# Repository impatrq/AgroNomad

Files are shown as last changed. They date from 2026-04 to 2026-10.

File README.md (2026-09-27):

<div align="center">
    
# [AgroNomad](https://linktr.ee/agronomad2026)

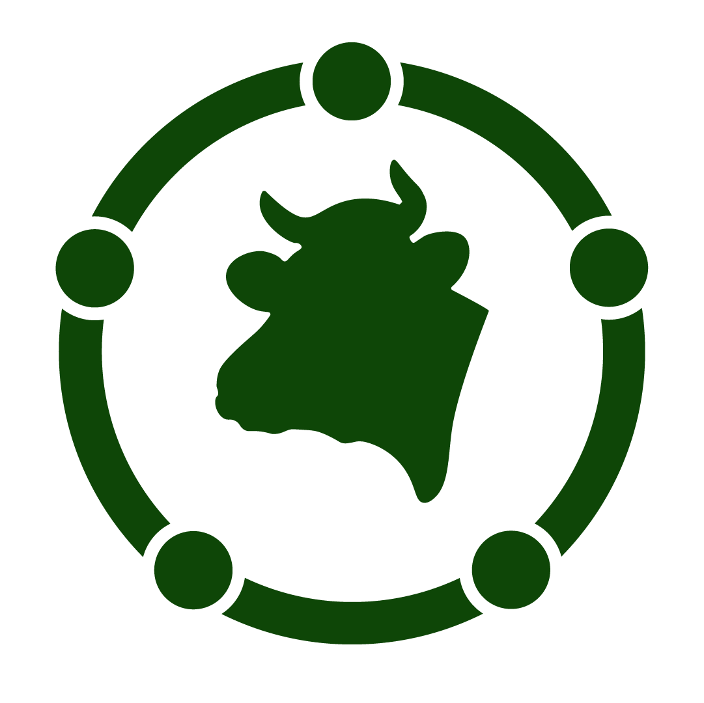
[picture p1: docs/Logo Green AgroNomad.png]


&nbsp;

| Página web | Email | Instagram | Tiktok |
|---|---|---|---|
|[AgroNomad Page](https://agro-nomad-page.vercel.app)|nomadbusiness2026@gmail.com|[@proyecto.agronomad](https://www.instagram.com/proyecto.agronomad/)|[@proyecto.agronomad](https://www.tiktok.com/@proyecto.agronomad)|

### MONITOREO INTELIGENTE DE GANADO 

AgroNomad es un sistema de monitoreo inteligente de ganado que combina collares smart, sensores, posicionamiento GPS y comunicación LoRa para obtener información de los animales directamente desde el campo.

El sistema está compuesto por collares inteligentes, una estación de recepción fija y una interfaz de usuario que permite visualizar y gestionar la información obtenida.

---

## Objetivo

Desarrollar un sistema IoT que permita realizar el seguimiento remoto del ganado, obteniendo información sobre su ubicación, movimiento y diferentes parámetros del animal, y centralizando estos datos en una estación de control.

---

## Componentes del Proyecto  

### AgroNeck

Collar inteligente colocado en el animal.

Se encarga de adquirir y procesar la información proveniente de los sensores y transmitirla mediante LoRa hacia el AgroBot.

### AgroBot

Estación de recepción fija del sistema.

Recibe la información enviada por los AgroNeck y funciona como centro de control para los animales monitoreados.

### AgroServer

Interfaz de usuario del sistema.

Permite visualizar y gestionar la información recibida desde los AgroNeck a través del AgroBot.

---

## Estructura del Proyecto  
**docs/** Documentación e Informes del Proyecto  
**firmware/** Código de los Microcontroladores  
**hardware/** Esquemáticos y PCB  
**mechanical/** Diseños 3D  
**web/** Landing Page del Proyecto  

---

### AgroNeck  
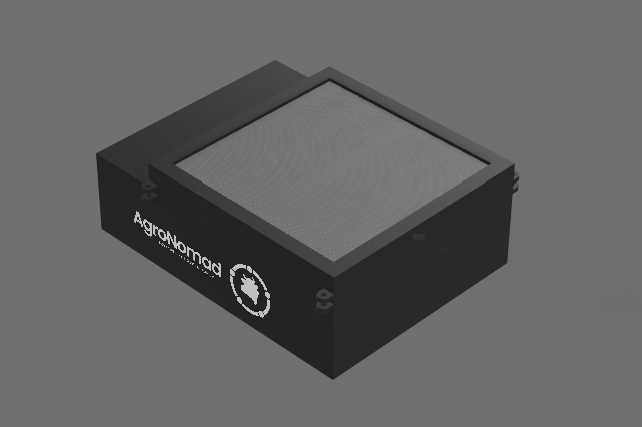
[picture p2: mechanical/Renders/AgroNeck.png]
AgroNeck


### AgroBot
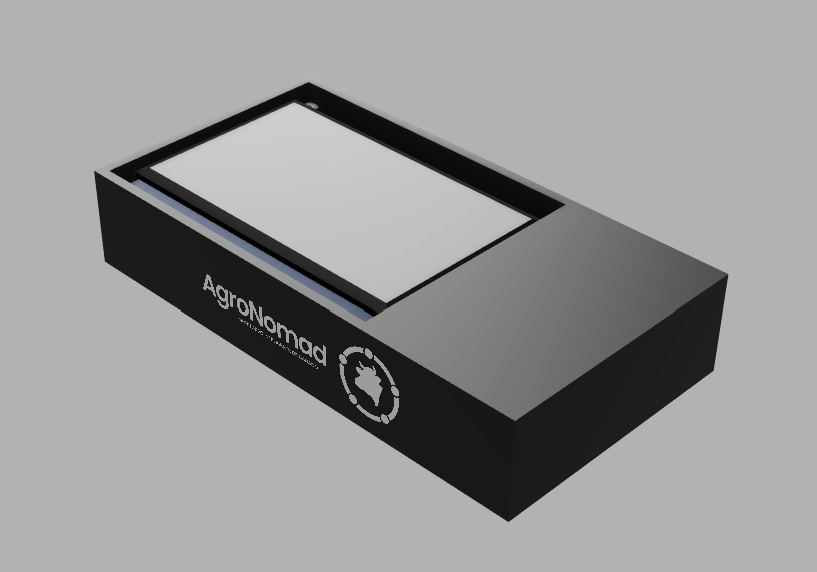
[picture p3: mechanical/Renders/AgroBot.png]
AgroBot


---

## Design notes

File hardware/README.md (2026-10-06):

# hardware
Diseños electrónicos del ecosistema AgroNomad desarrollados en KiCad.

---

### Estructura del Proyecto
**AgroBot/** Estación de recepción fija con Raspberry Pi Zero 2W  
**Cortex/** Placa principal del AgroNeck con ESP32  
**LoraShield/** Módulo adaptador de Lora SMD a THT  
**MLXModule/** Placa de soporte del Sensor de Temperatura MLX90614  
**MOSFETAdapter/** Mini adaptador diseñado para convertir MOSFETs SMD a THT
**Solaria/** Placa de Alimentación Solar y Gestión Energética  

---

## AgroBot

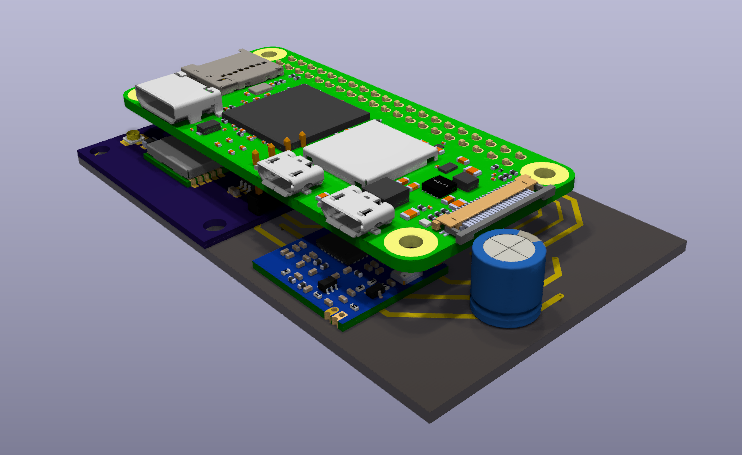
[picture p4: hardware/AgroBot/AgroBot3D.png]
Agrobot


## Cortex

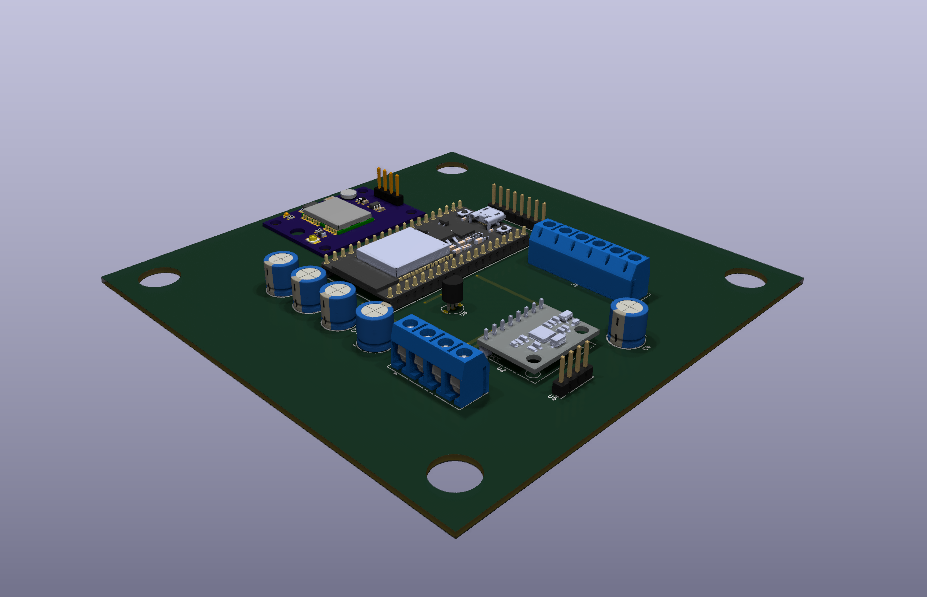
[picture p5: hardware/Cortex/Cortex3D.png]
Cortex


## LoraShield

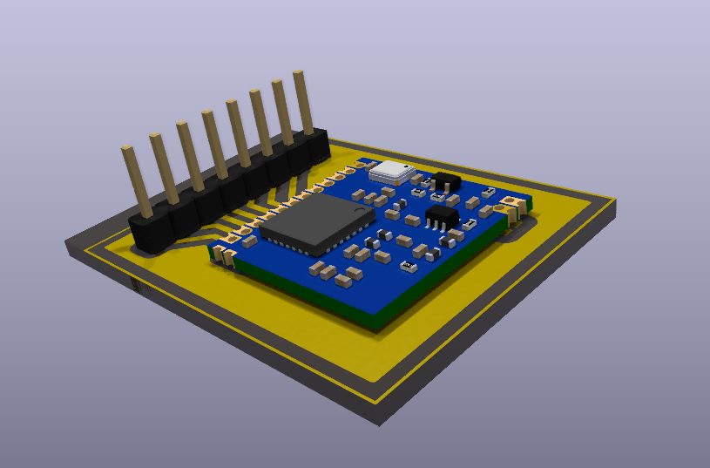
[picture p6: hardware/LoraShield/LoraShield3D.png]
LoraShield


## MLXModule

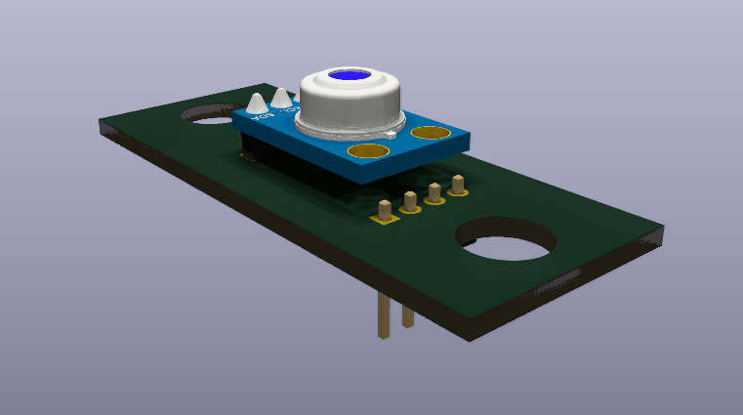
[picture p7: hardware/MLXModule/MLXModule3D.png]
MLXModule


## Solaria

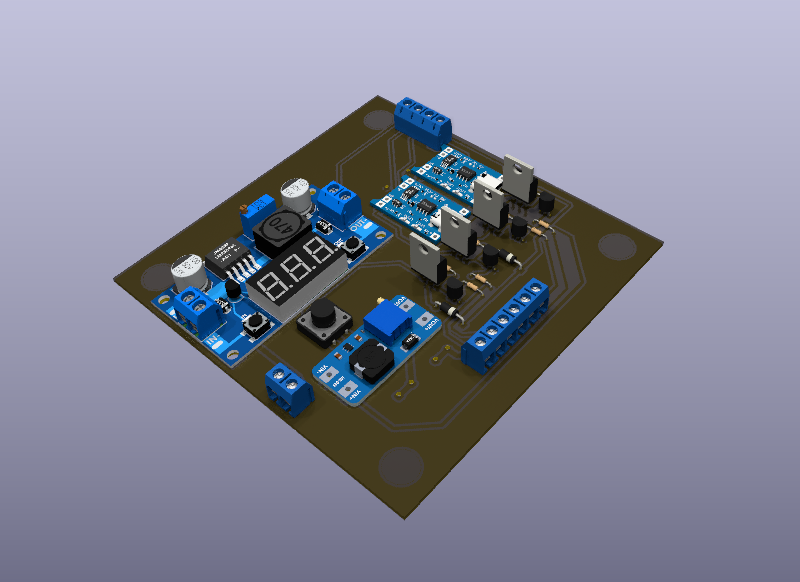
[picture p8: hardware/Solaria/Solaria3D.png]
Solaria


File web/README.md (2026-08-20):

# AgroNomad Web

Landing Page oficial del proyecto AgroNomad.  
Sitio web: https://agro-nomad-page.vercel.app/  

---

### Características

- Presentación del proyecto.
- Descripción del ecosistema AgroNomad.
- Información sobre AgroNeck, AgroBot y AgroServer.
- Integración de redes sociales.

---

## Preview de la Pagina

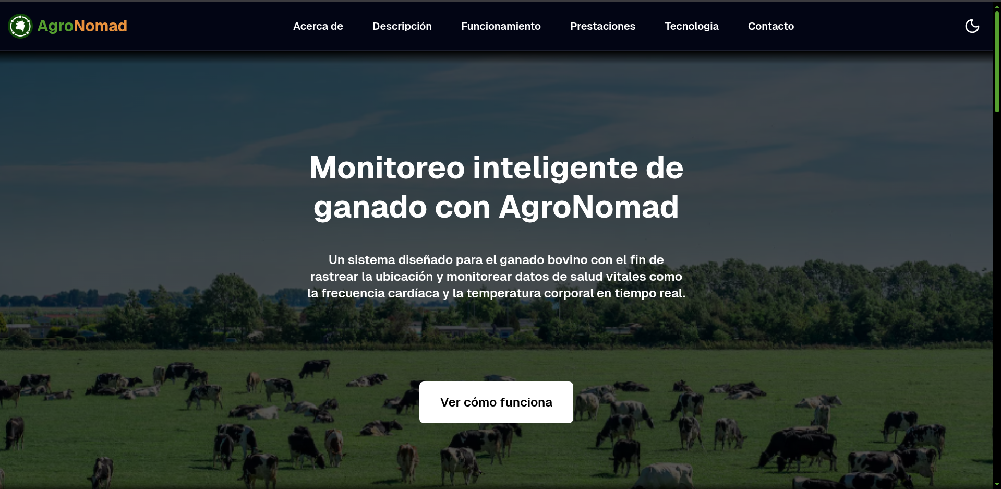
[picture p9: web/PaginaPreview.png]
PaginaWeb
    

---

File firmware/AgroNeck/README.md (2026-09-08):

> AgroNomad 2026

# AgroNeckCode

Código del AgroNeck para la ESP32. Incluye librerías para:

- LoRa
- GPS
- MPU6050
- MLX90614
- LM35

## Funcionando:

- Comunicacion con MPU6050(Aceletometro y giroscopo) y MLX90614(Sensor Temp. Interna). 

- Lectura Sensor LM35

- Comunicacion GPS. 

- Comunicacion LoRA. 

## Pendientes:

-Switcheo de Mosfets entre carga y alimentación

## Luego de realizar Pendientes:

- Buscar un metodo de encriptacion para enviar la informacion de forma segura.

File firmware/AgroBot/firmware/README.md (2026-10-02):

# AgroNomad - Ejemplo de Firmware

Esta carpeta contiene un simulador TCP para pruebas de escritorio y un receptor LoRa para la Raspberry Pi Zero 2 W del AgroBot. El receptor usa el SX1278 de la placa y reenvía la telemetría recibida al backend local.

Este código no es todavía el firmware final de los AgroNeck. Los valores utilizados son fijos y representan los datos que, en una implementación real, deberían obtenerse desde los sensores y el receptor de comunicación del dispositivo.

## Información enviada

Cada mensaje representa una lectura de un AgroNeck e incluye:

- `ID`: identificador único del dispositivo.
- `FIRMWARE_VERS`: versión del firmware.
- `HARDWARE_VERS`: versión del hardware.
- `LAT`: latitud GPS.
- `LONG`: longitud GPS.
- `TEMP`: temperatura registrada.

Ejemplo del formato esperado:

```json
{
  "ID": "COLLAR-01",
  "FIRMWARE_VERS": "1.0",
  "HARDWARE_VERS": "1.0",
  "LAT": -34.707652,
  "LONG": -58.242300,
  "TEMP": "38.4"
}
```

## Simulador TCP de escritorio

La compilación GCC habitual conserva el comportamiento de simulación: se conecta al backend por TCP, envía JSON de ejemplo cada cinco segundos e intenta reconectarse si falla.

## Funciones principales

| Función | Responsabilidad |
|---|---|
| `tcp_connect()` | Crea el socket y establece la conexión con el servidor TCP. |
| `tcp_send()` | Garantiza el envío de todos los bytes del mensaje. |
| `send_collar_data()` | Construye el mensaje JSON con los datos del AgroNeck y lo envía. |
| `main()` | Coordina la conexión, los envíos periódicos y la reconexión. |

## Configuración

En `main.c` se encuentran los valores de conexión:

```c
#define SERVER_IP   "127.0.0.1"
#define SERVER_PORT 4001
```

`SERVER_IP` debe apuntar al equipo donde se ejecuta el servidor y `SERVER_PORT` debe coincidir con el puerto TCP configurado en el backend. Para una prueba local, `127.0.0.1:4001` es la configuración predeterminada.

## Receptor LoRa en Raspberry Pi

El receptor inicializa el SX1278 en recepción continua a 915 MHz, detecta `DIO0`, decodifica la estructura binaria de 14 bytes del AgroNeck y envía el resultado como JSON al backend TCP en `127.0.0.1:4001`.

El mapeo del PCB al header de la Raspberry es:

| Señal SX1278 | GPIO BCM | Pin físico |
|---|---:|---:|
| `MOSI` | 10 | 19 |
| `MISO` | 9 | 21 |
| `SCLK` | 11 | 23 |
| `CS` | 8 | 24 |
| `RESET` | 25 | 22 |
| `DIO0` | 24 | 18 |

La imagen de montaje muestra la Raspberry invertida respecto a la orientación real; el mapeo anterior sigue las redes del PCB y no depende de cómo se vea la foto.

Habilitá SPI en Raspberry Pi OS y compilá ambos ejecutables con:

```bash
cd firmware/AgroBot/firmware
cmake -S . -B build
cmake --build build
sudo ./build/agrobot-lora-receiver
```

El backend debe estar levantado en la Raspberry antes del receptor. `sudo` permite acceder a `/dev/spidev0.0` y `/dev/gpiochip0`; también se pueden configurar los grupos/permisos del usuario para evitarlo. El AgroNeck y el AgroBot deben usar la misma frecuencia y configuración LoRa.

## Compilación y ejecución

Para compilar el simulador TCP:

```bash
gcc main.c -o agro-neck-example
./agro-neck-example
```

Antes de ejecutarlo, el servidor backend debe estar iniciado y escuchando en el puerto TCP configurado.

## Limitaciones actuales

- El simulador sigue usando datos GPS y temperatura de prueba.
- El receptor reenvía la telemetría al backend, pero la recepción de radio debe validarse en el hardware conectado.
- Consultá `../Setup.md` para los pasos de instalación y prueba de extremo a extremo.

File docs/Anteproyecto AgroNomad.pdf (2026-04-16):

Escuela de Educación Técnica Nº7
Taller Regional Quilmes
Prácticas Profesionalizantes: Especialidad Aviónica

# AgroNomad

## Servicio de red portátil para la administración del ganado

## Título del proyecto:

Hemos elegido el nombre AgroNomad porque fusiona nuestra área de enfoque, el área agropecuaria y el concepto de nuestro proyecto, una solución portátil y accesible que cumple su propósito aún en constante movimiento.

## Integrantes:

- DELLA TORRE, Joaquín
- GONZALEZ CAMISCIA, Santiago
- ROMERO DOMINGUEZ, Braulio
- VILLEGAS GONZALEZ, Alejandro

## Objetivo del proyecto:

AgroNomad es un servicio enfocado en brindar al sector agropecuario una herramienta que permita facilitar el monitoreo inteligente del ganado bovino. Nuestro proyecto desarrolla un sistema que permite determinar la ubicación en tiempo real del ganado que se encuentre en la estancia.

Por lo tanto, AgroNomad es una solución escalable, autónoma e integral para el monitoreo inteligente del ganado, combinando análisis de datos, tecnologías de bajo consumo y comunicación de largo alcance buscando mejorar la eficiencia productiva y la seguridad dentro del sector ganadero.

A través de una página web provista por la estación de recepción de datos, el usuario puede visualizar el estado actual de salud de cada uno de los animales —tanto temperatura como pulsaciones por minuto— y detectar y notificar anomalías en caso de notar que los datos vitales no estén dentro del rango normal. Además, registra el camino recorrido por los animales durante el día y monitorea que los animales estén dentro del área perteneciente al propietario.

## Utilidades del proyecto:

La ganadería en Argentina representa un 7,5% de las exportaciones y sigue siendo actualmente uno de los sectores productivos más amplios del país. Sin embargo, enfrenta problemáticas críticas como el abigeato —robo del ganado—, que tiene más de 1200 denuncias anuales únicamente en Santa Fe. A pesar de que existen métodos de detección de abigeato actualmente, son sistemas tardíos en donde el daño ya está hecho. Si bien es un delito penado por ley en Argentina y existe registro de muchos casos, no existe alerta temprana que alerte al dueño de los animales que los mismos han salido del territorio de su estancia.

AgroNomad busca brindar una solución preventiva que les otorgue mayor seguridad a los productores ganaderos, ya que pueden acceder a la ubicación de su ganado constantemente, más que nada a aquellos en los que la cantidad de animales que tienen dificulta la capacidad de monitorear a todos al mismo tiempo. No solo resuelve la problemática de ubicar al ganado sino también de poder tener un registro de cada uno, como su estado de salud y reduciendo la necesidad de supervisión física constante.

## Descripción del funcionamiento:

El ecosistema de AgroNomad se compone, principalmente, de collares inteligentes llamados AgroNeck que se les colocará a los animales que sean parte de la estancia. Estos dispositivos son diseñados para monitorear parámetros fundamentales como el comportamiento del ganado.

Cada collar se encarga de medir las pulsaciones del animal mediante un micrófono MEMS en contacto con el collar que, junto a la implementación de un acelerómetro de 3 ejes, permitirá detectar si el animal está sufriendo alguna anomalía en su comportamiento y determinando si está en estado de reposo o en movimiento. Para detectar si las pulsaciones detectadas por el sensor son los latidos del corazón y no son vibraciones generadas por otras situaciones como por ejemplo, masticar o caminar, los collares poseerán un algoritmo entrenado previamente para cumplir ese propósito.

A través de dos sensores térmicos integrados en el collar se medirá la temperatura del ambiente y la que posee la piel del animal. Un algoritmo definido por la fórmula de equilibrio térmico recibe estas mediciones y permite estimar la temperatura interna del animal.

Un módulo GPS NEO6MV2 será el encargado de recopilar la posición actual del animal y será de ayuda para determinar el recorrido del mismo durante un ciclo diario.

Los datos recopilados irán al microcontrolador ESP32, que será encargado de procesar la información de los sensores. Luego, los enviará mediante un módulo de telecomunicaciones LoRa al AgroBot —estación de recepción de datos— que será instalado donde el propietario esté interesado en conocer los datos del ganado. Además, los collares serán nodos dentro de una red. Se reenviarán información entre sí permitiendo, de esta manera, que si un collar no se encuentra dentro del alcance directo del AgroBot, otro collar cercano actúe como intermediario ampliando la cobertura total de la red.

Los collares contarán con un pequeño panel solar conectado en la parte superior del collar que permitirá disponer de autonomía energética junto a las cuatro baterías de litio.

El AgroBot será una estación fija de recepción que emplea un microcontrolador Raspberry Pi Zero 2W y un módulo LoRa para recibir la información. Además incluirá una pantalla LCD táctil que funcionará como dashboard.

La página web del AgroServer —que, en zonas sin cobertura, es una red wifi local autónoma generada por la Raspberry Pi Zero 2W— permite asignar a los collares un perfil del animal donde se puede cargar —en caso de ser necesario— el nombre, la edad, el tipo de ganado, el estado de sus vacunas y cualquier otro dato necesario. En la página web del AgroServer se podrá visualizar el mapeo del área donde puede permanecer el ganado. Se permitirá seleccionar a cualquier animal en específico y se cargará su perfil como también el estado actual de sus pulsaciones y temperatura. Contará con opciones para revisar las distancias recorridas por los animales y un sistema de alerta cuando no se detecta dentro del rango a uno de los collares.

## Análisis de factibilidad:

Electrónica y diseño de PCB: Se deben diseñar circuitos de tipo PCB para integrar todos los sistemas que van a incluir tanto los AgroNecks como los AgroBots. Los que realizarán los circuitos esquemáticos, los PCBs y la posterior impresión y agujerado serán Joaquín Della Torre y Braulio Romero Domínguez. Santiago

Gonzalez Camiscia estará a cargo del soldado y revisión de funcionamiento de los componentes.

Integración del Software: Para el desarrollo correcto de esta tarea, necesitaremos que todos los miembros del equipo trabajen comunicados entre sí. De esta manera, nos garantizamos que el software integre todos los sistemas y pueda funcionar correctamente en conjunto. Una de las principales tareas del software será establecer la comunicación entre los AgroNecks y el AgroBot y que los datos puedan ser correctamente explayados en el AgroServer.

Desarrollo de AgroServer: Se deberá diseñar la página web con la correcta visualización de los parámetros principales y la accesibilidad de la interfaz. También su integración a la pantalla táctil del AgroBot. Este será un trabajo de Joaquín Della Torre.

Sistema de alimentación solar: La problemática de la autonomía energética la solucionamos implementando un sistema de alimentación a través de baterías recargadas mediante energía solar. El desarrollo de este sistema lo harán Alejandro Villegas Gonzalez y Braulio Romero Dominguez.

Ubicación en tiempo real: Para poder guardar un registro del movimiento de los animales durante el día y determinar su posición como también verificar si está en el rango definido de la estancia, será necesario desarrollar un sistema de ubicación precisa en tiempo real. Esta tarea estará a cargo de Santiago Gonzalez Camiscia y Alejandro Villegas Gonzalez.

Diseño y armado físico de AgroNomad: El desarrollo de los AgroNecks presenta un desafío importante que es el de contar con todos los sistemas descritos anteriormente y a la vez ser cómodo para que los animales no sufran estrés. El diseño de los mismos debe permitir que sean funcionales, ergonómicos y fáciles de colocar. Por su parte el AgroBot debe desarrollarse teniendo en cuenta sus sistemas y que se puedan obtener correctamente los datos. Esta tarea de diseño estará a cargo de Braulio Romero Dominguez.

Sistema de medición de pulso: Será necesario desarrollar un sistema basado en un micrófono MEMS que permita sensar el pulso, como también el entrenamiento del algoritmo necesario para la filtración de otras vibraciones. Este sistema será desarrollado por Santiago Gonzalez Camiscia y Braulio Romero Dominguez

Algoritmo de temperatura: AgroNomad requiere también un sistema que sea capaz de medir la temperatura exterior y la de la superficie de los animales y utilizar estos datos para calcular la temperatura interna. El desarrollo del mismo está a cargo de Alejandro Villegas Gonzalez.

Marketing y Redes Sociales: Los encargados del branding de la marca y su representación en redes sociales serán Alejandro Villegas Gonzalez y Braulio

Romero Dominguez. Su tarea también será contactar con empresas, posibles patrocinadores y exteriorizar el proyecto.

También será responsabilidad de todo el equipo verificar que los módulos y/o componentes a utilizar funcionen de manera correcta, puedan ser integrados con el software y cumplan con las medidas de seguridad para que no sucedan incidentes.

El equipo en su conjunto deberá mantener una comunicación continua entre sí para mantener un desarrollo integral del proyecto y verificar que todos los sistemas puedan funcionar a la vez y en conjunto.

El proyecto es técnicamente viable, ya que los sistemas que se desarrollarán poseen tecnologías accesibles, pero tiene que ser realizado con extrema precisión, ya que su funcionamiento no debe poner en riesgo la integridad física y psicológica del animal.

## Costo del proyecto:

Componentes:

- Raspberry Pi Zero 2w (31,41$USD)

https://www.siranet.com.ar/productos/raspberry-pi-zero-2w/

- LCD Touch 5” HDMI Raspberry Pi (51,97$USD)

https://www.mercadolibre.com.ar/lcd-touch-5-hdmi-raspberry-pi-pantalla-tactil-beaglebone/p/MLA2045601485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 (https://www.mercadolibre.com.ar/lcd-touch-5-hdmi-raspberry-pi-pantalla-tactil-beaglebone/p/MLA2045601485)

- ESP32 DevKit V1 (12,85$USD)

https://tienda.starware.com.ar/producto/placa-wifi-iot-nodemcu-esp-wroom-32-devkit-v1/ (https://tienda.starware.com.ar/producto/placa-wifi-iot-nodemcu-esp-wroom-32-devkit-v1/)

- x2 Módulo Lora SX1278 (16,84$USD)

https://www.todomicro.com.ar/comunicacion/910-modulorf-lora-sx1278-chip-p m1280-con-antena.html (https://www.todomicro.com.ar/comunicacion/910-modulorf-lora-sx1278-chip-pm1280-con-antena.html)

- Módulo GPS NEO6MV2 (4,73$USD)

https://www.todomicro.com.ar/ARDUINO/339-modulo-gps-gy-neo6mv2-con-a ntena.html (https://www.todomicro.com.ar/ARDUINO/339-modulo-gps-gy-neo6mv2-con-antena.html)

- Acelerómetro MPU-6050 (2,65$USD)

https://www.todomicro.com.ar/sensores/176-acelerometro-y-giroscopio-mpu-6 050.html (https://www.todomicro.com.ar/sensores/176-acelerometro-y-giroscopio-mpu-6050.html)

- Sensor de Temperatura MLX90614 (13,73$USD)

https://tienda.starware.com.ar/producto/sensor-de-temperatura-arduino-compatible-gy-906-mlx90614-baa-termometro-infrarrojo/ (https://tienda.starware.com.ar/producto/sensor-de-temperatura-arduino-compatible-gy-906-mlx90614-baa-termometro-infrarrojo/)

- Sensor de Temperatura LM35 (1,99$USD)

https://www.nubbeo.com.ar/productos/sensor-analogico-temperatura-lm35-0c-a-100c-nubbeo/ (https://www.nubbeo.com.ar/productos/sensor-analogico-temperatura-lm35-0c-a-100c-nubbeo/)

- Micrófono MEMS (10,84$USD)

https://www.mercadolibre.com.ar/inmp441-microfono-omnidireccional-interfaz-i2s-inmp441-mems/p/MLA2058636482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 (https://www.mercadolibre.com.ar/inmp441-microfono-omnidireccional-interfaz-i2s-inmp441-mems/p/MLA2058636482)

- Panel Solar 5W (15,96$USD)

https://www.mercadolibre.com.ar/d-cargador-solar-para-camping-con-entrada-tipo-c-w/p/MLA2058280905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 (https://www.mercadolibre.com.ar/d-cargador-solar-para-camping-con-entrada-tipo-c-w/p/MLA2058280905)

- Regulador Step-Down TPS54260 (3,5$USD)

https://www.mercadolibre.com.ar/54260-tps54260-tps54260dgqr-ti-54260-s4260-original-texas/up/MLAU267269638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 (https://www.mercadolibre.com.ar/54260-tps54260-tps54260dgqr-ti-54260-s4260-original-texas/up/MLAU267269638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)

- 4x Bobinas SMD 220uH (10,84$USD)

https://www.mercadolibre.com.ar/inductor-bobina-220-micro-h-smd-potencia-221-12x12x7-mm-17a/up/MLAU312652544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 (https://www.mercadolibre.com.ar/inductor-bobina-220-micro-h-smd-potencia-221-12x12x7-mm-17a/up/MLAU312652544)

- 4x Mosfet IRFZ44N (4,24$USD)

https://www.mercadolibre.com.ar/10-unidades-irfz44n-transistor-mosfet-irfz-44-49a-55v-to220/up/MLAU135565280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 (https://www.mercadolibre.com.ar/10-unidades-irfz44n-transistor-mosfet-irfz-44-49a-55v-to220/up/MLAU135565280)

- 4x Transistores BJT 2N3904 (6,52$USD)

https://www.mercadolibre.com.ar/2n2219a-transistor--08a-75v-ft-300mhz-altern-2n2222a-2n2219/up/MLAU298312241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 (https://www.mercadolibre.com.ar/2n2219a-transistor--08a-75v-ft-300mhz-altern-2n2222a-2n2219/up/MLAU298312241)

arch_layout=grid&position=2&type=product&tracking_id=9ae7a458-33ac-45e 0-ad19-e7b79cd4106f&wid=MLA870238161&sid=search (https://www.mercadolibre.com.ar/2n2219a-transistor--08a-75v-ft-300mhz-altern-2n2222a-2n2219/up/MLAU298312241)

- Diodo Schottky 1N5819 (2,07$USD)

https://www.mercadolibre.com.ar/10-diodos-schottky-1n5819-vishay-40v-1a-do-204ah-alta-frecuencia/p/MLA48092585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 (https://www.mercadolibre.com.ar/10-diodos-schottky-1n5819-vishay-40v-1a-do-204ah-alta-frecuencia/p/MLA48092585)

- Collar de BioCuero (12,92$USD)

https://oymindumentaria.com/productos/cinturon-de-vestir-clasico-eco-cuero/

- x1kg Filamento PLA para Impresora 3D (16,26$USD)

https://printalot.com.ar/productos/filamentos/pla/pla-negro/

Costo por AgroNeck: 103,14$USD

Costo del AgroBot: 84,44$USD

Costo total del proyecto: 171,62$USD

Referencias de páginas de búsqueda:

https://www.todomicro.com.ar/

https://www.mercadolibre.com.ar/

https://tienda.starware.com.ar/

https://www.nubbeo.com.ar/

## Análisis de costo/beneficio:

AgroNomad es una herramienta que busca ofrecer un servicio económico para el sector agropecuario, de una inversión inicial única y sin costos de suscripción mensuales a diferencia de las alternativas disponibles del mercado.

La inversión de 103 USD por collar y de 84 USD para la estación de recepción de datos se justifica con el monitoreo constante que permite realizar. Ante la posibilidad de acceder en tiempo real a la ubicación y el estado de salud de cada animal, se puede optimizar significativamente el tiempo de trabajo reduciendo la necesidad de hacer recorridos físicos extensos dentro del campo. Esto también permite una mayor seguridad del ganado al detectar tempranamente situaciones de riesgo como abigeato o anomalías en los parámetros fisiológicos.

Si analizamos otras soluciones existentes, la mayoría suelen incluir el uso de drones o plataformas con suscripciones mensuales. AgroNomad ofrece una alternativa más económica y autónoma. Las demás opciones suelen requerir costos iniciales elevados o gastos periódicos que dificultan su adopción a largo plazo.

En un campo de 50 animales, si consideramos una vida útil estimada de 5 años, AgroNomad requiere una inversión única de 5234 USD, frente a sistemas basados en suscripciones que, si consideramos una suscripción mensual de 3 USD por animal, implicaría un gasto de 9000 USD en el mismo período. Esto representa una reducción de costos de más del 40%, y elimina la dependencia de otros dispositivos. Para productores que no generen producciones a gran escala, esto es un ahorro significativo.

AgroNomad, por su parte, elimina la dependencia de servicios externos ya que en caso de no poseer internet, genera una red local propia garantizando su funcionamiento aún en zonas sin cobertura. De esta manera, al realizar la inversión inicial, el sistema ya puede operar de manera continua sin generar costos adicionales significativos.

## Diagramas en bloques del prototipo:

## Diagrama electrónico Agro Neck:

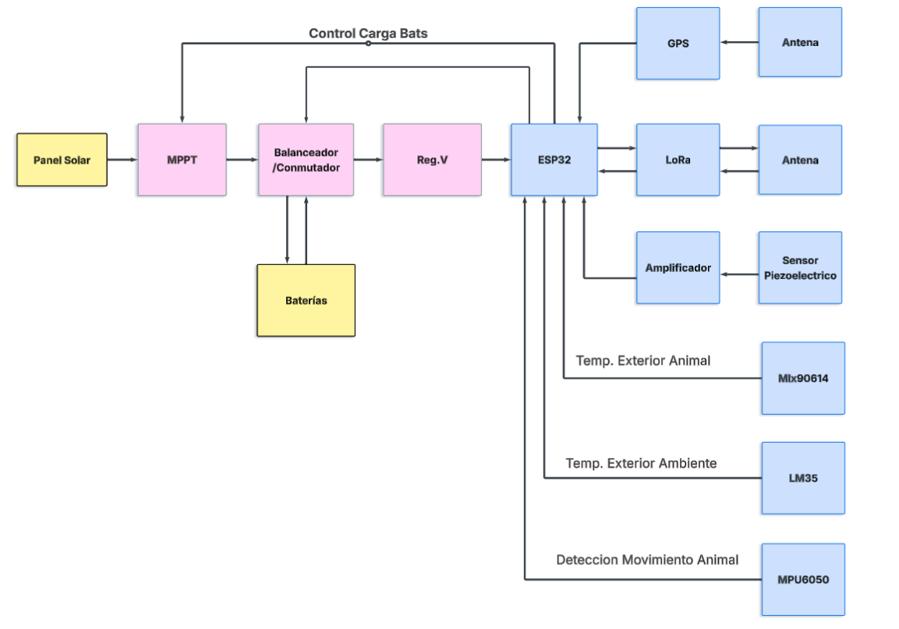
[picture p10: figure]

Panel Solar / MPPT: Se diseñará un circuito sencillo pero a la vez funcional, que permita obtener eficientemente la energía del panel solar instalado sobre el AgroNeck, y entregar todo el tiempo la tensión y corriente necesaria para realizar la carga de las baterías de litio, gracias a la red de retroalimentación que se instalará entre la ESP32 y el bloque conmutador y balanceador que gestiona la carga.

Baterías: Se hará uso de 4 baterías de litio tipo 18650 (3.7V, 2200mAh) para alimentar al AgroNeck, de forma que se encuentre conectadas las 4 independientemente conectadas al módulo Balanceador/Conmutador que junto al ESP32 cumplira funciones de gestión de carga similares a las de un BMS (Battery Management System).

Balanceador/Conmutador: Este módulo electrónico consistirá en un conjunto de transistores BJT que según el control comandado por la ESP32, permitirán realizar la carga y balanceo individual de las cuatro baterías. Este módulo a su vez permitirá elegir qué conjunto de dos baterías en serie alimentará a la ESP32 a través del regulador de tensión.

Regulador de tensión (Reg.V): Se empleará un convertidor Step-Down con el TPS54260 para transformar la tensión proveniente de las baterías a una aceptable para el funcionamiento de la ESP32 y el módulo LoRa(3.3V), para maximizar la eficiencia del consumo energético del dispositivo. Como también se instalará una red de filtro LC y planos de tierra (Ground Planes) para evitar cualquier interferencia que pueda emitir el módulo de fuente Step-Down hacia el módulo LoRa y GPS.

ESP32: Este Microcontrolador se encargará de emplear toda la lógica tanto de la carga de baterías por medio del sistema MPPT (Maximum Power Point Tracking) y el módulo Balanceador/Conmutador, como también la lógica de comunicación y recolección de datos de los sensores de temperatura y de medición de pulsos integrados dentro del collar.

GPS: Se hará uso del módulo NEO6MV2, para la geolocalización de cada NomadNeck —o sea, del animal— físicamente dentro de la red y así poder armar un mapa con la posición de cada uno en la aplicación web.

LoRa/Antena: Este apartado será el encargado de realizar la recepción y transferencia de información de cada NomadNeck, por cada NomadNeck se enviaran datos de pulsaciones cardiacas del animal, su temperatura corporal actual y posición geológica.

MLX90614: Es el sensor de temperatura infrarrojo que se encarga de sensar la temperatura que irradia la piel del animal.

LM35: Este segundo sensor de temperatura se encarga de sensar la temperatura ambiente del exterior, y así junto al dato previo del sensor infrarrojo es posible calcular la temperatura interna del animal.

MPU6050: Se encargará de detectar cuando el animal se encuentra en movimiento, o en qué posición se encuentra, lo que permitirá saber si su estado vital es el normal para la actividad que el animal realiza o si presenta alteraciones en su comportamiento.

## Diagrama Electronico AgroServer:

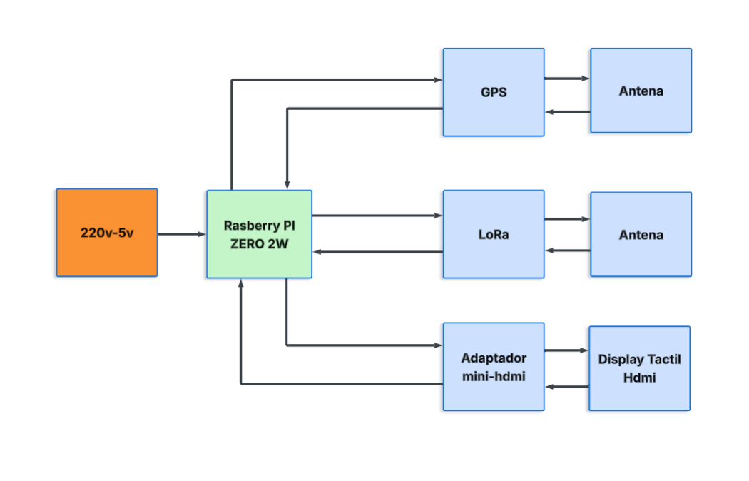
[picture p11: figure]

GPS: Es necesario implementar a su vez un módulo GPS NEO6MV2 mismo al del Agro Neck dentro del Agro Server, ya que esto nos permite la localización del mismo dentro de la red y así poder definir adecuadamente cual es el área física a respetar para una circulación normal de los animales. Significando que fuera de esta área, el animal estaría “escapando” y se alertará inmediatamente.

LoRa: Se utilizará para poder recibir toda la información de cada AgroNeck y si a su vez es necesario enviar información a estos.

Display Tactil Hdmi: Esta pantalla permite al empleador del campo, tener una conexión directa con el servidor web y página web en caso de no disponer de cualquier otro dispositivo como un celular o computadora para hacerlo.

Raspberry Pi Zero 2w: Se hará uso de este microcontrolador ya que dispone de un salida mini hdmi que nos permite conectar una display táctil de buenas prestaciones, como también la capacidad albergar un servidor web en el cual funcionará nuestra aplicación web de monitoreo. El mismo será desplegado en la red wifi local de la cual el empleador disponga, aunque en caso de no disponer de una red que proporcione internet al AgroBot, se creará una red wifi local por medio del microcontrolador para poder hospedar este servidor.

A su vez este microcontrolador se encargará de mantener en funcionamiento un modelo de análisis de datos, encargado de analizar el comportamiento de los animales —temperatura, pulsaciones y camino recorrido— para poder deducir si estos animales poseen alteraciones en su salud.

## Diagrama de tiempo de desarrollo:

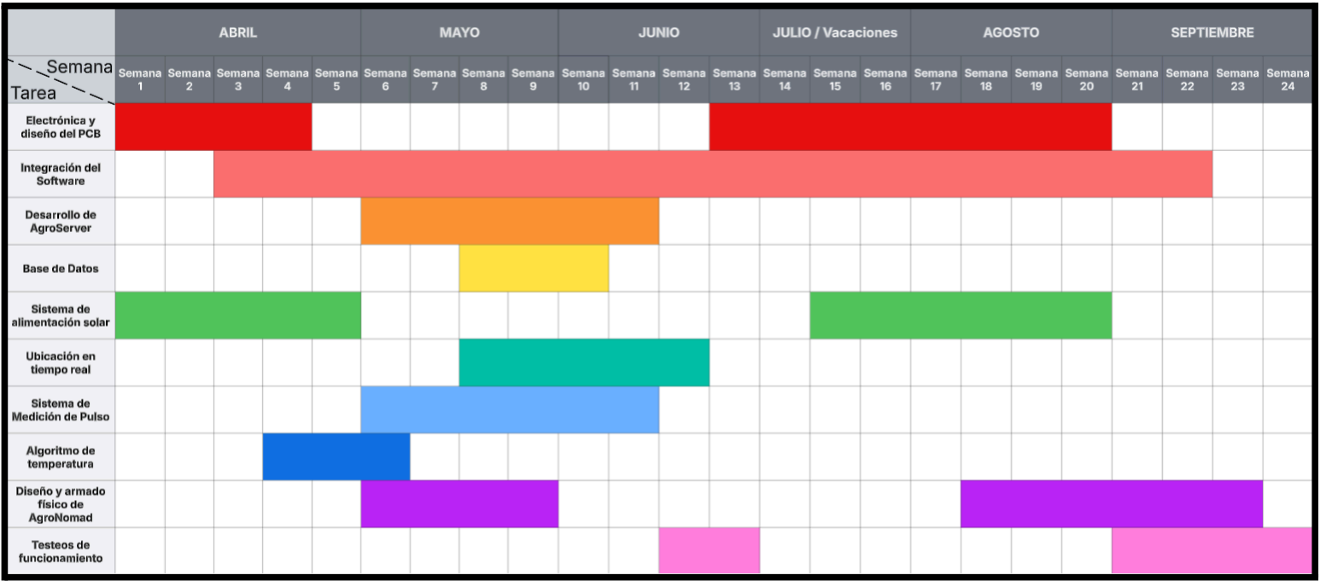
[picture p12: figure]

## Referencias conceptuales:

- ¿Qué es el gps para ganado y sus principales beneficios? -https://zeekgps.com/que-es-el-gps-para-ganado-y-sus-principales-beneficios/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,del%20animal%20en%20tie mpo%20real (https://zeekgps.com/que-es-el-gps-para-ganado-y-sus-principales-beneficios/)
- Collar inteligente para vacas de ganadería extensiva -https://innogando.com/rumi-carne/
- ¿Se le pierden sus vacas en la finca? Estas tecnologías podrían ayudarle a localizarlas -
https://www.contextoganadero.com/tendencias/se-le-pierden-sus-vacas-en-la-finca-estas-tecnologias-podrian-ayudarle-a-localizarlas (https://www.contextoganadero.com/tendencias/se-le-pierden-sus-vacas-en-la-finca-estas-tecnologias-podrian-ayudarle-a-localizarlas)
- Desarrollan un GPS para ubicar las vacas perdidas -https://www.revistachacra.com.ar/informacion-tecnica/18864/
- Sistema circulatorio de cabeza -https://www.anato.cl/00012%20comunidadanato/DraCBorroni/UDM/Morfologia/Clase_10_circulacion_cabeza.pdf (https://www.anato.cl/00012%20comunidadanato/DraCBorroni/UDM/Morfologia/Clase_10_circulacion_cabeza.pdf)
- Equilibrio térmico - https://www.significados.com/que-es-equilibrio-termico/
- El aporte de la ganadería a la economía argentina -https://www.bcr.com.ar/es/mercados/investigacion-y-desarrollo/informativo-semanal/noticias-informativo-semanal/el-aporte-de-4 (https://www.bcr.com.ar/es/mercados/investigacion-y-desarrollo/informativo-semanal/noticias-informativo-semanal/el-aporte-de-4)
- El abigeato sigue siendo un flagelo -https://www.lavozdesanjusto.com.ar/el-abigeato-sigue-siendo-un-flagelo
- “Con los análisis genéticos el robo de ganado ha disminuido drásticamente” -https://www.argenbio.org/novedades/71-mas-novedades/mas-novedades-argentina/9361-%E2%80%9CCon-los-an%C3%A1lisis-gen%C3%A9ticos-el-robo -de-ganado-ha-disminuido-dr%C3%A1sticamente%E2%80%9D (https://www.argenbio.org/novedades/71-mas-novedades/mas-novedades-argentina/9361-%E2%80%9CCon-los-an%C3%A1lisis-gen%C3%A9ticos-el-robo-de-ganado-ha-disminuido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)
- Condena por abigeato -
https://www.juscorrientes.gov.ar/sin-categoria/condenan-a-dos-hombres-a-4-anos-y-6-meses-de-prision-por-abigeato-agravado/ (https://www.juscorrientes.gov.ar/sin-categoria/condenan-a-dos-hombres-a-4-anos-y-6-meses-de-prision-por-abigeato-agravado/)

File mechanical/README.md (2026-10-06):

# mechanical
Modelos 3D de las carcasas desarrolladas para el AgroNeck y el AgroBot.

---

### Estructura del Proyecto
**renders/** Imágenes de renderizados de las carcasas y ensamblajes  
**step/** Archivos CAD del tipo STEP de las carcasas del AgroNeck y AgroBot

---

### AgroNeck  
AgroNeck

### AgroBot
AgroBot

---

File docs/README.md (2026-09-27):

# Documentación — AgroNomad

Documentación oficial del proyecto AgroNomad con informes, carpetas y presentaciones que respaldan al mismo.

---

## Estructura del Directorio

El contenido de esta carpeta está organizado de la siguiente manera:

```text
docs/
├── ONIET/
│   ├── Informe_de_Presentación_AgroNomad.pdf   # Informe descriptivo para la categoría Prototipos - Eje Libre
│   ├── Presentación_ONIET_AgroNomad.pdf        # Presentación para la categoría Prototipos - Eje Libre
│   └── Informe_First_Plan_AgroNomad.pdf        # Informe descriptivo para la categoría First Plan
├── Presentaciones/                             # Presentaciones de exposiciones realizadas
├── Anteproyecto_AgroNomad.pdf                  # Documento del anteproyecto
├── Carpeta_de_Campo_AgroNomad.pdf              # Bitácora de campo
└── README.md

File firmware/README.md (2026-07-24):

# firmware
Este incluye el código que compone a los microcontroladores del AgroNeck y del AgroBot.

---

### Estructura del Proyecto
**AgroNeck/** Código del collar smart en campo que incluye alimentación solar, ubicación, pulso y transmisión de datos.  
**AgroBot/** Código de la estación fija de recepción de datos que incluye la presentación de los mismos en una interfaz en un Display LCD Touch.  

---

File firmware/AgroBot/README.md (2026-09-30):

# AgroBotApp

## 1. Objetivo

El código del AgroBot recibe datos desde los AgroNeck, los guarda en PostgreSQL con PostGIS y los muestra en un dashboard web. Este código tiene implementado la recepción de posiciones, el almacenamiento de animales y campos, la visualización en un mapa y el cambio de nombre de los animales. Algunas funciones descriptas en el todavía están planificadas, pero no implementadas.

## 2. Arquitectura general

```text
Collar / main.c
    |
    | JSON por TCP, puerto 4001
    v
server/server.js
    |
    | upsertAnimalSnapshot()
    v
PostgreSQL + PostGIS
    |
    | API HTTP, puerto 4000
    v
Frontend React + Leaflet
```

### Componentes principales

|Componente|Responsabilidad|
|---|---|
| `firmware_example/main.c`| Simula un collar que envia datos por TCP.|
|-----|-----|
| `server/server.js`| Recibe TCP, procesa mensajes y expone la API HTTP.|
| `server/db/index.js`| Conecta con PostgreSQL y ejecuta las operaciones de base de datos.|
| `server/utils/utils.js`| Normaliza payloads y extrae objetos JSON recibidos por TCP.| 
| `server/db/schema.sql`| Define tablas, relaciones e indices de PostgreSQL/PostGIS.|
|-----|-----|
| `client/src/App.jsx`| Controla la navegacion basica del frontend.|
| `client/src/pages/Home.jsx`| Muestra el mapa, los animales y los limites de los campos.|
| `client/src/pages/Login.jsx`| Muestra un formulario de login, actualmente incompleto.|
| `client/src/pages/userConfig.jsx`| Pantalla de configuracion de usuario.|

## 3. Flujo completo de datos

1. `main.c` se conecta a `127.0.0.1:4001`.
2. El collar envia un JSON con ID, posicion y temperatura.
3. `createTcpServer()` en `server.js` recibe los bytes.
4. `handleIncomingData()` extrae y parsea los objetos JSON.
5. `normalizeAnimalPayload()` valida y normaliza los nombres de los campos.
6. `upsertAnimalSnapshot()` busca o crea el animal y su dispositivo.
7. La posicion se guarda en `gps_positions` como un punto PostGIS.
8. El frontend consulta `/api/animals` y `/api/yards` por HTTP.
9. `Home.jsx` convierte los datos a marcadores y polilineas de Leaflet.

## 4. Firmware: `firmware_example/main.c`

Este archivo no es todavia el firmware real del collar: es un cliente de prueba que simula el envio de datos.

### Constantes

- `SERVER_IP`: IP del backend TCP, actualmente `127.0.0.1`.
- `SERVER_PORT`: puerto TCP, actualmente `4001`.
- `BUFFER_SIZE`: capacidad del buffer usado para construir el JSON.

### Funciones

#### `tcp_connect()`

Crea un socket IPv4, configura la IP y el puerto del servidor y ejecuta `connect()`. Devuelve el descriptor del socket si tiene exito o `-1` si falla.

#### `tcp_send(sock, data)`

Envia todos los bytes de una cadena. Repite `send()` hasta transmitir el mensaje completo, porque una llamada individual puede enviar solo una parte.

#### `send_collar_data(...)`

Construye un JSON con los datos del collar y lo envia usando `tcp_send()`.

Payload que genera:

```json
{
  "ID": "COLLAR-01",
  "FIRMWARE_VERS": "1.0",
  "HARDWARE_VERS": "1.0",
  "LAT": -34.707652,
  "LONG": -58.242300,
  "TEMP": "38.4",
}
```

El salto de linea al final permite separar mensajes consecutivos.

#### `main()`

1. Abre la conexion TCP.
2. Envia datos iniciales de `COLLAR-01` y `COLLAR-02`.
3. Cada cinco segundos vuelve a enviar datos de `COLLAR-01`.
4. Si el envio falla, cierra el socket e intenta reconectarse.

### Limitacion actual

El programa usa datos fijos. No recibe aun datos reales de LoRa. Ademas, el backend actualmente guarda temperatura y ubicacion, pero no usa correctamente `FIRMWARE_VERS` ni `HARDWARE_VERS` del payload.

## 5. Backend: `server/server.js`

El backend contiene dos servidores independientes:

- TCP para los collares: puerto `4001`.
- HTTP para el frontend: puerto `4000` por defecto.

### Estado en memoria

- `animals`: copia temporal de los animales obtenidos de la base.
- `limitsField`: copia temporal de los limites de los campos.

La base de datos es la fuente persistente. La memoria se refresca desde PostgreSQL.

### Funciones internas

#### `refreshYardState()`

Llama a `listYards()` y actualiza `limitsField`.

#### `refreshAnimalState()`

Llama a `listAnimals()` y actualiza `animals`.

#### `mergeAnimalData(newAnimal)`

Actualiza el animal existente que tenga el mismo ID o agrega uno nuevo a la lista en memoria.

#### `handleIncomingData(rawData)`

Procesa datos recibidos por TCP:

1. Convierte el buffer a texto.
2. Ignora mensajes vacios o que parecen solicitudes HTTP.
3. Extrae objetos JSON mediante `extractJsonObjects()`.
4. Convierte cada objeto con `JSON.parse()`.
5. Normaliza animales.
6. Guarda snapshots en PostgreSQL.
7. Refresca el estado de animales desde la base.

Tambien acepta un array de animales y payloads que contengan limites de campos.

#### `createTcpServer()`

Crea el servidor TCP. Registra conexiones, recibe datos, llama a `handleIncomingData()` y maneja eventos de desconexion y error.

#### `createHttpServer()`

Crea el servidor HTTP y atiende las rutas de la API.

#### `startServer()`

Inicializa todo en este orden:

1. `initializeDatabase()` crea las tablas.
2. `seedSampleData()` crea datos demo si faltan.
3. `refreshAnimalState()` carga animales.
4. `refreshYardState()` carga campos.
5. Inicia los servidores HTTP y TCP.

### API HTTP actual

| Metodo y ruta | Funcion |
|---|---|
| `GET /api/animals` | Refresca y devuelve los animales desde PostgreSQL. |
| `GET /api/yards` | Refresca y devuelve los limites de los campos. |
| `GET /api/status` | Devuelve `status: ok` y la cantidad de animales. |
| `POST /api/animals/rename` | Cambia el nombre de un animal. |

Todas las respuestas principales permiten CORS mediante `Access-Control-Allow-Origin: *`.

## 6. Utilidades: `server/utils/utils.js`

#### `normalizeAnimalPayload(raw)`

Acepta distintas variantes de nombres (`ID`, `id`, `LAT`, `lat`, etc.), valida ID y coordenadas y devuelve un formato comun:

```js
{
  id,
  name,
  lat,
  lng,
  temp
}
```

Devuelve `null` si faltan ID, latitud o longitud validas.

#### `normalizeLimitsField(raw)`

Valida y normaliza grupos de limites. Convierte variantes de latitud y longitud a:

```js
{
  nombreDelCampo: {
    limit1: { lat, lng }
  }
}
```

#### `mergeLimitsField(newLimits)`

Combina nuevos limites con el objeto global de limites en memoria. Es una utilidad para datos recibidos, aunque los limites principales actualmente se cargan desde la base.

#### `extractJsonObjects(value)`

Recorre el texto recibido y separa objetos JSON completos usando el nivel de llaves y el estado de las cadenas de texto. Esto permite procesar varios JSON enviados juntos por TCP.

## 7. Base de datos: `server/db/index.js`

Este modulo es la capa de acceso a PostgreSQL.

### Configuracion y conexion

#### `escapeSqlLiteral(value)`

Convierte un valor a literal SQL escapado. Actualmente no participa en el flujo principal, porque las consultas usan parametros `$1`, `$2`, etc. Es candidata a eliminarse si no se reutiliza.

#### `splitSqlStatements(sql)`

Separa el contenido de `schema.sql` en sentencias para ejecutarlas durante la inicializacion.

#### `getSslConfig()`

Lee `PGSSLMODE` o `PGSSL` y decide si la conexion usa SSL.

#### `getPoolConfig()`

Construye la configuracion del pool de PostgreSQL usando `DATABASE_URL` o variables separadas como `PGHOST`, `PGPORT`, `PGDATABASE`, `PGUSER` y `PGPASSWORD`.

#### `getDb()`

Crea el pool una sola vez y devuelve siempre la misma instancia.

#### `testConnection()`

Ejecuta `SELECT NOW()` para comprobar la conexion y libera el cliente al terminar.

#### `initializeDatabase()`

Lee `schema.sql`, abre una transaccion, ejecuta cada sentencia y confirma con `COMMIT`. Si una sentencia falla, ejecuta `ROLLBACK`. La variable `initialized` evita repetir la inicializacion en el mismo proceso.

### Campos y geometria

#### `polygonToLimitMap(name, polygonGeoJson)`

Convierte un poligono GeoJSON de PostGIS al formato de limites esperado por el frontend. Elimina el ultimo punto si repite el primero y transforma cada par `[longitud, latitud]` en `{ lat, lng }`.

#### `ensureDefaultYards(client, userId)`

Comprueba si existen los campos demo y crea `limitsField1` y `LimitsField2` si faltan. Es idempotente: no los duplica en reinicios posteriores.

#### `listYards()`

1. Inicializa la base.
2. Obtiene el usuario demo.
3. Asegura los campos por defecto.
4. Consulta sus poligonos.
5. Convierte cada poligono con `polygonToLimitMap()`.
6. Devuelve el objeto `limitsField`.

### Animales y dispositivos

#### `listAnimals()`

Obtiene los animales del usuario demo, el dispositivo asociado y la ultima posicion GPS. Devuelve para el frontend:

```js
{
  id,
  name,
  lat,
  lng,
  temp
}
```

#### `upsertAnimalSnapshot(payload)`

Guarda una lectura del collar:

1. Normaliza ID, nombre, coordenadas y temperatura.
2. Busca el dispositivo por `device_uid`.
3. Si no existe, crea animal, dispositivo y relacion entre ambos.
4. Actualiza el nombre del animal.
5. Inserta una posicion en `gps_positions`.
6. Devuelve el snapshot procesado.

Las coordenadas se insertan como `ST_MakePoint(longitud, latitud)` con SRID `4326`.

#### `renameAnimal(id, newName)`

Busca un animal por ID interno o por `device_uid`, actualiza su nombre y devuelve el resultado. Devuelve `null` si no lo encuentra.

#### `getDemoUserId(client)`

Busca el usuario `demo@agronomad.app` y lo crea si no existe.

#### `seedSampleData()`

Carga datos de demostracion:

- usuario demo;
- campos por defecto;
- `COLLAR-01`, `COLLAR-02` y `COLLAR-03`;
- posiciones GPS iniciales;
- estadisticas diarias aleatorias.

Si los animales ya existen, no los duplica.

## 8. Base de datos: `server/db/schema.sql`

Activa PostGIS y define estas tablas:

| Tabla | Contenido |
|---|---|
| `users` | Usuarios de la aplicacion. |
| `yards` | Campos y poligonos de sus limites. |
| `animals` | Animales, tipo, nombre y campo asignado. |
| `devices` | Collares, version y ultima conexion. |
| `animal_devices` | Relacion historica entre animales y dispositivos. |
| `gps_positions` | Historial de ubicaciones y sensores. |
| `animal_daily_statistics` | Distancia, movimiento y sueño por dia. |

### Relaciones importantes

- Un usuario puede tener varios campos y animales.
- Un animal puede estar asociado a un dispositivo mediante `animal_devices`.
- Un dispositivo puede cambiar de animal sin perder su historial.
- Una posicion GPS pertenece a un animal y puede referenciar su dispositivo.
- `ON DELETE CASCADE` elimina datos dependientes cuando corresponde.

### Coordenadas

- `yards.boundary` guarda un poligono.
- `gps_positions.location` guarda un punto geografico.
- El SRID usado es `4326`.
- PostGIS espera los puntos como `(longitud, latitud)`.

### Indices

Los indices aceleran:

- busqueda de posiciones por animal;
- ordenamiento por fecha;
- consultas espaciales con GIST;
- busqueda de campos por usuario;
- busqueda de animales por campo o usuario;
- estadisticas por animal y fecha;
- asignaciones por dispositivo.

## 9. Frontend

### `client/src/App.jsx`

Implementa una navegacion simple basada en `window.location.pathname`:

- `/login` muestra `Login`.
- `/userconf` muestra `UserConfig`.
- cualquier otra ruta muestra `Home`.

El callback de login todavia es `null`, por lo que la autenticacion no esta conectada a una sesion real.

### `client/src/pages/Home.jsx`

Es el dashboard principal.

Funciones y responsabilidades:

- Consulta `/api/animals` al cargar y cada 15 segundos.
- Consulta datos de limites dentro del mismo flujo esperado por la vista.
- Conserva el animal seleccionado cuando se actualizan los datos.
- Calcula el centro del mapa.
- Muestra animales como `CircleMarker` de Leaflet.
- Muestra campos como `Polyline`.
- Permite seleccionar un animal y hacer zoom con `FlyToSelected`.
- Permite copiar coordenadas.
- Permite cambiar el nombre mediante `/api/animals/rename`.
- Incluye un enlace preparado para un futuro historial en `/history/:id`.

### `normalizeBoundaryGroups(payload)`

Convierte los limites recibidos a posiciones `[lat, lng]`, cierra el poligono y los prepara para `Polyline`.

### `FlyToSelected({ position })`

Usa la instancia del mapa para centrarlo suavemente en la posicion seleccionada.

### `client/src/pages/Login.jsx`

Muestra formulario de email y contraseña y envia `POST /api/login`. Sin embargo, el backend actual no implementa esa ruta ni una autenticacion real.

## 10. Resumen de lo implementado actualmente

- Recepcion TCP de payloads JSON.
- Persistencia de animales, dispositivos y posiciones GPS.
- Persistencia de limites de campos en PostgreSQL/PostGIS.
- Carga de datos demo idempotente.
- API para animales, campos, estado y renombrado.
- Dashboard con mapa, marcadores y limites.
- Actualizacion periodica de animales cada 15 segundos.
- Reconexion basica del cliente C cuando se pierde el socket.

## 11. Lista de pendientes

Estas funciones aparecen en los documentos de planificacion, pero no estan terminadas en el codigo actual:

1. Actualizar `devices.last_seen` en cada paquete recibido.
2. Guardar `FIRMWARE_VERS` y `HARDWARE_VERS` enviados por el collar.
3. Implementar consultas y endpoints para el historial de posiciones.
4. Dibujar trayectos historicos con colores segun movimiento.
5. Detectar y marcar animales fuera de los limites del campo.
6. Implementar login, cookies/sesiones y proteccion de rutas.
7. Agregar la ruta frontend `/history/:id`.
8. Separar mejor datos demo de datos reales.
9. Reemplazar polling por WebSocket si se necesita tiempo real.
10. Agregar limites de tamaño y validacion mas robusta para mensajes TCP.
11. Revisar el manejo de errores de operaciones asincronas del socket.
12. Agregar backups automaticos y almacenamiento de telemetria si el volumen crece.

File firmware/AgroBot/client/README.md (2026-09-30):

# AgroNomad - Frontend

El frontend de AgroNomad es una aplicación web desarrollada con React, Vite, Tailwind CSS y Leaflet. Consume la API del backend para mostrar el estado y la ubicación de los animales conectados.

## Funciones principales

- Muestra un mapa con la posición GPS de los animales y los límites de los campos.
- Permite seleccionar un animal para consultar su ID, nombre y temperatura.
- Actualiza los datos de los animales automáticamente cada 15 segundos.
- Permite cambiar el nombre del animal seleccionado mediante un formulario.
- Muestra estados de carga y mensajes de error cuando no se pueden obtener los datos.
- Incluye navegación entre el mapa, el inicio de sesión y la configuración del usuario.

## Pantallas y componentes

| Archivo | Función |
|---|---|
| `src/App.jsx` | Controla la navegación básica entre las vistas principales. |
| `src/pages/Home.jsx` | Página principal con mapa, resumen de animales y detalles del animal seleccionado. |
| `src/pages/Login.jsx` | Formulario de inicio de sesión conectado a la API. |
| `src/pages/UserConfig.jsx` | Muestra información del usuario, del campo y del estado general del predio. |
| `src/hooks/useAnimalDashboard.js` | Carga, normaliza y actualiza los datos de animales y límites del campo. |
| `src/components/home/` | Contiene el mapa, la navegación, el resumen y los detalles de los animales. |
| `src/components/RenameAnimalModal.jsx` | Formulario para cambiar el nombre de un animal. |

## Datos utilizados

El frontend obtiene los datos principales desde:

- `GET /api/animals`: animales, coordenadas, nombres y temperaturas.
- `GET /api/yards`: coordenadas de limites del campo/s definidos.
- `POST /api/animals/rename`: actualización del nombre de un animal.
- `GET /api/status`: Devuelve el estado del servidor y la cantidad de animales.

Las respuestas de la API se normalizan para aceptar campos como `ID`, `LAT`, `LONG` y `TEMP`, además de sus versiones en minúsculas.

## Ejecución

Desde esta carpeta se puede iniciar el entorno de desarrollo con:

```bash
npm install
npm run dev
```

La aplicación necesita que el backend esté disponible para cargar los animales y actualizar sus nombres.

## Producción

The browser must be able to reach the API. Choose one of these configurations:

- Preferred: serve `dist/` behind a reverse proxy that forwards `/api/` to the
  backend at port `4000`. An Nginx example is included at
  `../deployment/nginx/agronomad.conf`. In this setup, leave
  `VITE_API_BASE_URL` empty.
- Separate API origin: copy `.env.example` to `.env.production`, set
  `VITE_API_BASE_URL` to the public API URL (for example,
  `https://api.example.com`), then run `npm run build` again.

Do not use `localhost` for `VITE_API_BASE_URL` unless the browser and API run
on the same machine.

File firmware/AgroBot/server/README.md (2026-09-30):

# AgroNomad - Backend

El backend de AgroNomad recibe la telemetría enviada por los dispositivos de los animales, la guarda en PostgreSQL con PostGIS y expone una API HTTP para que el frontend consulte la información.

## Funciones principales

- Recibe mensajes de telemetría mediante una conexión TCP.
- Extrae y procesa objetos JSON, incluso cuando llegan varios mensajes juntos.
- Normaliza el ID, nombre, posición GPS y temperatura de cada animal.
- Crea o actualiza animales, dispositivos y posiciones en la base de datos.
- Expone endpoints HTTP para consultar animales, campos y el estado del sistema.
- Permite cambiar el nombre de un animal.
- Inicializa el esquema y crea datos de demostración al iniciar.

## Servicios y archivos principales

| Archivo | Función |
|---|---|
| `server.js` | Inicializa la base de datos y arranca los servidores HTTP y TCP. |
| `app.js` | Configura Express, CORS, el parseo JSON y las rutas de la API. |
| `services/telemetryServer.js` | Mantiene el servidor TCP que recibe la telemetría. |
| `services/telemetryParser.js` | Extrae JSON, valida los datos y guarda cada lectura recibida. |
| `controllers/` | Implementa la lógica de las respuestas de animales, campos y estado. |
| `routes/` | Define las rutas HTTP disponibles para el frontend. |
| `db/index.js` | Gestiona la conexión a PostgreSQL y las consultas principales. |
| `db/schema.sql` | Define las tablas, relaciones e índices de PostgreSQL/PostGIS. |

## Flujo de datos

1. Un dispositivo envía un JSON al puerto TCP.
2. El servidor separa los mensajes completos del buffer recibido.
3. El parser normaliza el payload y valida el ID y las coordenadas.
4. La lectura se guarda junto con el animal, el dispositivo y la temperatura.
5. El frontend consulta la API HTTP para mostrar los datos actualizados.

Ejemplo de payload aceptado:

```json
{
  "ID": "COLLAR-01",
  "NAME": "Animal 1",
  "LAT": -34.707652,
  "LONG": -58.242300,
  "TEMP": "38.4"
}
```

## API HTTP

| Método y ruta | Función |
|---|---|
| `GET /api/animals` | Devuelve los animales con su última posición y temperatura. |
| `POST /api/animals/rename` | Cambia el nombre de un animal usando `id` y `name`. |
| `GET /api/yards` | Devuelve los límites de los campos en formato de coordenadas. |
| `GET /api/status` | Devuelve el estado del servidor y la cantidad de animales. |

## Base de datos

El backend utiliza PostgreSQL y la extensión PostGIS. El esquema incluye usuarios, campos, animales, dispositivos, relaciones entre animales y dispositivos, posiciones GPS y estadísticas diarias.

La conexión puede configurarse con `DATABASE_URL` o con las variables `PGHOST`, `PGPORT`, `PGDATABASE`, `PGUSER` y `PGPASSWORD`.

## Ejecución

Desde esta carpeta:

```bash
npm install
npm run dev
```

Para ejecutar el servidor sin modo de desarrollo:

```bash
npm start
```

Por defecto, la API HTTP utiliza el puerto `4000` y el servidor TCP de telemetría el puerto `4001`. Se pueden cambiar con `PORT` y `TCP_PORT`.

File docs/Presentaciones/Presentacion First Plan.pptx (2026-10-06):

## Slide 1

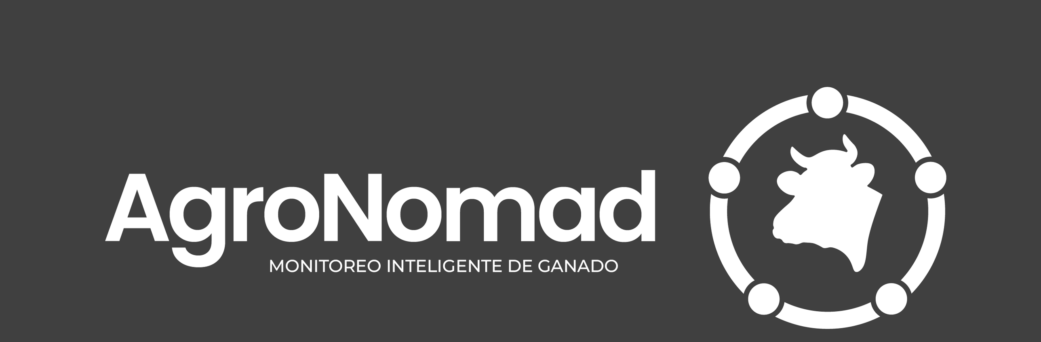
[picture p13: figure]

E.E.S.T N°7 IMPA “TRQ“ – First Plan

Della Torre, Joaquín
Gonzalez Camiscia, Santiago
Romero Dominguez, Braulio
Villegas Gonzalez, Alejandro

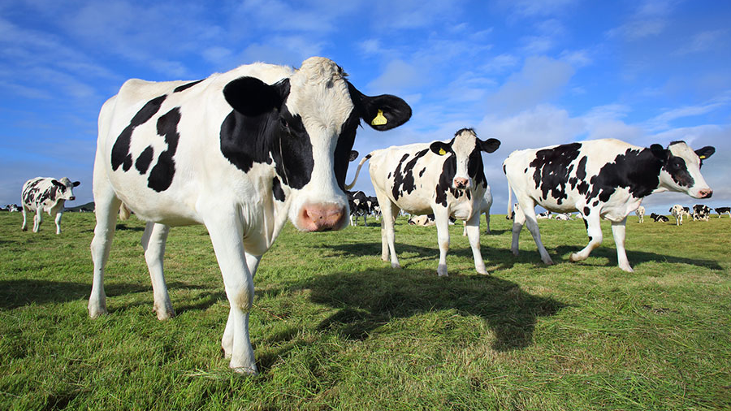
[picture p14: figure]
Intensive farming: The plight of factory farmed dairy cows and their calves

## Business Model Canvas

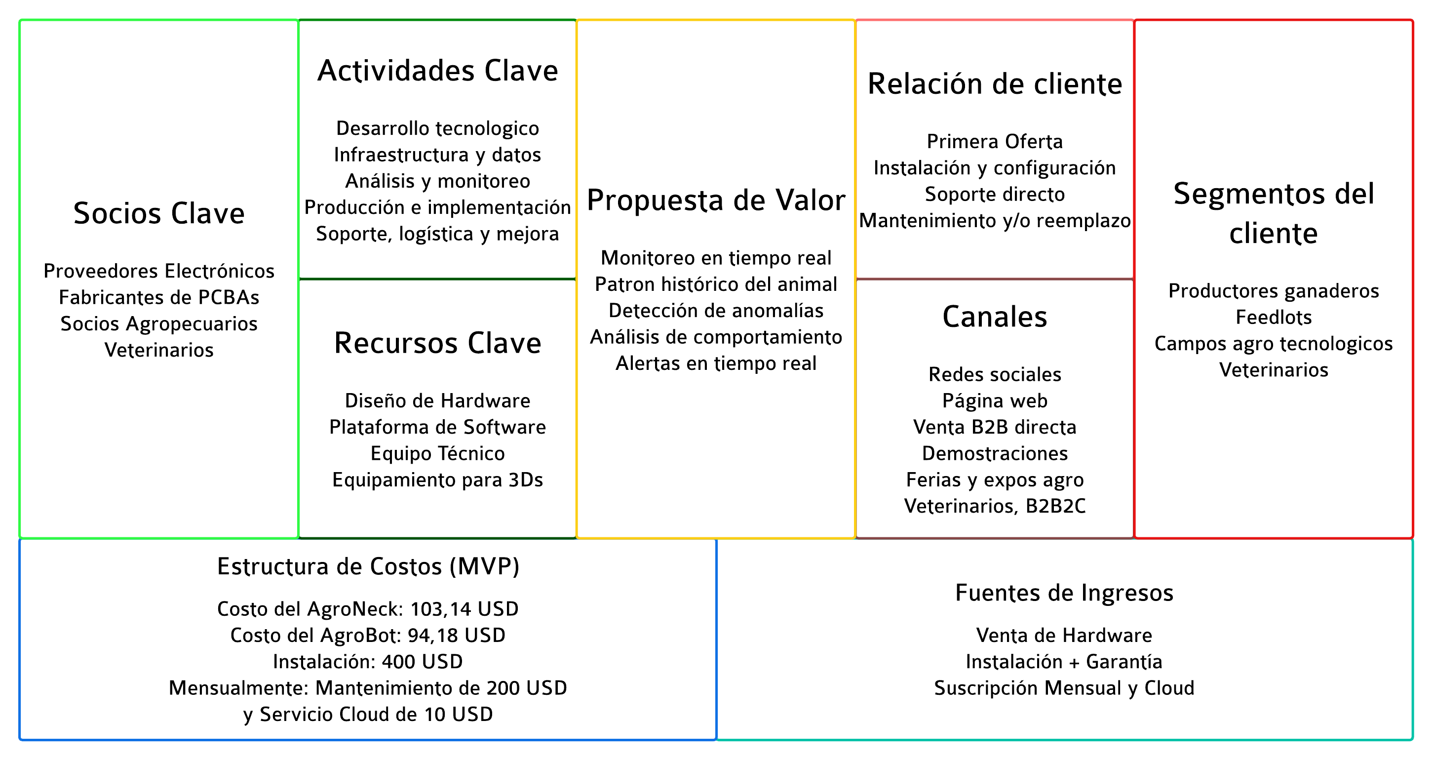
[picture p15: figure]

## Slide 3

01

Socios Clave

PROV. ELECTRONICOS — Insumos necesarios

FABRICANTES — PCBAs para diseños electrónicos

EMPRESAS AGRO — Pruebas reales y feedback

VETERINARIOS — Análisis del comportamiento

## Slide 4

02

Actividades Clave

Se divide en seis grandes áreas que
involucran diferentes factores

Desarrollo tecnológico y electrónico

Infraestructura y manejo de datos

Análisis y monitoreo inteligente

Producción e implementación

Soporte, logística y mejora

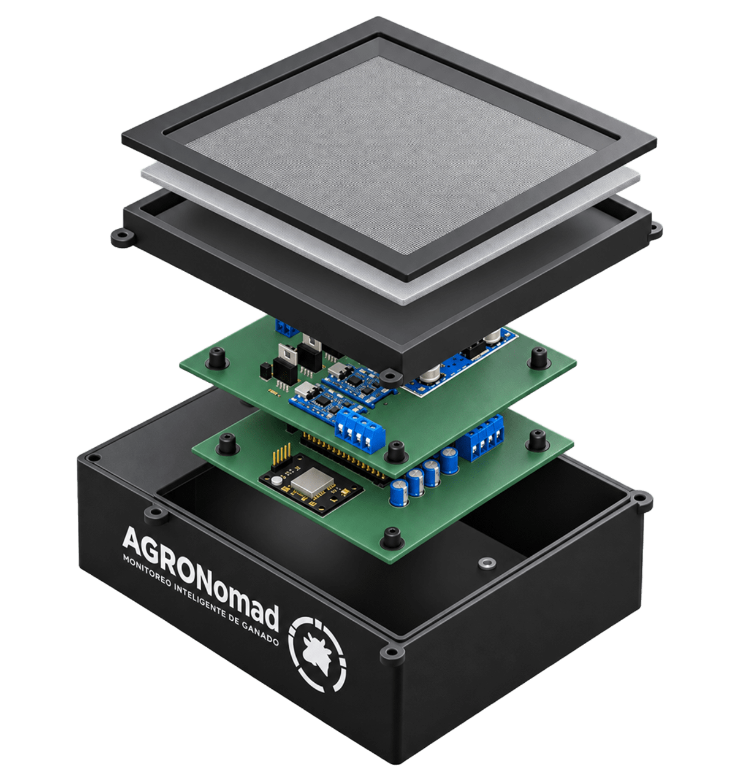
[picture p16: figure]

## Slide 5

03

Recursos Clave

Diseños de Hardware para los collares

*

Plataforma de Software para la estación receptora

*

Equipo técnico de mantenimiento

*

Equipamiento para carcasas 3D de los collares

*

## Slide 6

04

Propuesta de Valor

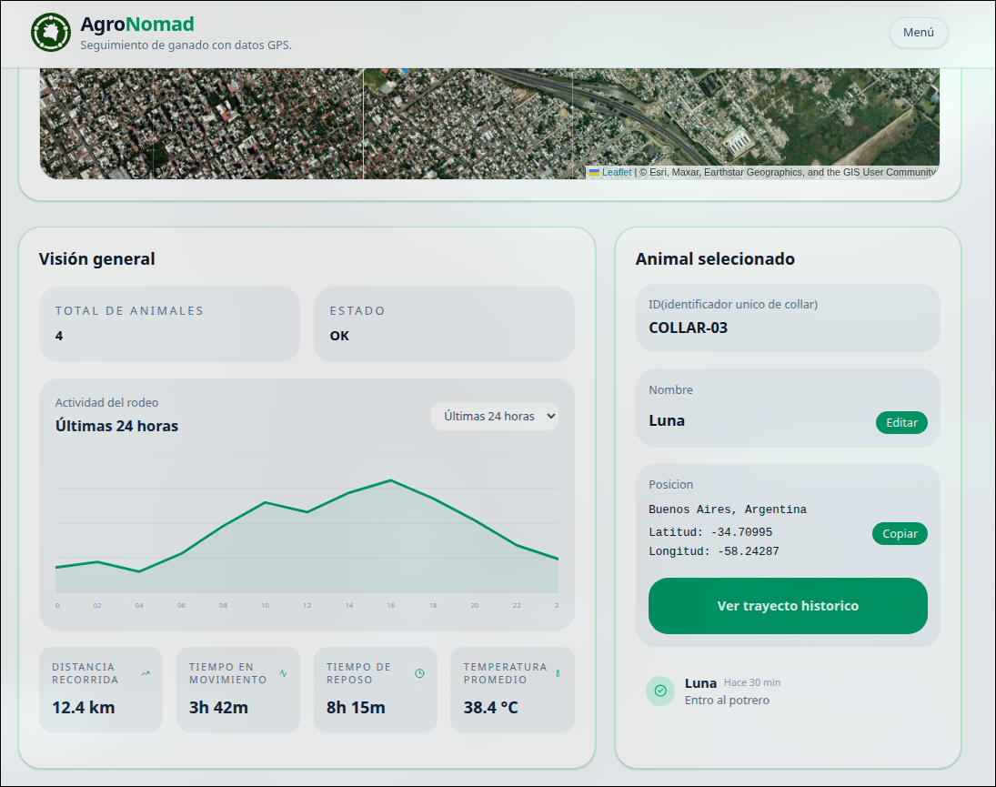
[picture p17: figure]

Ubicación: Posición precisa en tiempo real.

Información: Datos personales del animal.

Monitoreo: Comportamiento y patrones.

Análisis: Historial de datos analizados.

Alertas: Anomalías detectadas automáticamente.

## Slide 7

05

Relación de cliente

Instalación: El equipo se encargará de la configuración de hardware y software instalando el receptor, configurando los collares y registrando el establecimiento.

Soporte: Ante cualquier inconveniente que pudiese llegar a surgir o dudas acerca del acceso al sistema de gestión web o para cargar información del ganado.

Mantenimiento: En caso necesario y pertinente, se proveerá de reemplazo de collares, mantenimiento o actualizaciones de software o firmware.

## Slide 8

06

Canales

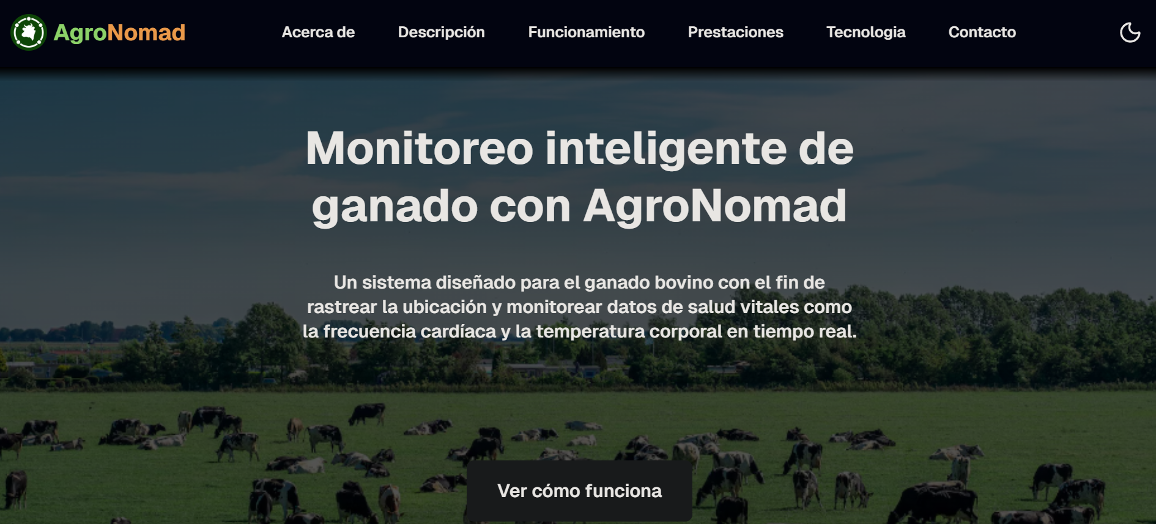
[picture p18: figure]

Página Web

Venta B2B directa

Demostraciones en campo

Redes Sociales - WhatsApp

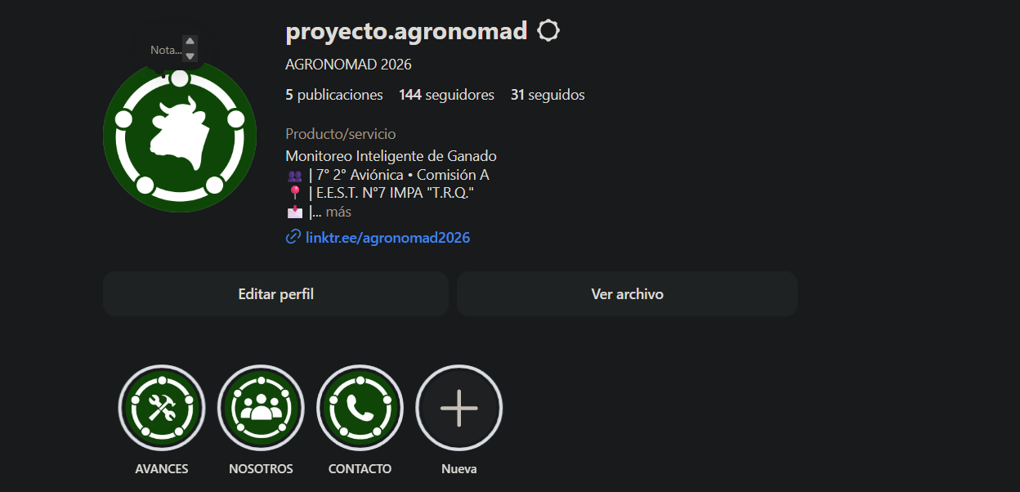
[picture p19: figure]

Ferias y expos agro

Veterinarios mediante B2B2C

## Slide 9

07

Segmentos del Cliente

PRODUCTORES
GANADEROS

FEEDLOTS

VETERINARIOS

ESTABLECIMIENTOS
AGRO TECNOLOGICOS

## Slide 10

08

Estructura de Costos

INVERSIÓN INICIAL

Costos de un AgroNeck

103,14 USD

Costo del AgroBot

94,18 USD

Costos de Instalación

MENSUALMENTE

400 USD

Posible Mantenimiento

200 USD

Almacenamiento en Nube (OPCIONAL)

10 USD

Monitoreo: Comportamiento y patrones.

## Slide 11

09

Fuentes de Ingresos

VENTA DE HARDWARE
Collares AgroNecks y Estación de Recepción AgroBot

INSTALACION + GARANTIA
Trabajo de instalación y configuración con garantía incluida

SUSCR. MENSUAL Y CLOUD
Opcional para el usuario, almacenamiento de datos históricos

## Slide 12

GRACIAS

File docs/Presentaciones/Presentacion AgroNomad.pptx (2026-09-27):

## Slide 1

AgroNomad

MONITOREO INTELIGENTE DE GANADO

E.E.S.T N°7 IMPA “TRQ“ – Eje Libre

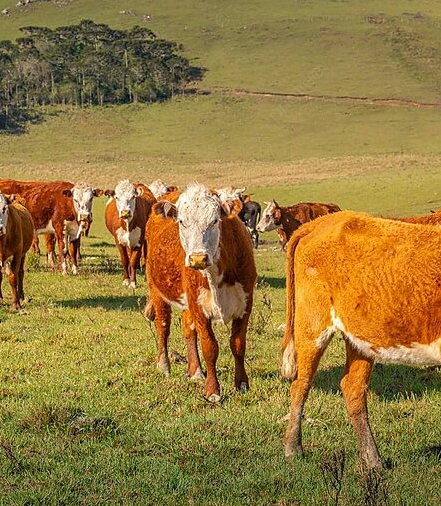
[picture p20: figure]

Della Torre, Joaquín
Gonzalez Camiscia, Santiago
Romero Dominguez, Braulio
Villegas Gonzalez, Alejandro

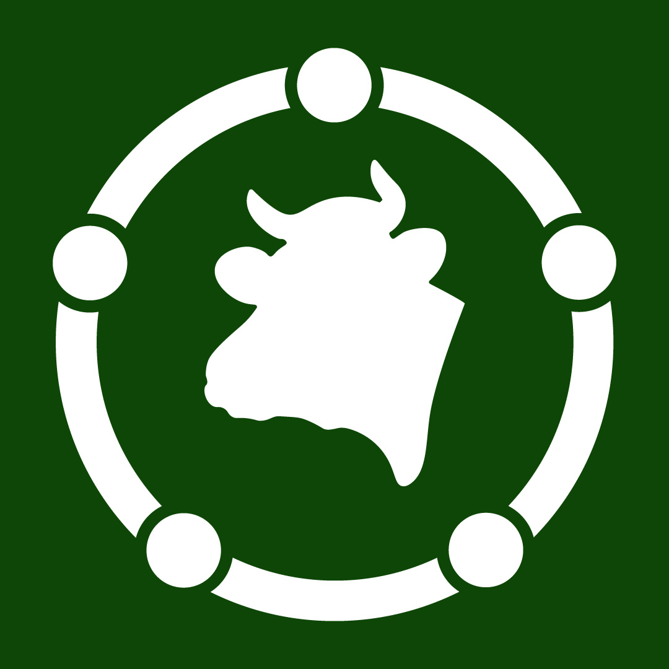
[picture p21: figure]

## Componentes del Proyecto

01

Solución tecnológica en el sector agropecuario

AGRONECK — Collares Smart en Campo

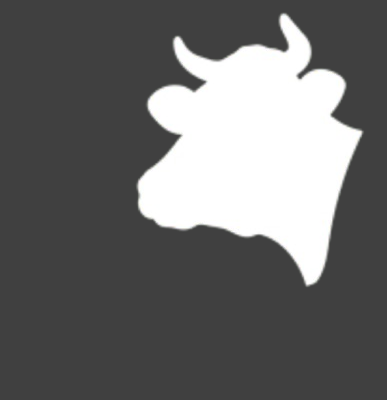
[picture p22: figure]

AGROBOT — Estación fija de Recepción

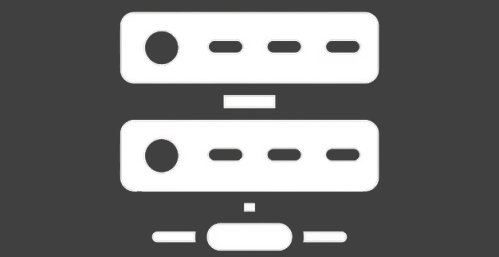
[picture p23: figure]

AGROSERVER — Dashboard de Usuario

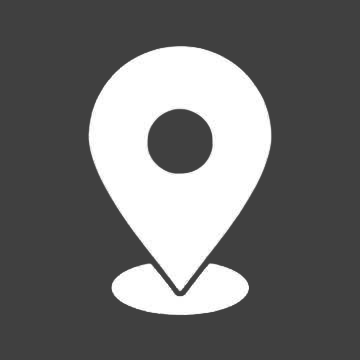
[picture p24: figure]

## AgroNeck

02

Prestaciones integradas en el AgroNeck

Asignación de perfil haciendo a cada AgroNeck un collar único por cada animal.

Ubicación GPS y registro de actividad diaria.

Medición de temperatura interna estimada.

Sistema de ahorro energético “Deep Sleep”.

Autonomía energética solar.


## AgroNeck

02

Diagrama de bloques

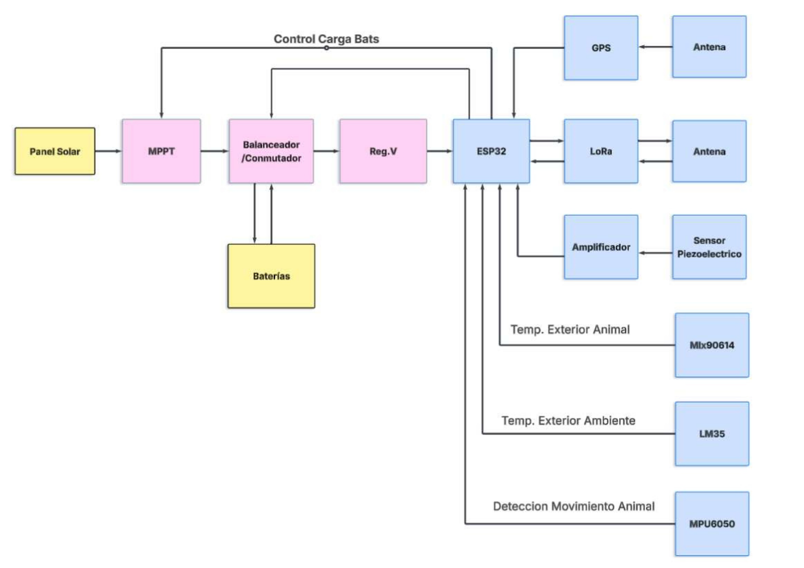
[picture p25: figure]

Módulos

Microcontrolador — ESP32

Módulo GPS — NEO6MV2

Módulo LoRa — XL1278

Acelerómetro — MPU6050

Sensado Temp. Int. — MLX90614

Sensado Temp. Ext. — LM35

## AgroBot

03

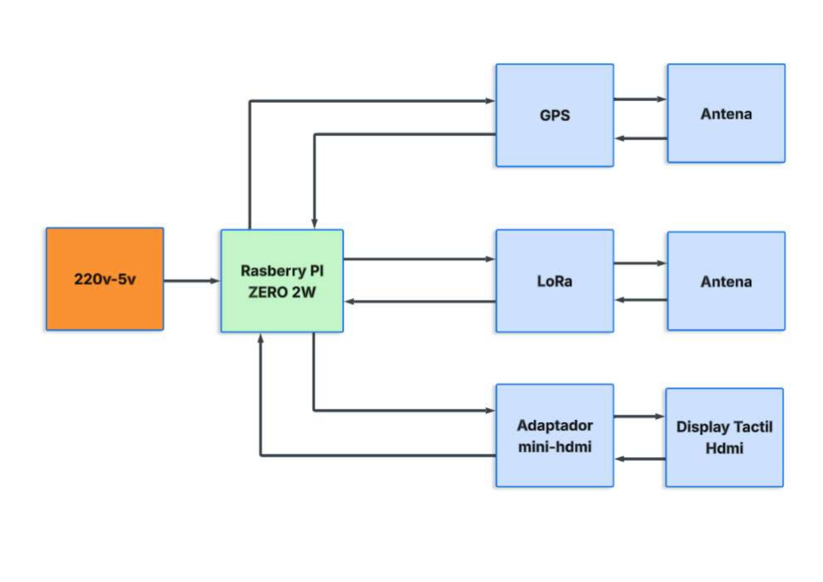
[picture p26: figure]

Diagrama de bloques

Arquitectura

Un AgroBot es una estación de recepción de datos fija encargada de recibir y procesar los datos de los AgroNecks.

Cada AgroBot generará una dashboard llamada AgroServer que será la interfaz del usuario.

El AgroServer también podrá ser abierto en dispositivos conectados a la red Wi-Fi que genera el AgroBot.

Los AgroBots son los centros de control del ecosistema AgroNomad.

## AgroServer

04

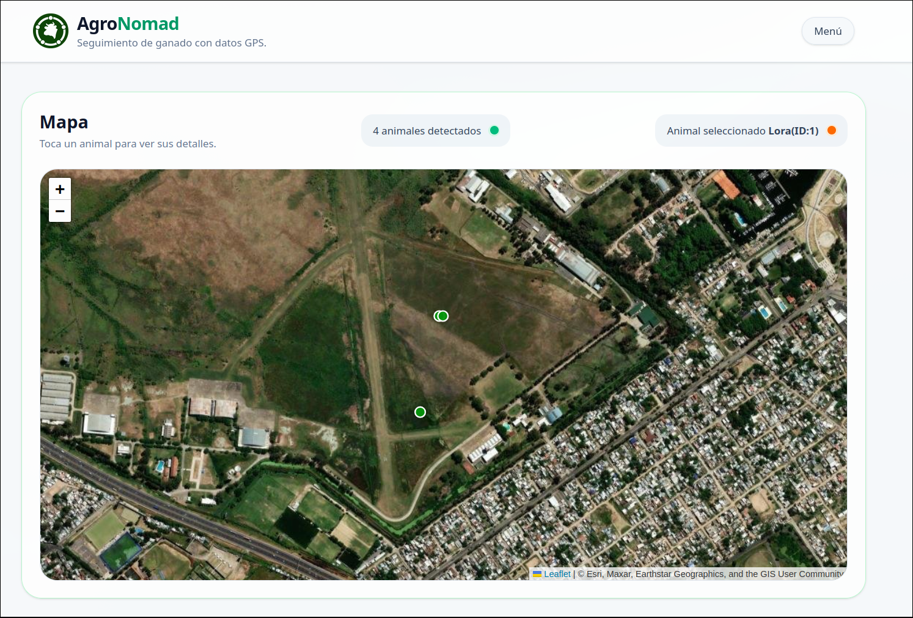
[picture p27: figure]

Mapeo del área de trabajo establecida y posición de los animales.

Asignación de perfil a cada collar con información fundamental del animal.

Observación de distancia recorrida por el animal durante el día.

Alertas ante animales fuera del área de trabajo o con parámetros fuera de rango.

Tecnologías web para el desarrollo: React.js, Node.js y Express.js.

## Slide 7


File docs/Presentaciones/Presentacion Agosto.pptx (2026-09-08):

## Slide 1

AgroNomad

MONITOREO INTELIGENTE DE GANADO


7mo 2da AVC Comisión A

Della Torre, Joaquín
Gonzalez Camiscia, Santiago
Romero Dominguez, Braulio
Villegas Gonzalez, Alejandro


## Componentes del Proyecto

01

Solución tecnológica en el sector agropecuario

AGRONECK — Collares Smart en Campo


AGROBOT — Estación fija de Recepción


AGROSERVER — Dashboard de Usuario


## AgroNeck

02

Prestaciones integradas en el AgroNeck

Asignación de perfil haciendo a cada AgroNeck un collar único por cada animal.

Ubicación GPS y registro de actividad diaria.

Medición de temperatura interna estimada.

Sistema de ahorro energético “Deep Sleep”.

Autonomía energética solar.


## AgroNeck

02

Diagrama de bloques


Módulos

Microcontrolador — ESP32

Módulo GPS — NEO6MV2

Módulo LoRa — XL1278

Acelerómetro — MPU6050

Sensado Temp. Int. — MLX90614

Sensado Temp. Ext. — LM35

## AgroBot

03


Diagrama de bloques

Arquitectura

Un AgroBot es una estación de recepción de datos fija encargada de recibir y procesar los datos de los AgroNecks.

Cada AgroBot generará una dashboard llamada AgroServer que será la interfaz del usuario.

El AgroServer también podrá ser abierto en dispositivos conectados a la red Wi-Fi que genera el AgroBot.

Los AgroBots son los centros de control del ecosistema AgroNomad.

## AgroServer

04


Mapeo del área de trabajo establecida y posición de los animales.

Asignación de perfil a cada collar con información fundamental del animal.

Observación de distancia recorrida por el animal durante el día.

Alertas ante animales fuera del área de trabajo o con parámetros fuera de rango.

Tecnologías web para el desarrollo: React.js, Node.js y Express.js.

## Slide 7


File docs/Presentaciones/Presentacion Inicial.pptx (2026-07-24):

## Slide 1

AgroNomad

MONITOREO INTELIGENTE DE GANADO


7mo 2da AVC Comisión A

Della Torre, Joaquín
Gonzalez Camiscia, Santiago
Romero Dominguez, Braulio
Villegas Gonzalez, Alejandro


## Componentes del Proyecto

01

Solución tecnológica en el sector agropecuario

AGRONECK — Collares Smart en Campo


AGROBOT — Estación fija de Recepción


AGROSERVER — Dashboard de Usuario


## AgroNeck

02

Prestaciones integradas en el AgroNeck

Asignación de perfil haciendo a cada AgroNeck un collar único por cada animal.

Ubicación GPS y registro de actividad diaria.


Sistema de pulso con filtrado.

Medición de temperatura interna estimada.

Autonomía energética solar.

## AgroNeck

02

Diagrama de bloques


Módulos

Microcontrolador — ESP32

Módulo GPS — NEO6MV2

Módulo LoRa — XL1278

Acelerómetro — MPU6050

Medición de PPM — Sensor Piezoeléctrico

Sensado Temp. Int. — MLX90614

Sensado Temp. Ext. — LM35

## AgroBot

03


Diagrama de bloques

Arquitectura

Un AgroBot es una estación de recepción de datos fija encargada de recibir y procesar los datos de los AgroNecks.

Cada AgroBot generará una dashboard llamada AgroServer que será la interfaz del usuario.

El AgroServer también podrá ser abierto en dispositivos conectados a la red Wi-Fi que genera el AgroBot.

Los AgroBots son los centros de control del ecosistema AgroNomad.

## AgroServer

04


Mapeo del área de trabajo establecida y posición de los animales.

Asignación de perfil a cada collar con información fundamental del animal.

Observación de distancia recorrida por el animal durante el día.

Alertas ante animales fuera del área de trabajo o con parámetros fuera de rango.

Tecnologías web para el desarrollo: React.js, Node.js y Express.js.

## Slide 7

AgroNomad

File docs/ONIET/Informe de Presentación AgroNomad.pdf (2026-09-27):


# AgroNomad

### Informe de Presentación - Eje Libre E.E.S.T N°7 IMPA ”TRQ”

Gonzalez Camiscia, Santiago

Della Torre, Joaquin

Romero Dominguez, Braulio

Villegas Gonzalez, Alejandro

1

## 1. Justificación del Proyecto

El sector ganadero representa aproximadamente el 10 % del Valor Bruto de Producción de los bienes y servicios producidos en la Argentina junto al rubro de la agricultura, caza y silvicultura sin tener en cuenta las actividades industriales y comerciales que se derivan de la cadena productiva de la cría de animales. En el país existen más de 94.000 explotaciones agropecuarias bovinas del tipo EAP de cría, recría, invernada y cabañas y el promedio de cabezas por EAP a nivel nacional se encuentra en el rango de 380 cabezas de ganado. Así, la ganadería en Argentina representa actualmente un 7,5 % de las exportaciones siendo uno de los sectores productivos más amplios que brinda seguridad alimentaría a la nación y además posiciona al país en mercados internacionales.
Aún así, la ganadería es un ambiente competitivo en el que producir ya no es suficiente; es necesario calidad en la gestión y la implementación de herramientas tecnológicas que aseguren una toma de decisiones rápida, con información precisa y útil además de brindar resultados sostenibles y rentables. El futuro de la ganadería pasa por incorporar sistemas que permitan gestionar con mayor inteligencia y eficiencia. Las tendencias tecnológicas en el campo muestran que la digitalización, además de mejorar la productividad, permiten sostener resultados con menor incertidumbre y mayor planificación estratégica.
No obstante, existe un desfasaje estructural en la adopción de estas herramientas en el ámbito rural. Las soluciones existentes en el mercado como los sistemas de geofencing por comunicación satelital directa o collares inteligentes de alta gama imponen esquemas de pago por suscripción mensual y un elevado costo inicial por unidad. Esta estructura financiera genera una barrera de entrada para la mayoría de los productores medianos y pequeños, desincentivando la adopción tecnológica y perpetuando la dependencia de métodos de control manuales, presenciales e ineficientes.
AgroNomad surge como respuesta a una transformación del campo que permita ser accesible y autosostenible. Siendo una solución preventiva de seguridad y gestión operativa en tiempo real, AgroNomad permite el monitoreo de la ubicación y los parámetros fundamentales del ganado pudiendo obtener un registro individualizado de cada animal. Al eliminar la dependencia de pagos mensuales para su uso, el sistema permite tecnología accesible que reduzca la necesidad de supervisión física constante y genere sostenibilidad para el productor.

## 2. Marco de Aplicación y Objetivos

El proyecto de AgroNomad combina diferentes ámbitos para lograr un sistema tecnológico para el sector agropecuario. Entre sus áreas se pueden destacar electrónica embebida para la integración de hardware de bajo consumo energético de dispositivos portátiles, comunicación de radiofrecuencia mediante transmisión LoRa para operar en áreas rurales con escasa cobertura de red, desarrollo de una arquitectura de firmware que permite la adqusición, procesamiento y envío de datos junto a una gestión energética eficiente además de una plataforma de control y gestión de trazabilidad y alertas.
El sistema busca responder las necesidades de pequeños y medianos productores ganaderos que requieran de control y seguridad sobre su ganado pero que no pueden permitirse la inversión requerida para sistemas satelitales mensuales. También busca reducir el esfuerzo físico del personal de campo, optimizando la gestión diaria, minimizando las jornadas físicas en la intemperie y detectando de manera automática y temprana posibles anomalías en el animal.
Los objetivos que tiene AgroNomad son la capacidad de generar un sistema de monitoreo de gánado inteligente, que permita ser autónomo, de largo alcance y bajo costo con adquisición única sin suscripciones mediante collares inteligentes para los animales, AgroNecks, y una estación receptora central, el AgroBot, para optimizar la gestión de ganado y permita la prevención temprana de situaciones críticas en campo. Por lo tanto, el sistema incluye el diseño de collares electrónicos ergonómicos y resistentes que registren la posición y parámetros del animal con una gestión eficiente de energia, el desarrollo de una estación centralizada que recolecte y pueda desplegar la información obtenida, la configuración de algoritmos de detección preventiva para mitigar robo de ganado, pérdida del mismo o parámetros de salud relevantes y de esta manera optimizar la demanda de trabajo físico mediante información centralizada y accesible para la toma de decisiones.

## 3. Desarrollo Técnico

### 3.1. Firmware

### 3.1.1. AgroNeck

El collar inteligente en campo, llamado AgroNeck, es el encargado de sensar la temperatura interna del ganado mediante un algoritmo de estimación, obtener la localización GPS y el comportamiento del animal para envíar toda esta información codificada mediante tecnología LoRa.
El sensado de temperatura se realiza en base al uso de dos sensores de temperatura. Un sensor es el LM35, el cual se encarga de sensar la temperatura del ambiente, mientras que un sensor del tipo infrarrojo, MLX90614, es el encargado de medir la temperatura de la superficie de la piel del animal. En base a estos dos valores, el firmware realiza un cálculo estimado definido a partir de una constante de calibración biofísica que ajusta el error generado por la distancia de medición, la temperatura del ambiente y el pelaje propio del animal para determinar la temperatura interna estimada del ganado:

Tinterna = Tamb + (Tsuperficie − Tamb) · Hcoeficiente
La geolocalización del sistema se realiza mediante el uso de un módulo GPS NEO-6MV2. El firmware configura el módulo mediante el estándar NMEA para comunicación y protocolos de datos de sistemas GPS mediante comunicación UART, solicitando posicionamiento global en intervalos de tiempo definidos. Al recibir la información adquirida del GPS, el microcontrolador extrae las variables de latitud y longitud de la cadena de texto para poder ubicar al animal en el mapa.
La transmisión de estos datos se realiza a través de un módulo LoRa SX1278 operando en la banda de 433MHz. Toda la información (ID del dispositivo para reconocimiento, latitud, longitud, temperatura calculada y datos relevantes de trabajo) es procesada por el firmware para envíarse en un paquete de datos estructurado y codificado, optimizando la transmisión para una reducción de consumo y minimizando los errores a la hora de recibir los datos.
En la búsqueda de garantizar eficiencia operativa, se implementó un acelerómetro MPU6050 mediante I2C que se encarga de monitorear el movimiento e inclinación del animal. De esta manera, el firmware procesa las lecturas para detectar el comportamiento del animal y así implementar un sistema de gestión de energía mediante el modo Deep-Sleep de la ESP32. El microcontrolador permanece en estado de mínimo consumo la mayor parte del tiempo, despertando para realizar todas sus tareas de forma periódica o ante interrupciones físicas que sean detectadas por el MPU6050 cuando el animal empiece a registrar movimiento.
El firmware también implementa una estrategía de gestión energética a través del contador RTC (Real Time Clock) interno de la ESP32. Gracias a que este contador se mantiene activo aún en el modo Deep-Sleep del microcontrolador, la lógica del firmware lleva un registro temporal de tiempo trabajado para ejecutar una conmutación lógica entre el par de baterías que contiene el collar. De esta manera, se permite que mientras una celda esté alimentando la electrónica del collar, la otra se recargue mediante el panel solar integrado sin interrumpir el funcionamiento, permitiendo extender la vida útil de las baterías y garantizando autonomía energética ininterrumpida.


Figura 1: Diagrama de Flujo del AgroNeck.

Al energizarse el microcontrolador, el firmware consultará la causa de encendido. Si la causa no fue una interrupción generada por el MPU6050, el collar detectará que es un encendido por primera vez o forzado, por lo que inicializará los protocolos necesarios para activar el modo Deep-Sleep y mantener el sistema energizado a través del sistema de conmutación.
Luego, cuando el microcontrolador se despierte por el MPU6050, el sensor activará a la ESP32 mediante una interrupción externa. Mediante una tarea, se inicializan los módulos GPS, sensor de temperatura ambiente, sensor de temperatura interna y el sistema de conmutación.
Se adquieren los datos de latitud y longitud del GPS, la temperatura de la piel y ambiental mediante el MLX90614 y el LM35 y se realiza la ecuación de estimación para calcular la temperatura interna.

Luego se crea una estructura de paquete codificado para envíarse por LoRa mientras se revisa el tiempo transcurrido desde la última conmutación mediante el contador RTC para alternar las baterías y se configura nuevamente todo para que la ESP32, al terminar todas las tareas, pueda volver al estado Deep-Sleep hasta el siguiente movimiento.

### 3.1.2. AgroBot

El AgroBot es el encargado de recibir la información de todos los collares, siendo la estación base local dentro del establecimiento ganadero. Su función es mantener una recepción constante de la comunicación LoRa, procesar la información recibida de los AgroNecks, ubicarse así mismo mediante GPS y organizar el flujo de datos con el software local.
La unidad encargada de procesar la información es un microcontrolador Raspberry Pi Zero 2W. Se encarga de recibir los datos mediante un programa embebido optimizado para un consumo mínimo, en paralelo se inicializan el módulo GPS NEO-6MV2 y el Receptor LoRa SX1278 para recibir los paquetes de datos que envían los collares. Cuando el sistema captura una transmisión de un AgroNeck, verifica que los datos sean correctos y los estandariza en una estructura JSON decodificado para envíarlo al servidor backend.

### 3.1.3. AgroServer

Toda la etapa de proceso, almacenamiento y visualización del sistema se realiza de manera local en el AgroBot, eliminndo la dependencia de conexión a internet, servicios de nube o costos de hosting.
De esta manera, el servidor backend se encarga de leer los paquetes JSON y procesarlos para dos funcionalidades específicas. Por un lado, en una base de datos PostgreSQL se guardan los registros de ubicación, temperatura interna y estado operativo para garantizar la trazabilidad histórica de cada animal.
Mientras que por otro lado compara las coordenadas con los limites definidos del área de trabajo que configuró el productor previamente para definir si algún animal transgredió los límites y tambien detecta si se presentan anomalías en la temperatura o el movimiento del animal, para generar eventos de alerta.
Debido a la limitación de memoria RAM de la plataforma embebida, la arquitectura de software tuvo que definir una manera de optimizar la ejecución simultánea del backend, la base de datos y la interfaz web. De esta manera, se decidió implementar un servidor web NGINX que brinde una aplicación de frontend compilada previamente para no saturar la memoria ni el procesador.
La visualización en tiempo real de la interfaz se realiza en una pantalla integrada en el AgroBot mediante un navegador especializado Cog Browser. Este entorno se configuró en Modo Kiosk, para que el usuario pueda acceder únicamente a la interfaz del sistema.
La interfaz gráfica del usuario permite acceder a todas las funcionalidades de Agro-Nomad. La dashboard general presenta un mapa interactivo dinámico donde ubica en tiempo real al ganado presente en el establecimiento ganadero.


Figura 2: Dashboard de AgroNomad.

En esta dashboard se puede acceder a diferentes opciones que posee integradas.

Figura 3: Menú de opciones.

Detalles: Muestra el estado operativo global del ganado, es decir si el sistema está en funcionamiento. Además, al seleccionar a un animal específico en el mapa, se despliega una ventana con las variables del mismo en el momento es decir la temperatura estimada, coordenadas y hora del último reporte.


Figura 4: Ventana de detalles del animal.

Historial de ganado: Además se presenta un tablero de consulta detallado en donde se puede revisar el registro histórico individual de cada animal, analizar sus patrones de recorrido y la tendencia de temperatura interna a lo largo del tiempo.

Figura 5: Listado histórico del ganado.

Configuración de usuario: Por último, presenta un panel configurable por el usuario para la gestión de credenciales de acceso, administración de parámetros del ganado y el ajuste de los límites del perímetro seguro.


Figura 6: Configuración de usuario.

### 3.2. Hardware

### 3.2.1. AgroNeck

El collar se desarrolló con una arquitectura electrónica enfocada a optimizar el espacio dentro de la carcasa, aislar las perturbaciones electromagnéticas generadas por las etapas de potencia de la lógica sensible, compuesto de dos placas principales que son Cortex y Solaria y dos placas secundarias de adaptación, Lora Shield y de posicionamiento físico, MLX Module.
La placa principal, Cortex, constituye el centro lógico y de adquisición de datos del collar. Integra al microcontrolador ESP32, el sensor de temperatura ambiental, el módulo GPS y la conexión al transmisor de LoRa.


Figura 7: Diseño 3D de la Placa Cortex.

El microcontrolador, ESP32 DevKit V1, fue escodigo por su arquitectura de doble núcleo, bajo costo y su modo de gestión energética de Deep Sleep. Además, implementa un contador RTC y la configuración de despertar por interrupciones externas, permitiendo un sistema de energía eficiente.
El Módulo GPS, NEO-6MV2, se eligió por su bajo consumo, excelente sensibilidad y comunicación vía UART facilitada por las sentencias estándar definidas por NMEA. El sensor de temperatura ambiental LM35 se utiliza por su facilidad para medir con cierta exactitud la temperatura ambiente del lugar, conectado mediante un ADC a la ESP32.
El acelerómetro MPU6050, que utiliza I2C, se seleccionó por su capacidad de medición de aceleración y movimiento angular en los 3 ejes además de su integracción de funcionalidades como Wake-On-Motion (WOM) mediante hardware, que permite despertar a la ESP32 solamente ante movimientos o aceleraciones bruscas.
El LoRa SX1278 seleccionó por utilizar tecnología de radiofrecuencia de largo alcance y bajo consumo de energía, ideal para transmitir datos a alta frecuencia. Su especificación de alcance de más de 3 km se respalda en casos reales de aplicación e investigaciones sobre sensores agrícolas en el campo manteniendo una conexión inalámbrica estable a distancias de entre 2 y 5 kilómetros en áreas abiertas o con vegetación media, comprobando que es la tecnología adecuada para cubrir la superficie de un predio ganadero sin depender de cobertura celular ni pagar servicios satelitales.

La placa encargada de la energía del sistema es Solaria, realiza la alimentación solar inteligente controlando el manejo, recarga y conmutación de la etapa energética del collar.


Figura 8: Diseño 3D de la Placa Solaria.

Se diseñó un circuito de conmutación controlado digitalmente a través de 4 GPIO de la ESP32, permitiendo alternar de forma segura entre dos baterías recargables. Cuando una batería está alimentando Cortex, la otra se desconecta de la carga y se recarga mediante panel solar.
Para permitir la carga solar se incluyó un panel solar en la parte superior del collar que lleva a un Step-Down que estabiliza la tensión para enviarse al cargador IP2312, que estará protegido por un BMS para mantener una carga segura.
Por último habrán dos placas secundarias de adaptación, LoraShield y MLXModule. LoraShield se creó con el objetivo de convertir el LoRa SX1278 de SMD que posee un tamaño compacto, a un adaptador que lo convierta a formato THT para permitir un reemplazo rápido en los prototipos. Permite acoplar el módulo LoRa con conectores hembra en la placa Cortex, facilitando el reemplazo sin afectar al hardware. MLXModule se planteo debido a que el sensor infrarrojo MLX90614 se ubica en la parte inferior de la estructura del collar, ya que debe tener visión directa al cuerpo del ganado y además alejado del calor que puede generar la electrónica del proyecto.

### 3.2.2. AgroBot

El AgroBot compone una unidad autónoma de procesamiento y conexión de radiofrecuencia con una placa diseñada para vincular los módulos de procesamiento, radiofrecuencia y geolocalización de manera compacta.


Figura 9: Diseño 3D del AgroBot.

Se utiliza una Raspberry Pi Zero 2W, con el objetivo de cumplir el procesamiento central de la estación base ya que es ultracompacto y posee un procesador que cumple con la arquitectura de software diseñada (servidor de backend, base de datos Postgre SQL y servidor de frontend en modo Kiosk) sin un consumo eléctrico elevado. Si bien su memoria puede ser un desafío, se resolvió la optimización en el software garantizando un hardware reducido con eficiencia energética.
La decisión de utilizar un GPS y un LoRa exactamente igual a los collares es para eliminar posibles problemas de vinculación y mantener un mismo estándar en todo el proyecto.

## 4. Proceso de Desarrollo

### 4.1. Metodología de Desarrollo

### 4.1.1. Definición y Aplicación

En los primeros dos meses del proyecto, marzo y abril, definimos el proyecto desde el marco que lo planteamos, como también las áreas de trabajo de cada integrante desde sus capacidades actuales hasta cuales buscaban adquirir con este proyecto. Luego de plantear el proyecto decidimos darle un marco de aplicación específico del que surgió AgroNomad, del que desarrollamos historias de usuario para definir quiénes serían aquellos interesados y afectados en el desarrollo y uso del proyecto. Esto nos permitió definir una arquitectura de diseño apropiada a las necesidades que buscabamos cubrir.

### 4.1.2. Desarrollo de Electrónica y Mecánica

Una vez finalizada la etapa de definición y aplicación, en el mes de mayo nos sumergimos en la etapa de empezar a diseñar todo lo que ibamos a necesitar para llevar a cabo el proyecto.
Entre ello, diseñamos los primeros modelos de las placas electrónicas del collar, notando que teníamos que dividir las placas en dos de donde surgen Cortex y Solaria. Se diseñaron los primeros circuitos esquemáticos en Kicad, luego se procedió con el diseño PCB para trasladarlos a físico mediante grabado CNC.
A la par, se diseñaron los primeros modelos de carcasa 3D que si bien se definieron medidas base y parecían simples, el objetivo siempre fue que sea 100 % hermético, que todo pueda ser fácil de ensamblar y que además sea ergonómico y cómodo para el animal. En el desarrollo de esta carcasa siempre se tuvo en cuenta que el material del que se diseñe cumpla con los estándares mínimos de dureza y soporte al ambiente en la intemperie.


Figura 10: Render del Proyecto.

En esta etapa a medida que se iban desarrollando los modelos de las placas también se hacían pruebas básicas de testeo sencillo de los módulos para verificar su correcto funcionamiento y determinar si eran necesarias modificaciones en el diseño de hardware o firmware.

### 4.1.3. Ensayos, Diagnóstico y Depuración

Desde julio en adelante, con una base del proyecto ya iniciada, tuvimos que hacer algunas correcciones de errores que nos enfrentamos a la hora de iniciar las pruebas con el hardware como PCBs espejados.
Luego se definieron los objetivos específicos para los siguientes meses. Desestimamos el desarrollo de Carotid, una placa externa que buscaba medir el pulso animal y amplificarlo, debido a su complejidad de desarrollo ya que es una tecnología que no nos aseguraba un correcto funcionamiento aún cuando lo desarrolláramos como lo habíamos esquematizado.
Además, en esta etapa de ensayo encontramos que podría existir un elevado consumo de energía si definíamos una transmisión periódica aún sin detectar al animal en movimiento, por lo que en esta etapa implementamos el sistema Wake-On-Motion que nos permitió un sistema de energía eficiente.

### 4.1.4. Integración de Sistemas y Validación

Esta última etapa desde septiembre hasta el momento es la etapa de prueba de todos los sistemas en conjunto para evaluar como resultó el ensamble de las carcasas planificadas, cómo se ajustó la etapa de carga solar a lo planificado y la integración de la adquisición de datos con la transmisión LoRa.

### 4.1.5. Evolución y Reorganización

En el proceso del desarrollo, desde la primera etapa de diseño hasta la última de prueba encontramos en todos los casos aspectos a mejorar o posibles situaciones no deseadas que podrían surgir con el paso del tiempo.
Entre los casos surgidos sucedió que no consideramos las conexiones Rx/Tx del puerto UART del GPS a la hora de desarrollar Cortex, por lo que tuvimos que realizarlo de nuevo de manera invertida.
Por otro lado, tuvimos que subdividir el sistema Lora y el MLX90614 en dos subplacas inferiores que se conectan a Cortex debido a problemas con la soldadura de LoRa del tipo SMD y el aislamiento del sensor MLX90614 para separarlo del circuito y posicionarlo en contacto directo con el animal.


Figura 11: Modulo del MLX90614, llamado ”MLXModule”. Uno de los cambios más importantes dentro del proyecto fue discontinuar el Módulo Carotid, mencionado previamente, que era el encargado de medir el pulso. Luego de realizar pruebas iniciales y de una ardua investigación acerca de sistemas basados en sensores piezoeléctricos, su amplificación y adquisición de datos, determinamos que la complejidad de la lectura del pulso en una situación real del campo no garantizaba una precisión adecuada para una primera versión del prototipo. Por lo que decidimos dejarlo para una futura etapa de desarrollo y centrarnos en las tecnologías que ya habíamos podido validar.


Figura 12: Render del sistema Carotid discontinuado. Entre otras situaciones también tuvimos que hacer diferentes modificaciones a la placa de alimentación solar, Solaria, debido a que en los ensayos previos no se había considerado el trabajo de todos los sistemas en su conjunto.
Uno de los ajustes que tuvimos que hacer en Solaria es en el circuito de conmutación de baterías, donde los transistores MOSFET que originalmente habíamos colocado requerían una tensión de VGS mayor a la que podíamos proveer para que su canal se abriera completamente, por lo que la tensión entregada al sistema era de 3,4V cuando en su correcto funcionamiento debía ser de 5V. Debido a esto fueron sustituidos por MOSFET canal P de nivel lógico, al ser difíciles de encontrar en formato THT tuvimos que diseñar mini-adaptadors PCB que permitieron que podamos adquirir SMDs y adaptarlos a THT para insertarlos en la placa Solaria.


Figura 13: Grabado de Adaptadores SMD-THT.

Otro ajuste consistió en reemplazar fueron los cargadores TP4056, debido a que estos exigían una potencia de entrada de 5W para la carga, lo que el panel solar era incapaz de suministrar por lo tanto se generaban caídas de tensión que cancelaban la carga. Esta no fue la única razón, también su baja resistencia interna generó que en pruebas aisladas de carga estos se sobrecalentaran y quedaran inutilizados. Luego de una investigación y en charla con los profesores tutores del proyecto, determinamos que el mejor reemplazo era el cargador de baterías IP2312, un cargador del tipo Bulk junto con un Sistema de Gestión de Baterías (BMS) que garantizaba una exigencia de potencia menor a la que provee el panel solar con ligeras modificaciones en el sistema.

## 5. Impacto Esperado y Conclusiones

### 5.1. Impacto Esperado

El sistema AgroNomad busca generar un impacto positivo en múltiples áreas del sector ganadero, resolviendo limitaciones de la producción tradicional de este ámbito. Al eliminar las suscripciones mensuales recurrentes que suelen existir en el monitoreo satelital tradicional, AgroNomad reduce el costo total del producto para que pequeños y medianos productores puedan acceder a tecnología de precisión, amortizando el costo total del equipamiento gracias a la prevención de pérdida o enfermedad de animales gracias a las alertas tempranas del sistema.
En el ámbito operativo, AgroNomad permite automatizar la geolocalización y el control de temperatura del ganado, para reducir recorridas físicas constantes disminuyendo la carga laboral del personal. Además, con el AgroServer, se permite tener un registro histórico para analizar anomalías de salud o patrones de pastoreo que podrían ser optimizados, mejorando la eficiencia productiva.
Las alertas preventivas en tiempo real junto al sistema de Geofencing le proveen al productor una herramienta activa para la detección inmediata de rotura de alambrados, intentos de robo o situaciones en campo imprevistas.

### 5.2. Conclusiones

El desarrollo de AgroNomad demuestra la factibilidad técnica y económica de implementar soluciones del tipo IoT orientadas al ámbito rural de la Argentina. A través de tecnologías de bajo consumo y costo, el proyecto logra resolver desafíos complejos brindando una solución al sector.

La arquitectura de Deep Sleep en la ESP32, junto a la gestión energética desarrollada con el contador RTC para una conmutación de energía y recarga solar regulada permite garantizar un ciclo continuo de operación y autosostenible en el campo.
La implementación de tecnologías de radiofrecuencia del tipo LoRa demuestra una alternativa sumamente eficaz para la transmisión de telemetría a larga distancia reduciendo costos operativos a comparación de otras redes.

La arquitectura de software diseñada para la Raspberry Pi Zero 2W permitió ejecutar un ecosistema completo con procesos en C, backend Node.js, base de datos PostgreSQL, NGINX e interfaz gráfica aún con un límite estricto. De esta manera, se garantizó un centro de control autónomo y local sin dependencia de conexión a Internet.

De esta manera, AgroNomad se consolida como una solución integral, accesible y escalable que responde a necesidades reales del sector ganadero argentino para una digitalización inteligente del campo.

## Referencias

[1] “Qué es el gps para ganado y sus principales beneficios.” [Online]. Available: https://zeekgps.com/que-es-el-gps-para-ganado-y-sus-principales-beneficios/
[2] “El aporte de la ganadería a la economía argentina.” [Online]. Available: https://www.bcr.com.ar/es/mercados/investigacion-y-desarrollo/informativo-semanal/noticias-informativo-semanal/el-aporte-de-4 (https://www.bcr.com.ar/es/mercados/investigacion-y-desarrollo/informativo-semanal/noticias-informativo-semanal/el-aporte-de-4)
[3] Prensa FADA, “El aporte del campo a la economía argentina.” [Online]. Available: https://www.expoagro.com.ar/noticia-del-agro/el-aporte-del-campo-a-la-economia-argentina/ (https://www.expoagro.com.ar/noticia-del-agro/el-aporte-del-campo-a-la-economia-argentina/)
[4] La Voz de San Justo, “El abigeato sigue siendo un flagelo.” [Online]. Available: https://www.lavozdesanjusto.com.ar/el-abigeato-sigue-siendo-un-flagelo
[5] ArgenBio, “Con los análisis genéticos el robo de ganado ha disminuido drásticamente.” [Online]. Available: https: //www.argenbio.org/novedades/71-mas-novedades/mas-novedades-argentina/ 9361-Con-los-analisis-geneticos-el-robo-de-ganado-ha-disminuido-drasticamente (https://www.argenbio.org/novedades/71-mas-novedades/mas-novedades-argentina/9361-Con-los-analisis-geneticos-el-robo-de-ganado-ha-disminuido-drasticamente)
[6] M. Salvidia, “Irrigación y drenaje de cabeza de animales mayores.” [Online]. Available: https://es.slideshare.net/slideshow/irrigacin-y-drenaje-de-cabeza-de-bovino-y-equino/138982807 (https://es.slideshare.net/slideshow/irrigacin-y-drenaje-de-cabeza-de-bovino-y-equino/138982807)
[7] D. Sigaudo and E. Terré, “La importancia de la ganadería para la economía argentina.” [Online]. Available: https://www.bcr.com.ar/es/mercados/investigacion-y-desarrollo/informativo-semanal/noticias-informativo-semanal/la-48 (https://www.bcr.com.ar/es/mercados/investigacion-y-desarrollo/informativo-semanal/noticias-informativo-semanal/la-48)
[8] Agtech, “Tecnología para el agro: cómo digitalizar la gestión ganadera y mejorar la productividad del campo.” [Online]. Available: https://alboragro.com/tecnologia-para-el-agro-y-ganaderia/

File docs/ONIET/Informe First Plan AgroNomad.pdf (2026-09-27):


# AgroNomad

## E.E.S.T. N.º 7 Taller Regional Quilmes (IMPA)

Organización: Universidad Blas Pascal Informe de presentación
First Plan

Página Web: agronomad.com.ar (https://agro-nomad-page.vercel.app)

Integrantes:
Della Torre, Joaquín
Camisia González, Santiago Romero Domínguez, Braulio Villegas González, Alejandro

## Índice

1. Propuesta de valor. | 2
2. Segmentos de clientes. | 3
3. Canales y relación con clientes. | 3
3.2. ¿Cómo va a ser la relación entre AgroNomad y quien compra el sistema? . | 4
4. Fuentes de ingreso y costos. | 5
5. Recursos, actividades y socios clave | 5
5.1. ¿Qué tiene que hacer AgroNomad para entregar su propuesta de valor? . . | 5

1. Propuesta de valor.

### 1.1. ¿Qué problema resuelve AgroNomad?

AgroNomad permite monitorear en tiempo real la ubicación y determinadas variables de los animales mediante collares inteligentes conectados por LoRa, centralizando la información en una plataforma web para facilitar la gestión y detección de situaciones anormales.
Por ejemplo, un productor puede tener:

Dificultad para saber dónde están determinados animales.

Necesidad de recorrer grandes superficies para encontrarlos;

Poca información histórica sobre movimiento;

Dificultad para detectar comportamientos anormales;

Información dispersa o registrada manualmente;

Pérdida de tiempo en tareas de monitoreo.

### 1.2. ¿Por qué alguien pagaría por utilizarlo?

AgroNomad es capaz de solucionar todas estas problemáticas a través de múltiples servicios que puede ofrecer el sistema como son:

Ubicación: Se brinda en tiempo real la posición del animal, el historial de movimiento y la delimitación de potreros, todo esto sobre un mapa.

Información del animal: Proporciona información acerca del animal (tipo, edad, estado, nombre) y permite guardar información extra sobre este por parte del usuario en caso de ser necesario.

Monitoreo: Permite realizar una medición acerca de variables como la temperatura del animal, cantidad de movimiento, actividad y periodos de descanso.

Análisis: Capacidad de ver análisis ya realizados por el propio sistema informático con datos como la distancia recorrida por todo el ganado, el tiempo de movimiento, de descanso e historial diario.

Alertas: Una de las cualidades más importantes, ya que el sistema es capaz de alertar si un animal sale fuera de su área delimitada en el programa o si hay una anomalía con algún animal, como falta de movimiento o posible problema de salud.


Figura 1: Imagen que ilustra cómo se ve el sistema de gestión de AgroNomad.

2. Segmentos de clientes.

### 2.1. ¿Quién pagaría por AgroNomad?

Productores ganaderos: Especialmente establecimientos que tengan grandes extensiones, muchos animales y dificultad para monitorearlos manualmente.

Feedlots: Podrían utilizar el sistema para monitoreo, identificación, comportamiento y control de sus animales.

Establecimientos agropecuarios tecnológicos: Productores que ya utilizan sistemas como estaciones meteorológicas o sistemas de trazabilidad podrían complementarse adecuadamente con el sistema AgroNomad.

Veterinarios: Podría servirle al personal médico encargado del ganado para prevenir de manera más acertada alguna posible enfermedad en un animal.

3. Canales y relación con clientes.

### 3.1. ¿Cómo llega AgroNomad hasta el cliente?

Para la comercialización de AgroNomad existen diferentes métodos para llegar al cliente en primera instancia:

Redes sociales: Las redes sociales serían principalmente un canal de difusión y generación de interés, más que el lugar donde necesariamente se realiza la venta. A través de contenido de videos donde se muestren distintas problemáticas en el campo ganadero y cómo AgroNomad es capaz de solucionarlas.

Página Web/WhatsApp: La Página Web y WhatsApp servirán para convertir la atención captada por las redes sociales en interés comercial directo, tener contacto directo con los interesados y hasta poder darles demostraciones limitadas del sistema junto con evidencia real de funcionamiento para impulsar la venta.

Venta directa: No solo es posible esperar a que los clientes encuentren AgroNomad; también resulta muy buena idea salir a buscar estos potenciales clientes, que se encuentren integrados dentro del rubro de la ganadería y puedan sacarle valor al producto (venta B2B directa).

Demostraciones en establecimientos: Ofrecer pruebas piloto gratuitas a productores ganaderos, las cuales nos permitirían, además de probar el sistema a gran escala, difundirlo y obtener una retroalimentación acerca de cómo le sirve al productor.

Ferias y exposiciones agropecuarias: Este canal es especialmente interesante porque permite colocar el producto delante de personas que ya pertenecen al sector. Por ejemplo, la Exposición Rural, que reúne productores, empresas y especialistas, y presentó desarrollos de tecnología aplicada al sector agropecuario.

Veterinarios como canal: Por último, esta opción también puede ser viable, ya que podría convertirse en un canal B2B2C. Un veterinario podría conocer AgroNomad, utilizarlo con algunos establecimientos y recomendarlo.

### 3.2. ¿Cómo va a ser la relación entre AgroNomad y quien compra el sistema?

La idea de AgroNomad es que perdure en el tiempo como un servicio, en el cual se dé a los clientes:

Instalación: El equipo de AgroNomad puede encargarse de configurar la base del sistema tanto en términos de software como de hardware. Instalar los receptores, configurar los collares específicamente para cada animal y registrar el establecimiento.

Soporte: En caso de problemas, el cliente puede contactarse directamente con nosotros, por ejemplo, para saber cómo acceder al sistema de gestión web o cómo ingresar información acerca de un animal.

Mantenimiento: En caso de ser necesario, se podría tratar el reemplazo de collares, baterías, mantenimiento de la estación terrestre, actualizaciones de software y de firmware del collar.

4. Fuentes de ingreso y costos.

### 4.1. ¿Cómo gana dinero AgroNomad?

Existen dos maneras principales en las que puede ganar dinero AgroNomad.

Venta de hardware/Instalación: Una vez concretada la venta por un monto exacto de collares y determinada cantidad de estaciones receptoras requeridas, se cobrará además el costo de instalación en caso de que el cliente quiera adquirirlo, dando a su vez una garantía. De lo contrario, en caso de que el cliente quiera instalarlo por su cuenta, no se dará garantía si a la hora de la puesta a punto algún dispositivo se rompe por culpa de una mala instalación.

Suscripción mensual: Luego de ser instalado por completo se cobrará una suscripción mensual, que en caso de ser pagada anualmente proporcionará un descuento. Esta le dará al usuario el acceso completo al software de monitoreo de su establecimiento, junto con el soporte y mantenimiento del mismo.

### 4.2. ¿Cuánto cuesta mantener AgroNomad funcionando?

AgroNomad, al no tratarse de solamente un producto de software sino un producto y servicio físico que necesita ser distribuido y tener un soporte constante, posee una estructura de costos muy extensa. Es por esto que solamente se hará el desarrollo económico de lo que costaría poner en marcha el MVP (mínimo producto viable).

Categoría | Tipo de costo | Ejemplos
Hardware Gateway Hosting Base de datos Conectividad Dominio Mantenimiento Soporte Logística Marketing Administración Garantías | Variable Inicial Fijo/variable Fijo/variable Variable Anual Recurrente Recurrente Variable Recurrente Recurrente Variable | Collar, sensores, GPS, LoRa, batería Raspberry Pi, receptor, antena Backend, frontend, servidor PostgreSQL/PostGIS, almacenamiento Internet o 4G del establecimiento .com.ar, .com Software, firmware, reparaciones Atención al cliente y asistencia técnica Envíos, combustible, instalaciones Publicidad y ferias Contador, impuestos, seguros Reemplazo de dispositivos defectuosos

Cuadro 1: Desglose de categorías y tipos de costos del proyecto en su totalidad.

## 5. Recursos, actividades y socios clave

### 5.1. ¿Qué tiene que hacer AgroNomad para entregar su propuesta de valor?

Para entregar su propuesta de valor AgroNomad debe explorar y realizar un desarrollo en seis grandes áreas que involucran diferentes factores como el desarrollo de producto, tanto software como hardware; el monitoreo y análisis de datos; la instalación y soporte del sistema; y además la distribución del producto a los distintos clientes una vez que empiece a ser comercializado.

Area ´ | Actividades
Desarrollo tecnológi-co Infraestructura y da-tos Análisis y monitoreo Producción e imple-mentación Soporte y mejora Comercialización | Hardware, firmware, software, backend, frontend LoRa, gateway, servidores, PostgreSQL/PostGIS, alma-cenamiento GPS, métricas, historial, geofencing, alertas y detección de anomalías Fabricación, ensamblaje, pruebas, instalación y configu-ración Mantenimiento, reparación, actualizaciones, capacita-ción y feedback Demostraciones, búsqueda de clientes, ventas y genera-ción de contenido

Cuadro 2: Desglose de las áreas de trabajo y sus actividades principales.

5.2. Socios clave.

Para poder crecer en el desarrollo de tecnología para el sector agropecuario resulta sumamente necesario hacer vínculos y contactos con:

Proveedores electrónicos: Uno de los vínculos más importantes, ya que estos proveerán los insumos necesarios como componentes, baterías, sensores y PCBs para poder ensamblar los collares y estaciones receptoras.

Fabricantes: Obtener contacto directo con fabricantes de PCBAs, que sean capaces de transformar los diseños electrónicos en un producto listo y confiable para su uso.

Empresas Agropecuarias: Para probar el producto en condiciones reales y obtener una retroalimentación (feedback) real.

Veterinarios: Para validar qué variables realmente son útiles en el análisis del comportamiento animal.

### 5.3. ¿Qué necesitamos para que AgroNomad pueda funcionar?

Una vez vistos todos estos costos, para poder llevar a cabo el análisis del MVP se tomará en consideración el desarrollo de hardware y fabricación de un collar inteligente (AgroNeck) y una estación de recepción terrestre (AgroBot).

5.4. Costos MVP.

AgroNeck: Collar inteligente que se incorpora al animal, posee carga solar autónoma, batería para mantener la energía, sistema inteligente de detección de movimiento por medio de acelerómetro, sistema de posicionamiento GPS y transmisión de información del animal (identificación, estado, temperatura, cantidad de movimiento, posición) por medio de un sistema de radiofrecuencia de largo alcance. Costos por componente/pieza para desarrollo del collar:

- Microcontrolador (ESP32 DevKit V1): 12,85$USD.
- Transmisor (Módulo LoRa SX1278): 8,4$USD.
- GPS (Módulo GPS NEO6MV2): 2,4$USD.
- Acelerómetro (MPU-6050): 2,65$USD.
- Sensor de Temperatura (MLX90614): 13,73$USD.
- Sensor de Temperatura ambiente (LM35): 1,99$USD.
- Panel Solar (5W): 15,96$USD.
- Demás componentes electrónicos: 45,16$USD.

Costo por AgroNeck: 103,14$USD.


Figura 2: Fotografía del AgroNeck.


Figura 3: Fotografía del AgroNeck y sus componentes internos.

AgroBot: Estación receptora y procesadora de información en tierra, la cual equipa otro módulo LoRa para la recepción de información proveniente de los collares y GPS para obtener referencia fija en tierra. A su vez poseerá una pantalla para poder mostrar los datos recibidos en el sistema de gestión.

- Computadora (Raspberry Pi Zero 2W): 31,41$USD.
- Receptor (Módulo LoRa SX1278): 8,4$USD.
- GPS (Módulo GPS NEO6MV2): 2,4$USD.
- Pantalla (LCD Touch 5” HDMI Raspberry Pi): 51,97$USD.

Costo del AgroBot: 94,18$USD.


Figura 4: Fotografía del AgroBot.


Figura 5: Fotografía del AgroBot y sus componentes internos.

Habiendo realizado ya el análisis de cuánto cuesta fabricar cada uno de estos dispositivos, pasemos a analizar un caso real de uso. Por ejemplo, si tenemos un cliente con un campo de 10 animales vacunos, la implementación de un collar para cada uno de estos costaría en total 1.031,4$USD. A esto hay que sumarle el costo de una estación receptora siempre y cuando estos animales vayan a monitorizarse hasta como máximo 3 km de distancia con respecto a esta. En términos de área, el total que puede abarcar un receptor es de 28.274.334 m² (unas 2.827 hectáreas o 28,2 km²). Esto ya viene definido por el fabricante de los módulos de radiofrecuencia en sus hojas de datos. Ahora se procederá con el análisis de costos de la implementación y mantenimiento de este sistema:

Costos únicos:

Collares x10: 1.031,4$USD.

Estación receptora x1: 94,18$USD.

Instalación x1: 400$USD.

Total: 1.525,58$USD.

Costos mensuales:

Mantenimiento: 200$USD.

Servicio de almacenamiento en la nube (opcional): 10$USD.

Total: 210$USD.

5.5. Factibilidad.

Concluyendo, podemos decir que para el proceso de venta de hardware e instalación del producto estaríamos cobrando en total 1.525,58$USD, para finalizar con una cuota mensual de 210$USD, que le permite al cliente mantener toda la información de su ganado en internet, y así ni siquiera requerir encontrarse en el establecimiento para monitorear el sistema o ser alertado por el mismo. Esto permite cubrir un área total de 28,2 km², vista en forma de circunferencia con el receptor en el centro de esta.
Ahora, teniendo en cuenta que el valor promedio de un animal como la vaca ronda los 800$USD, resulta totalmente razonable invertir solamente el doble de lo que vale una de estas por la implementación de un sistema que le brindará tranquilidad y organización plena en su establecimiento.

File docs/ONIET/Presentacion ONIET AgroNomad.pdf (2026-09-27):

# AgroNomad

- D ella Torre, Joaquín
- Gonzalez Camiscia , Santiago
- Romero Dominguez, Braulio
- Villegas Gonzalez , Alejandro


# 01 Componentes del Proyecto

### Solución tecnológica en el sector agropecuario

AGRONECK; — C ollares Smart en Campo
AGROBOT; — Estación fija de Recepción
AGROSERVER; — Dashboard; de Usuario

02 | AgroNeck


Prestaciones integradas en el | AgroNeck

Ubicación GPS y registro de actividad diaria.

Autonomía energética solar.

Medición de temperatura interna estimada.

Asignación de perfil haciendo a cada AgroNeck un collar único por cada animal.

Sistema de ahorro energético “Deep Sleep”.

02 | AgroNeck


Diagrama de | bloques
Microcontrolador | — ESP32
Módulo GPS | — NEO6MV2
Módulo LoRa | — XL1278

Sensado Temp. Int . — MLX90614

Acelerómetro — MPU6050

### Módulos

Sensado Temp. Ext. — LM35

03 | AgroBot


Un AgroBot es una estación de recepción
de datos fija | encargada de recibir y
procesar los datos de los | AgroNecks | .
Los AgroBots | son los centros de control del ecosistema | AgroNomad | .
Cada AgroBot generará una | dashboard
llamada AgroServer | que será la interfaz
del usuario.
El AgroServer | también podrá ser abierto
en dispositivos conectados a la red | Wi -Fi
que genera el | AgroBot .
Arquitectura | Diagrama de | bloques

04 | AgroServer


Mapeo del área de trabajo establecida y posición de los animales.

Asignación de perfil a cada collar con información fundamental del animal.

Observación de distancia recorrida por el animal durante el día.
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

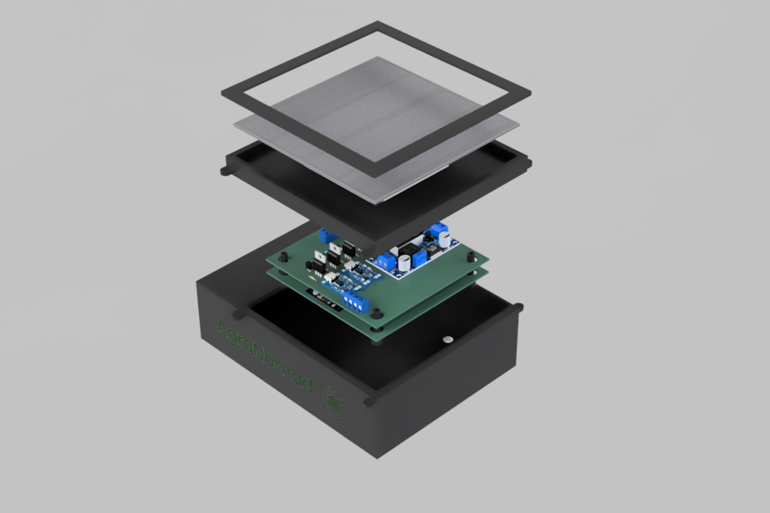
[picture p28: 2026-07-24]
mechanical/Renders/AgroNeck2.PNG

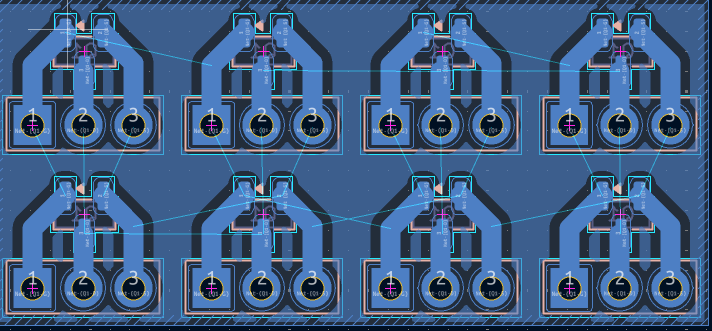
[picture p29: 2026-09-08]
hardware/MOSFETAdapter/AdapterPCB.png

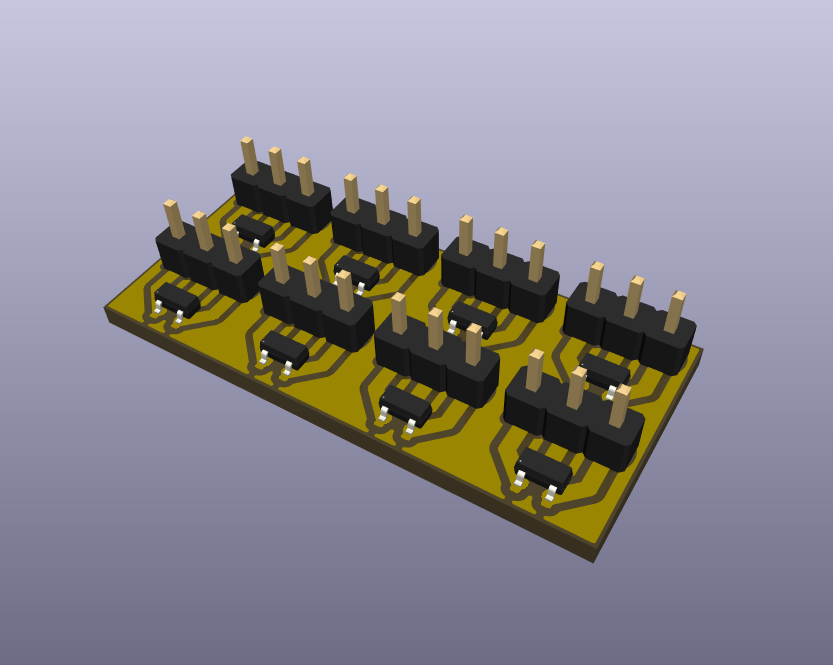
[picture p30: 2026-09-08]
hardware/MOSFETAdapter/Adapter3D.png

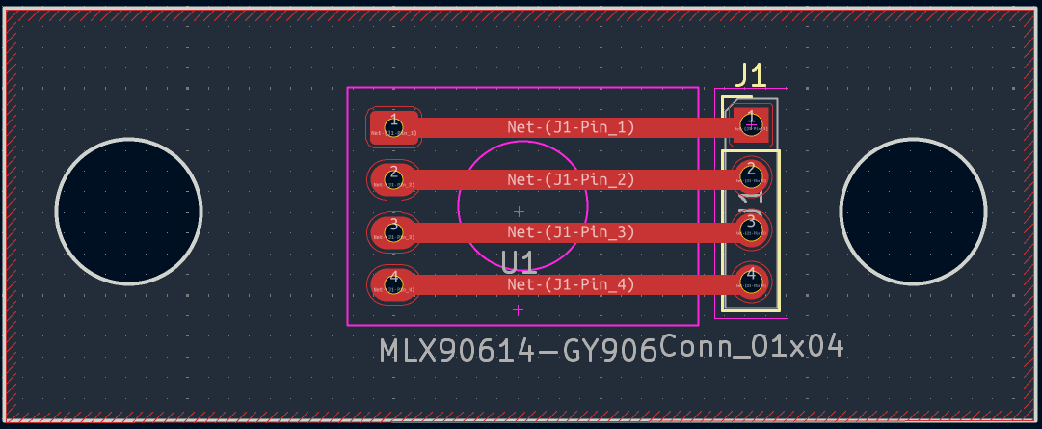
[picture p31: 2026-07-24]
hardware/MLXModule/MLXModulePCB.png

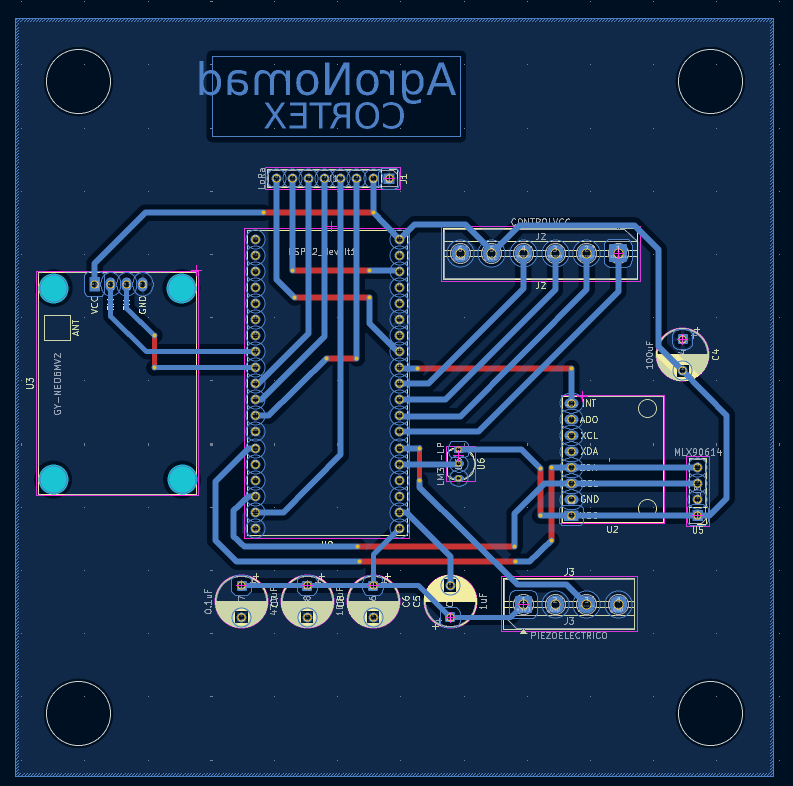
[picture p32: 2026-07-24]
hardware/Cortex/CortexPCB.png

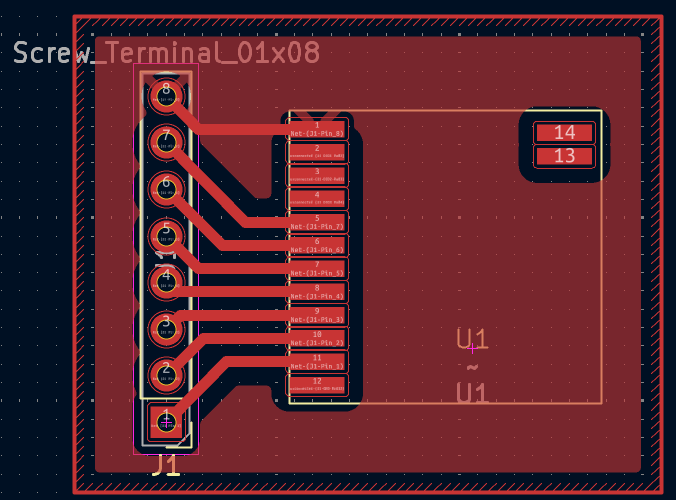
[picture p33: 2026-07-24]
hardware/LoraShield/LoraShieldPCB.png

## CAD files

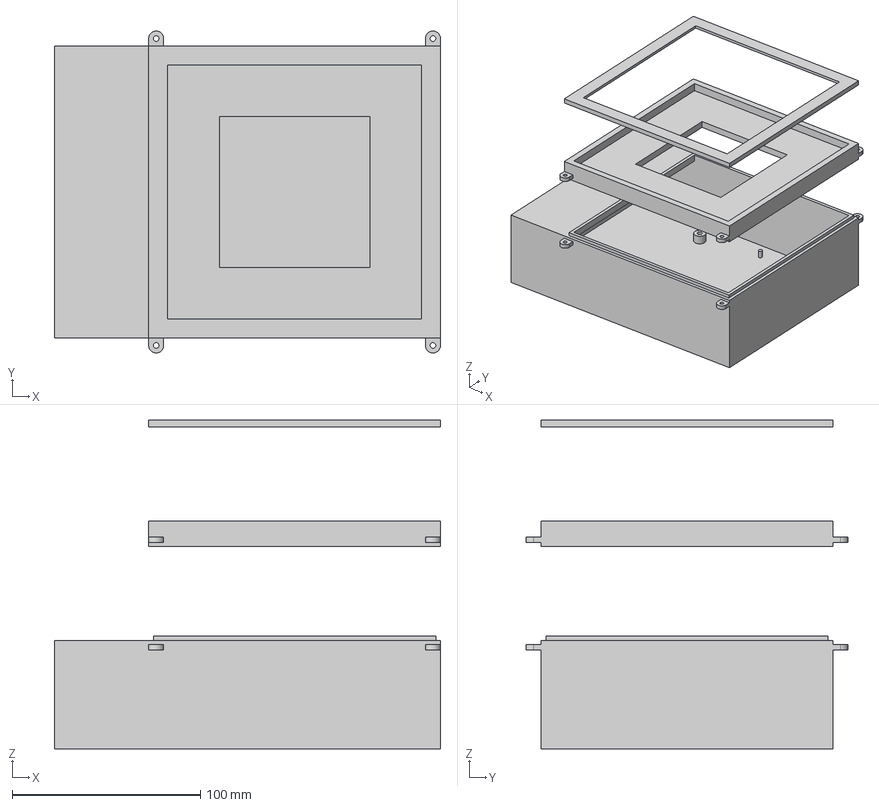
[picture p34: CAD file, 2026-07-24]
mechanical/Step/AgroNeck.step
205.0 x 171.0 x 174.5 mm

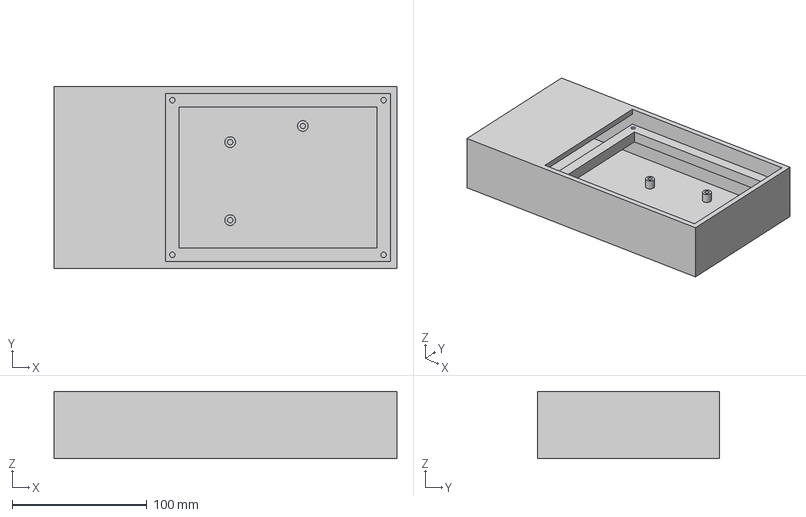
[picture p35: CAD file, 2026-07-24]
mechanical/Step/AgroBot.step
255.0 x 135.0 x 50.0 mm

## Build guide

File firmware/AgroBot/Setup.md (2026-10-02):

# AgroBot: instalación y prueba completa

Esta guía cubre la Raspberry Pi Zero 2 W, la placa AgroBot con SX1278, el backend, la base PostgreSQL/PostGIS, el frontend y el AgroNeck transmisor.

## Antes de empezar

- Raspberry Pi OS Lite de 64 bits con acceso a la red local.
- Node.js 24 o superior y npm instalados en la Pi.
- PostgreSQL con PostGIS, CMake y GCC instalados en la Pi.
- ESP-IDF configurado en la computadora que se use para compilar y flashear el AgroNeck.

Para preparar por primera vez el sistema operativo, Node.js y PostgreSQL, seguí también [RequirementsPI.md](RequirementsPI.md). El receptor del AgroBot es un programa Linux y no necesita ESP-IDF; los comandos `idf.py` de esta guía son solo para el AgroNeck.

## 1. Habilitar SPI en Raspberry Pi OS

Ejecutá:

```bash
sudo raspi-config
```

Seleccioná **Interface Options → SPI → Enable** y reiniciá:

```bash
sudo reboot
```

Después del reinicio, comprobá que estén presentes los dispositivos de SPI y GPIO:

```bash
ls -l /dev/spidev0.0 /dev/gpiochip0
```

Si falta `/dev/spidev0.0`, volvé a habilitar SPI y reiniciá antes de continuar.

## 2. Preparar PostgreSQL y PostGIS

PostgreSQL y la extensión PostGIS deben estar instalados. Iniciá PostgreSQL:

```bash
sudo systemctl enable --now postgresql
```

Si la base y el usuario todavía no existen, crealos una sola vez:

```bash
sudo -u postgres createuser --pwprompt agronomad
sudo -u postgres createdb --owner=agronomad agronomad
sudo -u postgres psql -d agronomad -c 'CREATE EXTENSION IF NOT EXISTS postgis;'
```

Editá `firmware/AgroBot/server/.env` para que la conexión apunte a `localhost:5432`, base `agronomad`, usuario `agronomad` y la contraseña configurada. El código prioriza `DATABASE_URL` si está definido; actualizá ese valor, o quitálo para usar las variables `PGHOST`, `PGPORT`, `PGDATABASE`, `PGUSER` y `PGPASSWORD`. No publiques credenciales.

Comprobá PostGIS:

```bash
sudo -u postgres psql -d agronomad -c 'SELECT PostGIS_Version();'
```

## 3. Compilar los programas de AgroBot

Desde la raíz del repositorio:

```bash
cd firmware/AgroBot/firmware
cmake -S . -B build
cmake --build build -j2
```

Se generan dos ejecutables: `build/agrobot-lora-receiver`, para recibir LoRa en la Raspberry, y `build/agro-neck-client`, el simulador TCP para pruebas sin radio.

Si actualizaste el código en otra computadora, copiá esos cambios a la Raspberry antes de compilar. Podés confirmar la configuración del receptor con:

```bash
grep -nE '0x06|0x07|Listening for' lora_receiver.c
```

Para 433 MHz debe mostrar `0x6C`, `0x40` y `433 MHz`. Después recompilá:

```bash
cmake --build build --clean-first -j2
```

## 4. Arrancar el backend

En una terminal de la Raspberry:

```bash
cd firmware/AgroBot/server
npm install
npm run dev
```

El backend inicializa el esquema y carga datos de demostración al conectarse a la base. Esperá los mensajes:

```text
HTTP server listening on port 4000
TCP telemetry server listening on port 4001
```

En otra terminal, probá la API:

```bash
curl -fsS http://127.0.0.1:4000/api/status
```

La respuesta debe indicar `"status":"ok"`. Dejá el backend corriendo.

## 5. Arrancar el receptor LoRa

En otra terminal, con la placa conectada y el backend activo:

```bash
cd firmware/AgroBot/firmware
sudo ./build/agrobot-lora-receiver
```

Debería mostrar la versión del SX1278 y luego:

```text
Listening for AgroNeck LoRa packets at 433 MHz
```

Dejá el receptor corriendo antes de encender o despertar el AgroNeck. `sudo` permite abrir `/dev/spidev0.0` y solicitar las líneas GPIO.

## 6. Flashear y despertar el AgroNeck

En una computadora con ESP-IDF configurado y la ESP32 del collar conectada por USB:

```bash
cd firmware/AgroNeck
idf.py set-target esp32
idf.py build
idf.py -p /dev/ttyUSB0 flash monitor
```

Reemplazá `/dev/ttyUSB0` por el puerto serie real. El primer arranque del firmware configura la interrupción de movimiento y entra en deep sleep. Con el receptor LoRa ya corriendo, mové el collar para despertarlo y provocar la lectura/transmisión. La radio se inicializa antes de transmitir; ambos módulos están configurados para 433 MHz.

Al recibir una trama, la terminal del receptor debe mostrar `collar=122`, temperatura y coordenadas. La terminal del backend debe indicar que procesó el payload. El receptor decodifica los 14 bytes, los convierte a JSON y los envía por TCP a `127.0.0.1:4001`.

## 7. Abrir el frontend

Obtené la IP de la Raspberry:

```bash
hostname -I
```

En una nueva terminal de la Pi:

```bash
cd firmware/AgroBot/client
npm install
export VITE_API_BASE_URL=http://192.168.1.50:4000
npm run dev -- --host 0.0.0.0
```

Reemplazá `192.168.1.50` por la IP real de la Pi. Abrí desde un dispositivo conectado a la misma red la URL que muestre Vite, normalmente `http://192.168.1.50:5173`. El frontend usa esa dirección para la API y el WebSocket.

Después de la primera trama, el backend crea o actualiza el animal asociado al collar y el frontend debe mostrar su posición en el mapa.

## Orden de arranque

1. Habilitar SPI y confirmar `/dev/spidev0.0`.
2. Iniciar PostgreSQL y comprobar `.env`.
3. Compilar los ejecutables de AgroBot.
4. Arrancar el backend y comprobar `/api/status`.
5. Arrancar `agrobot-lora-receiver`.
6. Flashear o despertar el AgroNeck y comprobar la trama en las terminales.
7. Arrancar Vite y abrir el frontend desde la red local.

Para probar solo backend y frontend sin radio, ejecutá `sudo ./build/agro-neck-client` en lugar del receptor LoRa; ese cliente envía ubicaciones ficticias.

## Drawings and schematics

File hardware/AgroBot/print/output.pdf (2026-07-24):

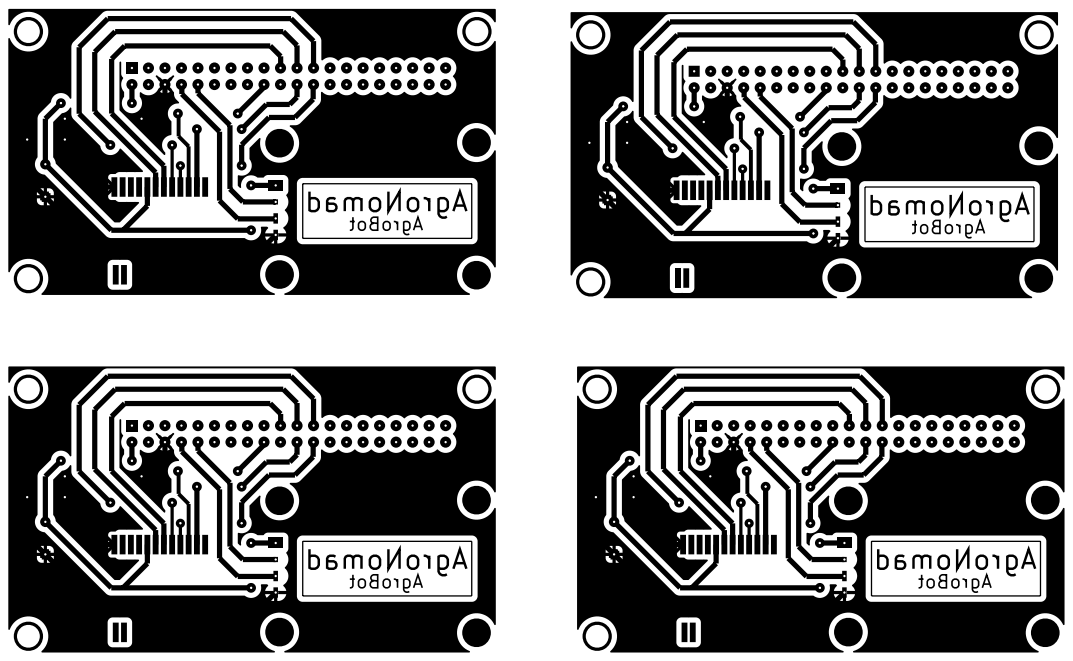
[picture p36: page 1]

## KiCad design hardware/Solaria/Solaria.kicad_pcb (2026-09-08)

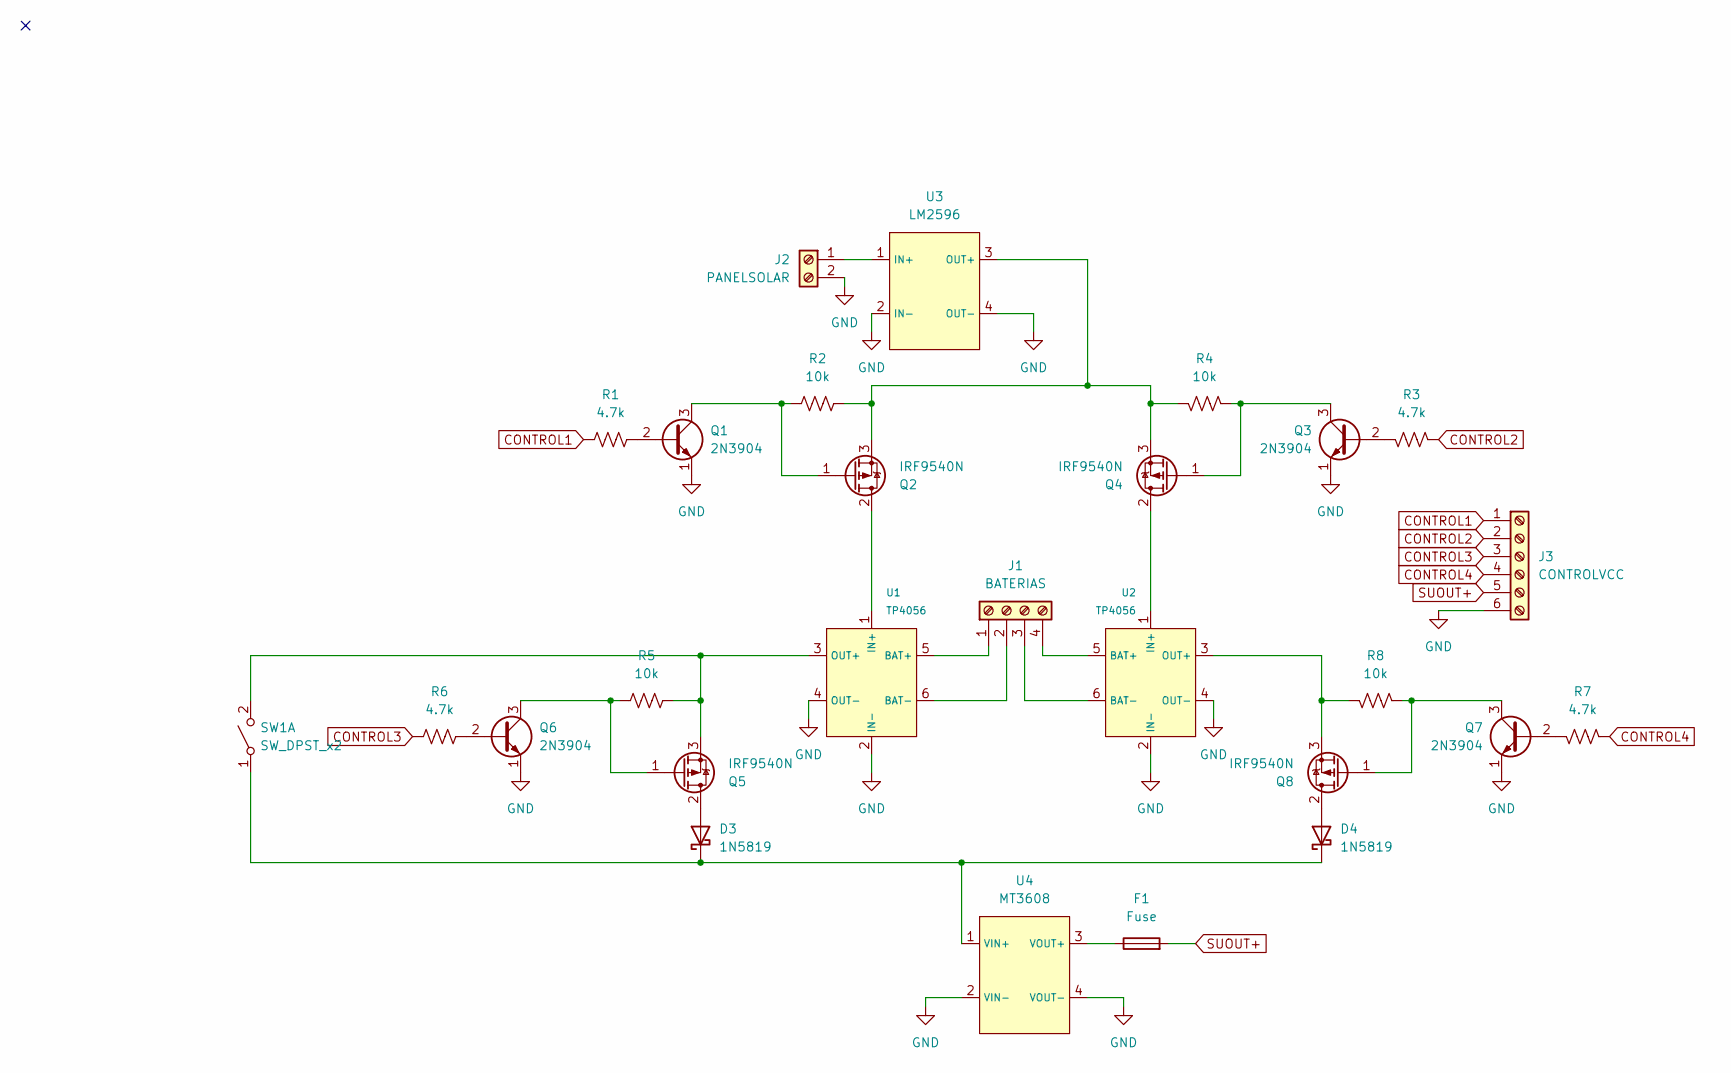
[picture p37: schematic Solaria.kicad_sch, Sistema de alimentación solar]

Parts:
D3, D4: 1N5819; D_DO-41_SOD81_P10.16mm_Horizontal
F1: Fuse; Fuseholder_Clip-5x20mm_Littelfuse_445-030_Inline_P20.50x5.2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
J1: BATERIAS; TerminalBlock_MaiXu_MX126-5.0-04P_1x04_P5.00mm
J2: PANELSOLAR; TerminalBlock_MaiXu_MX126-5.0-02P_1x02_P5.00mm
J3: CONTROLVCC; TerminalBlock_MaiXu_MX126-5.0-06P_1x06_P5.00mm
Q1, Q3, Q6, Q7: 2N3904; TO-92_Inline
Q2, Q4, Q5, Q8: IRF9540N; TO-220-3_Vertical
R1, R3, R6, R7: 4.7k; R_Axial_DIN0204_L3.6mm_D1.6mm_P7.62mm_Horizontal
R2, R4, R5, R8: 10k; R_Axial_DIN0204_L3.6mm_D1.6mm_P7.62mm_Horizontal
SW1: SW_DPST_x2; SW_PUSH-12mm_Wuerth-430476085716
U1, U2: TP4056
U3: LM2596
U4: MT3608

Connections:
CONTROL1: J3.1, R1.1
CONTROL2: J3.2, R3.1
CONTROL3: J3.3, R6.1
CONTROL4: J3.4, R7.1
GND: J2.2, J3.6, Q1.1 (E), Q3.1 (E), Q6.1 (E), Q7.1 (E), U1.2 (IN-), U1.4 (OUT-), U2.2 (IN-), U2.4 (OUT-), U3.2 (IN-), U3.4 (OUT-), U4.2 (VIN-), U4.4 (VOUT-)
unnamed: D3.2 (A), Q5.2 (D)
unnamed: D3.1 (K), D4.1 (K), SW1.1 (A), U4.1 (VIN+)
unnamed: D4.2 (A), Q8.2 (D)
unnamed: J1.1, U1.5 (BAT+)
unnamed: J1.2, U1.6 (BAT-)
unnamed: J1.3, U2.6 (BAT-)
unnamed: J1.4, U2.5 (BAT+)
unnamed: J2.1, U3.1 (IN+)
unnamed: Q1.2 (B), R1.2
unnamed: Q1.3 (C), Q2.1 (G), R2.1
unnamed: Q2.2 (D), U1.1 (IN+)
unnamed: Q2.3 (S), Q4.3 (S), R2.2, R4.2, U3.3 (OUT+)
unnamed: Q3.2 (B), R3.2
unnamed: Q3.3 (C), Q4.1 (G), R4.1
unnamed: Q4.2 (D), U2.1 (IN+)
unnamed: Q5.1 (G), Q6.3 (C), R5.1
unnamed: Q5.3 (S), R5.2, SW1.2 (B), U1.3 (OUT+)
unnamed: Q6.2 (B), R6.2
unnamed: Q7.2 (B), R7.2
unnamed: Q7.3 (C), Q8.1 (G), R8.1
unnamed: Q8.3 (S), R8.2, U2.3 (OUT+)
unnamed: F1.1, U4.3 (VOUT+)
SUOUT+: F1.2, J3.5

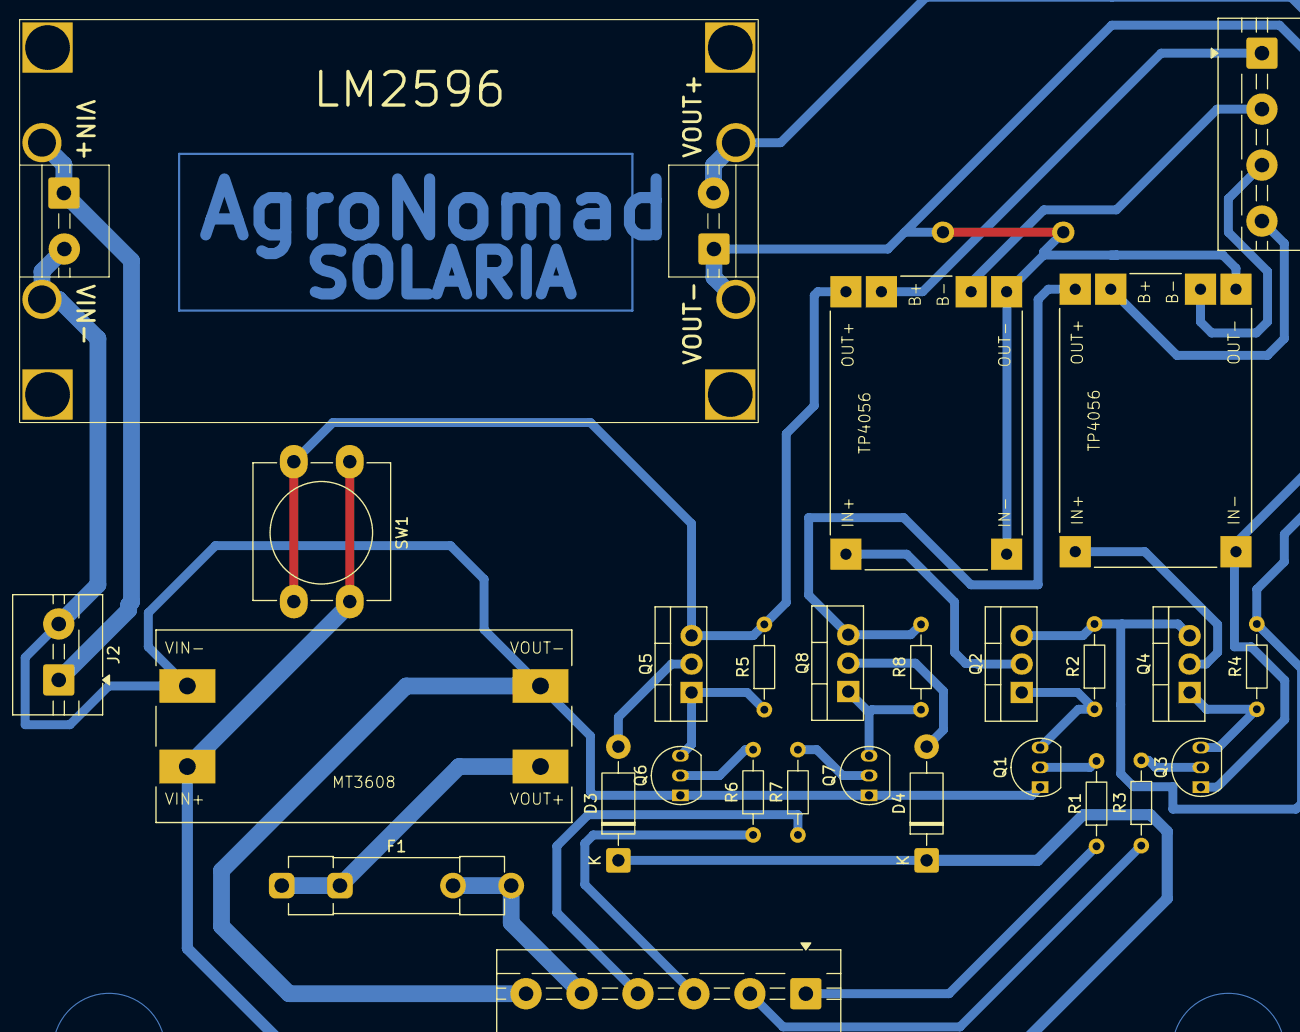
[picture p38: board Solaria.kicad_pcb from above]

Board: 2 copper layers, 27 parts (0 on the bottom side), 28 nets.

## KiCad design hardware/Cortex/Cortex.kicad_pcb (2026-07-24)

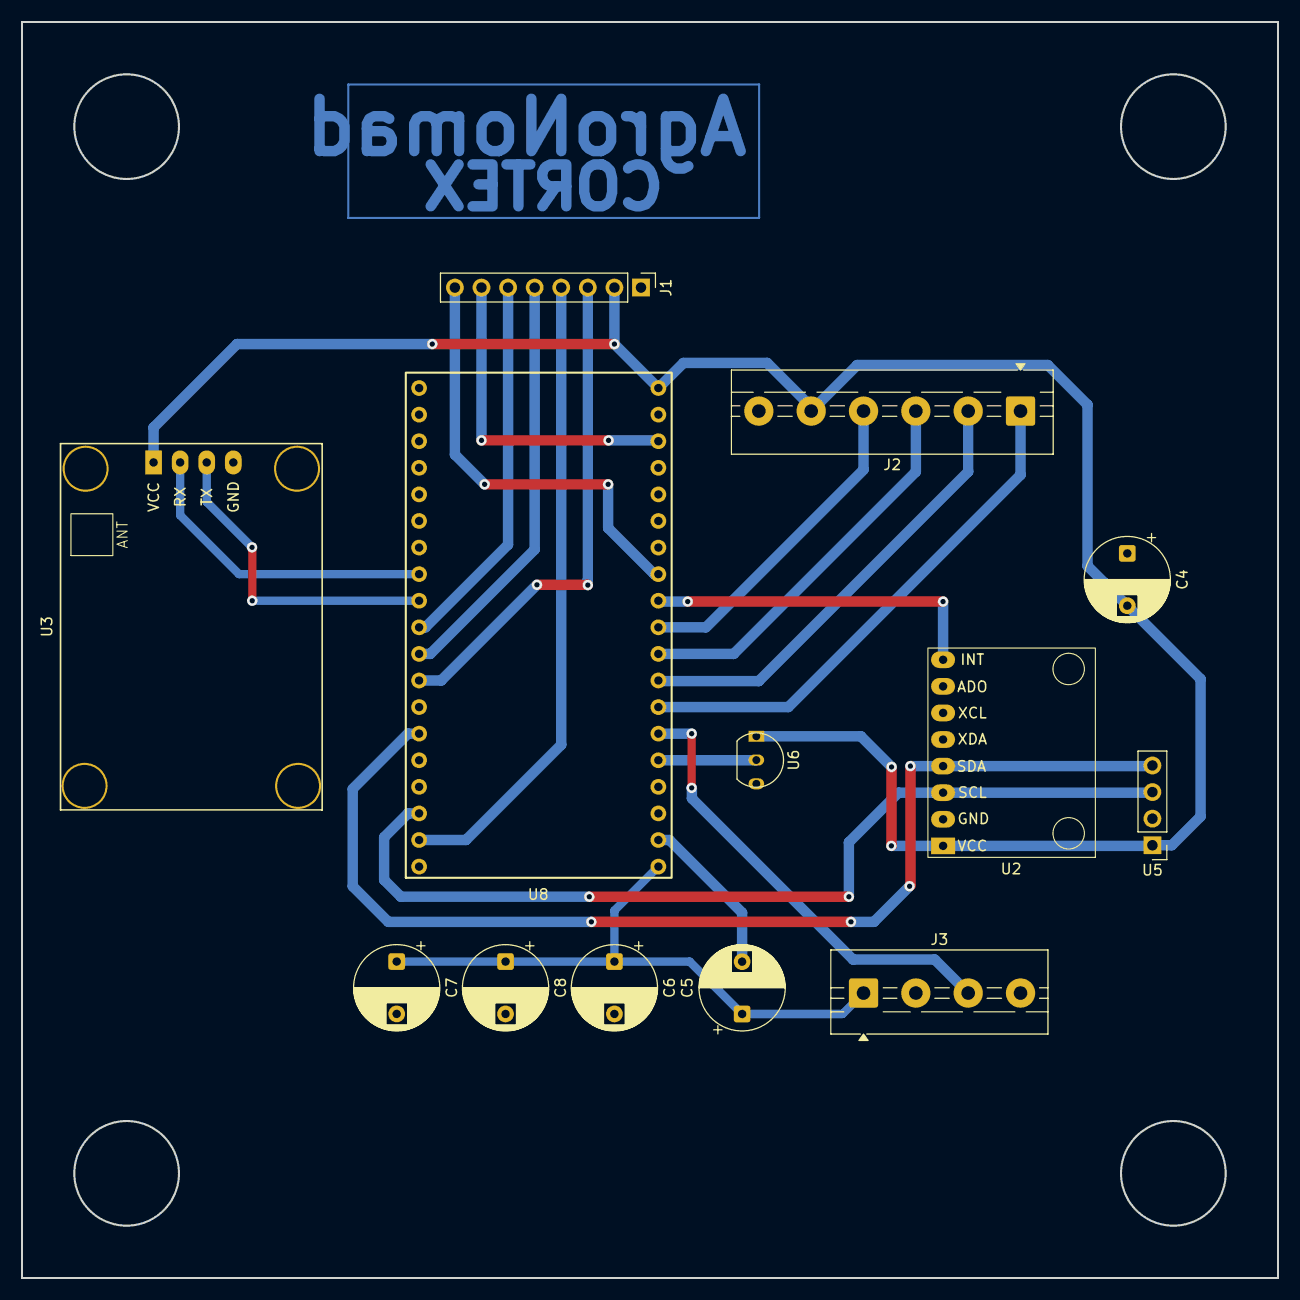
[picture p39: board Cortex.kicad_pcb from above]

Board: 2 copper layers, 120.0 x 120.0 mm, 13 parts (0 on the bottom side), 21 nets.

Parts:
C4, C6: 100uF; CP_Radial_D8.0mm_P5.00mm
C5: 1uF; CP_Radial_D8.0mm_P5.00mm
C7: 0.1uF; CP_Radial_D8.0mm_P5.00mm
C8: 470uF; CP_Radial_D8.0mm_P5.00mm
J1: LoRa; PinHeader_1x08_P2.54mm_Vertical
J2: CONTROLVCC; TerminalBlock_MaiXu_MX126-5.0-06P_1x06_P5.00mm
J3: PIEZOELECTRICO; TerminalBlock_MaiXu_MX126-5.0-04P_1x04_P5.00mm
U2: MPU6050
U3: GY-NEO6MV2
U5: MLX90614; PinHeader_1x04_P2.54mm_Vertical
U6: LM35-LP; TO-92_Inline
U8: ESP32_devkit1

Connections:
+3V3: C5.1, C6.1, C7.1, C8.1, J3.1, U8.1 (3.3V)
CONTROL1: J2.1, U8.7 (GPIO32)
CONTROL2: J2.2, U8.8 (GPIO33)
CONTROL3: J2.3, U8.9 (GPIO25)
CONTROL4: J2.4, U8.10 (GPIO26)
GND: C4.1, C6.2, C7.2, C8.2, J1.1, J2.6, J3.2, J3.4, U2.2 (GND), U3.4 (GND), U5.2 (GND), U6.3 (GND), U8.14 (GND), U8.20 (GND), U8.26 (GND)
LORA_CLK: J1.5, U8.28 (GPIO18)
LORA_CS: J1.6, U8.29 (GPIO5)
LORA_DIO0: J1.7, U8.17 (GPIO13)
LORA_MISO: J1.3, U8.27 (GPIO19)
LORA_MOSI: J1.4, U8.21 (GPIO23)
LORA_RESET: J1.8, U8.12 (GPIO14)
MLX_MPU6050_SCL: U2.3 (SCL), U5.3 (SCL), U8.22 (GPIO22)
MLX_MPU6050_SDA: U2.4 (SDA), U5.4 (SDA), U8.25 (GPIO21)
MPU6050_INT: U2.8 (INT), U8.11 (GPIO27)
NEO6M_RX: U3.2 (RX), U8.31 (GPIO16)
NEO6M_TX: U3.3 (TX), U8.30 (GPIO17)
unnamed: C5.2, U8.2 (EN)
PIEZOELECTRICO_OUT: J3.3, U8.6 (GPIO35)
VCC: C4.2, J1.2, J2.5, U2.1 (VCC), U3.1 (VCC), U5.1 (VIN), U6.1 (+V_{S}), U8.19 (VIN)
V_LM35: U6.2 (V_{OUT}), U8.5 (GPIO34)

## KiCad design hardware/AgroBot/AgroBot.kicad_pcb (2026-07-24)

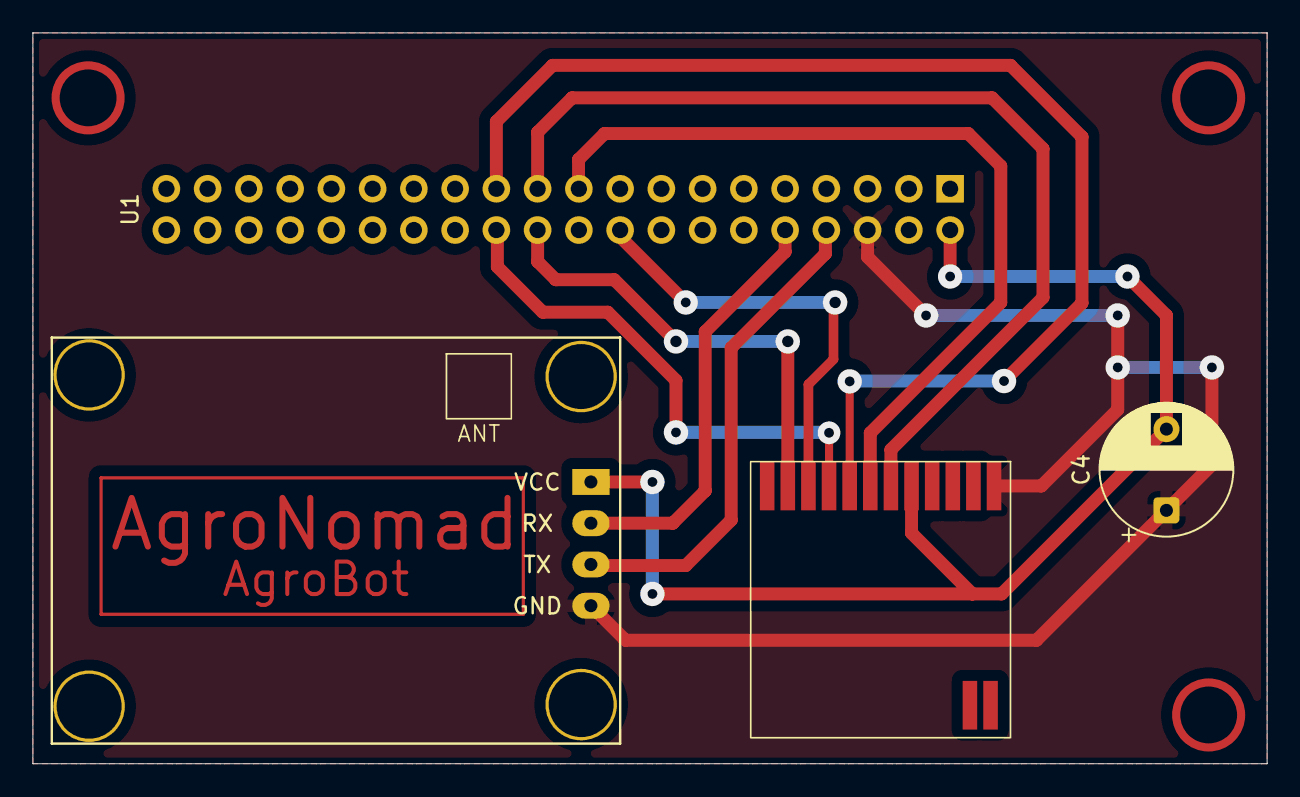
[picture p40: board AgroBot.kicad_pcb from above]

Board: 2 copper layers, 76.0 x 45.0 mm, 4 parts (0 on the bottom side), 10 nets.

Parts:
C4: 100uF; CP_Radial_D8.0mm_P5.00mm
U1: Pi Zero 2 W; PinHeader_2x20_P2.54mm_Vertical
U2: XL1278
U3: GY-NEO6MV2

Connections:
GND: C4.1, U1.6 (GND), U2.1 (GND), U3.4 (GND)
GPS_RX: U1.10 (GPIO15), U3.2 (RX)
GPS_TX: U1.8 (GPIO14), U3.3 (TX)
LORA_CLK: U1.23 (GPIO11), U2.8 (SCLK)
LORA_CS: U1.24 (GPIO8), U2.9 (NSS)
LORA_DIO0: U1.18 (GPIO24), U2.10 (DIO0)
LORA_MISO: U1.21 (GPIO09), U2.6 (MISO)
LORA_MOSI: U1.19 (GPIO10), U2.7 (MOSI)
LORA_RESET: U1.22 (GPIO25), U2.11 (REST)
VCC: C4.2, U1.2 (+5V), U2.5 (VCC), U3.1 (VCC)

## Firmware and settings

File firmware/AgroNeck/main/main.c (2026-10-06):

// DEPENDENCIAS
#include <stdio.h>
#include <sys/time.h>
#include <stdbool.h>
#include <stdint.h>
#include "esp_log.h"    
#include "esp_system.h"
#include "esp_sleep.h"
#include "esp_timer.h"               
#include "esp_private/esp_clk.h"     
#include "esp_adc/adc_oneshot.h" 
#include "driver/gpio.h"
#include "driver/rtc_io.h"
#include "freertos/FreeRTOS.h"
#include "freertos/task.h"

#include "lora.h"       // Librería para el módulo LoRa
#include "neo6m.h"      // Librería para el módulo GPS NEO-6MV2
#include "mpumlx.h"     // Librería para el sensor de movimiento MPU6050
#include "lm35.h"       // Librería para el sensor de temperatura LM35

// MODO SLEEP
#define WAKEUP_GPIO     27 // GPIO que despierta del modo sleep 
#define WAKEUP_LEVEL    1  // Activarse con nivel alto/flanco ascendente

// CONTROL DE ALIMENTACIÓN - C1+C4 o C2+C3
#define MOSFET1 25 // GPIO del MOSFET CONTROL3
#define MOSFET2 26 // GPIO del MOSFET CONTROL4
#define MOSFET3 32 // GPIO del MOSFET CONTROL1
#define MOSFET4 33 // GPIO del MOSFET CONTROL2

// Mascara de manejo de los 4 pines
#define GPIO_MOSFET_MASK ((1ULL<<MOSFET1) | (1ULL<<MOSFET2) | (1ULL<<MOSFET3) | (1ULL<<MOSFET4))

// Variables guardadas en memoria RTC (sobreviven al Deep Sleep)
RTC_DATA_ATTR bool estado_mosfet = true; // true = estado inicial (2+3), false = estado secundario (1+4)
RTC_DATA_ATTR uint64_t tiempo_switch = 0;
RTC_DATA_ATTR bool sistema_inicializado = false;

// Conmutación de baterías
#define TIEMPO_CAMBIO_BATS 10

// VARIABLES DE DATOS
double latitude; double longitude; char lat_hemisphere; char lon_hemisphere; float velocidad;
#define Vout_LM35       34 
#define H_COEFICIENTE   0.18f 
float lm_amb_temp;  
mlx90614_data_t mlx_data; 
float temp_interna; 

// Inicialización de Salida de MOSFETs
void init_mosfet_gpios() {
    gpio_deep_sleep_hold_dis();
    gpio_hold_dis(MOSFET1);
    gpio_hold_dis(MOSFET2);
    gpio_hold_dis(MOSFET3);
    gpio_hold_dis(MOSFET4);

    gpio_config_t io_config = {
        .intr_type = GPIO_INTR_DISABLE,
        .mode = GPIO_MODE_OUTPUT,
        .pin_bit_mask = GPIO_MOSFET_MASK,
        .pull_down_en = GPIO_PULLDOWN_DISABLE,
        .pull_up_en = GPIO_PULLUP_DISABLE,
    };
    gpio_config(&io_config);
}

// Declara los estados de los MOSFETs
void aplica_estado_mosfet() {
    ESP_LOGI("MOSFETS","Aplicando estado %d...", estado_mosfet);
    if (estado_mosfet) { // Estado inicial: 2+3
        //gpio_set_level(MOSFET1, 0);
        //gpio_set_level(MOSFET4, 0);
        //gpio_set_level(MOSFET2, 1);
        //gpio_set_level(MOSFET3, 1);
        gpio_set_level(MOSFET2, 1);
        gpio_set_level(MOSFET3, 1);
        vTaskDelay(pdMS_TO_TICKS(1000));
        gpio_set_level(MOSFET1, 0);
        gpio_set_level(MOSFET4, 0);
    } else { // Estado secundario: 1+4
        //gpio_set_level(MOSFET2, 0);
        //gpio_set_level(MOSFET3, 0);
        //gpio_set_level(MOSFET1, 1);
        //gpio_set_level(MOSFET4, 1);
        gpio_set_level(MOSFET1, 1);
        gpio_set_level(MOSFET4, 1);
        vTaskDelay(pdMS_TO_TICKS(1000));
        gpio_set_level(MOSFET2, 0);
        gpio_set_level(MOSFET3, 0);
    }
}

// Switcheo de MOSFETs (alternar entre baterías)
void switch_mosfet() {
    ESP_LOGI("MOSFETS","Switcheando mosfets...");
    estado_mosfet = !estado_mosfet; 
    aplica_estado_mosfet();
}

uint64_t tiempo_medido(void) {
    struct timeval tv;
    gettimeofday(&tv, NULL);
    return (uint64_t)tv.tv_sec;
}

void hora_actual() {
    uint64_t tiempo_actual = tiempo_medido();

    // Si es el primer encendido físico del equipo
    if (!sistema_inicializado) {
        tiempo_switch = tiempo_actual;
        sistema_inicializado = true;
        aplica_estado_mosfet();
        ESP_LOGI("MAIN", "Tiempo base inicializado: %llu s", tiempo_switch);
        return;
    }

    uint64_t transcurrido = (tiempo_actual >= tiempo_switch) ? (tiempo_actual - tiempo_switch) : 0;
    ESP_LOGI("MOSFETS", "Tiempo actual: %llu s | Ultimo switch: %llu s | Transcurrido: %llu s", 
             tiempo_actual, tiempo_switch, transcurrido);

    // Evalúa si ya pasó el tiempo necesario para cambiar de batería
    if (transcurrido >= TIEMPO_CAMBIO_BATS) {
        switch_mosfet();
        tiempo_switch = tiempo_actual; // Se actualiza el tiempo base con la hora actual
    } else {
        ESP_LOGI("MOSFETS", "Aún no transcurrió el tiempo (%llu/%llu s). Se mantiene estado.", 
                 transcurrido, (uint64_t)TIEMPO_CAMBIO_BATS);
        aplica_estado_mosfet();
    }
}

/* FUNCIONES DE LECTURA DE SENSORES */
void read_lm35() {
    ESP_LOGI("read_lm35","Intentando leer LM35...");
    lm35_data_t data;
    esp_err_t ret = lm35_read(&data);
    if (ret == ESP_OK) {
        lm_amb_temp = data.lm_amb_temp;
        ESP_LOGI("LM35","Temperatura: %.2f °C", lm_amb_temp);
    } else {
        ESP_LOGE("LM35","Error leyendo LM35: %s", esp_err_to_name(ret));
    }
}

void read_gps() {
    ESP_LOGI("GPS","Intentando leer GPS...");
    raw_nmea(&latitude, &longitude, &lat_hemisphere, &lon_hemisphere, &velocidad);
    ESP_LOGI("GPS","Latitud: %f %c, Longitud: %f %c", latitude, lat_hemisphere, longitude, lon_hemisphere);
}

void read_mpu6050() {
    ESP_LOGI("MPU6050","Intentando leer MPU6050...");
    mpu6050_data_t data;
    esp_err_t ret = mpu6050_read(&data, I2C_NUM_0);
    if (ret == ESP_OK) {
        ESP_LOGI("MPU6050","Aceleración - X: %d, Y: %d, Z: %d", data.ax, data.ay, data.az);
        ESP_LOGI("MPU6050","Giroscopio - X: %d, Y: %d, Z: %d", data.gx, data.gy, data.gz);
    } else {
        ESP_LOGE("MPU6050","Error leyendo datos: %s", esp_err_to_name(ret));
    }
}

void read_mlx90614() {
    ESP_LOGI("MLX90614","Intentando leer MLX90614...");
    esp_err_t ret = mlx90614_read(&mlx_data, I2C_NUM_0);
    if (ret == ESP_OK) {
        ESP_LOGI("MLX90614","Temperatura objeto: %.2f °C", mlx_data.mlx_object_temp);
    } else {
        ESP_LOGE("MLX90614","Error leyendo datos: %s", esp_err_to_name(ret));
    }
}

/* FUNCIONES DE CALCULO Y PROCESAMIENTO DE DATOS */
void internal_temp() {
    ESP_LOGI("Temp.Calc","Calculando temperatura interna...");
    temp_interna = (mlx_data.mlx_object_temp) + (mlx_data.mlx_object_temp - (lm_amb_temp)) * H_COEFICIENTE;
    ESP_LOGI("Temp.Calc","Temperatura interna estimada: %.2f °C", temp_interna); 
}

void sensar_enviar(void *pvParameters){ 
    ESP_LOGI("func_sensar_enviar","Iniciando buses y perifericos.");
    gps_starting();
    init_i2c();
    mpu6050_init(I2C_NUM_0);
    lm35_init();
    init_mosfet_gpios();
    lora_init();

    ESP_LOGI("func_sensar_enviar","Leyendo todos los sensores...");
    read_gps();
    read_mpu6050();
    read_mlx90614();
    read_lm35();
    internal_temp();

    ESP_LOGI("func_sensar_enviar","Empaquetando y enviando...");
    payload_t paquete;
    paquete.id_collar = 122;
    paquete.temperatura = temp_interna;
    paquete.latitud = (int32_t)(-latitude * 1000000.0);
    paquete.longitud = (int32_t)(-longitude * 1000000.0);

    transmitir_datos(&paquete);

    // Evalúa y aplica el cambio de batería
    hora_actual();
    // Congelar estado de pines para Deep Sleep
    ESP_LOGI("func_sensar_enviar","Congelando MOSFETs...");
    gpio_hold_en(MOSFET1);
    gpio_hold_en(MOSFET2);
    gpio_hold_en(MOSFET3);
    gpio_hold_en(MOSFET4);
    gpio_deep_sleep_hold_en(); 

    mpu6050_enable_wom(I2C_NUM_0, MPU6050_THRESHOLD);

    ESP_LOGI("func_sensar_enviar","Limpiando INT MPU.");
    mpu6050_clear_int(I2C_NUM_0); 

    ESP_LOGI("func_sensar_enviar","Preparando interrupción antes de ir a dormir...");
    esp_sleep_enable_ext0_wakeup(WAKEUP_GPIO, WAKEUP_LEVEL);

    ESP_LOGI("func_sensar_enviar","Entrando en deep sleep...");
    vTaskDelay(pdMS_TO_TICKS(100));

    esp_deep_sleep_start();

    vTaskDelete(NULL);
}

// MAIN
void app_main(void)
{
    ESP_LOGI("MAIN","Comenzando los procesos principales");
    esp_sleep_wakeup_cause_t cause = esp_sleep_get_wakeup_cause();

    // Despierto por razones que no son Wake-On-Motion (Primer arranque / Reset)
    if (cause != ESP_SLEEP_WAKEUP_EXT0) { 
        ESP_LOGI("MAIN_fwu","Primer arranque, inicializando buses.");
        init_i2c(); 
        mpu6050_init(I2C_NUM_0);
        mpu6050_enable_wom(I2C_NUM_0, MPU6050_THRESHOLD); 
        mpu6050_clear_int(I2C_NUM_0);

        ESP_LOGI("MAIN_fwu","Inicio y congelo los mosfets.");
        init_mosfet_gpios();
        hora_actual();
        
        gpio_hold_en(MOSFET1);
        gpio_hold_en(MOSFET2);
        gpio_hold_en(MOSFET3);
        gpio_hold_en(MOSFET4);
        gpio_deep_sleep_hold_en(); // <--- OBLIGATORIO PARA DEEP SLEEP

        while(gpio_get_level(WAKEUP_GPIO) == 1) {
            vTaskDelay(pdMS_TO_TICKS(10));
        }
        
        ESP_LOGI("MAIN_fwu","Preparo interrupción.");
        esp_sleep_enable_ext0_wakeup(WAKEUP_GPIO, WAKEUP_LEVEL); 
        
        ESP_LOGI("MAIN_fwu","Entrando en deep sleep...");
        vTaskDelay(pdMS_TO_TICKS(100));
        
        esp_deep_sleep_start(); 
        return;
    }
  
    // Despierto de Deep Sleep por movimiento (EXT0)
    xTaskCreate(sensar_enviar, "sensar_enviar_task", 4096, NULL, 5, NULL);    

    
    /*

    //Función utilizada para probar el sistema sin Deep-Sleep
    ESP_LOGI("Inicializacion","Iniciando buses y perifericos.");
    gps_starting();
    init_i2c();
    mpu6050_init(I2C_NUM_0);
    lm35_init();
    init_mosfet_gpios();
    lora_init();

    while(1) {

        ESP_LOGI("Lectura","Leyendo todos los sensores...");
        read_gps();
        read_mpu6050();
        read_mlx90614();
        read_lm35();
        internal_temp();

        ESP_LOGI("LoRa","Empaquetando y enviando...");
        payload_t paquete;
        paquete.id_collar = 122;
        paquete.temperatura = temp_interna;
        paquete.latitud = (int32_t)(latitude * 1000000.0);
        paquete.longitud = (int32_t)(longitude * 1000000.0);

        transmitir_datos(&paquete);


        // Evalúa y aplica el cambio de batería
        ESP_LOGI("Energía","Analizando estado de switcheo.");
        hora_actual();
        vTaskDelay(pdMS_TO_TICKS(1000));
    }

    */

}

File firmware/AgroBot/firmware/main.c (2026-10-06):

#include <stdio.h>
#include <stdlib.h>
#include <stdint.h>
#include <string.h>
#include <unistd.h>
#include <arpa/inet.h>
#include <pthread.h>
#include <sys/socket.h>
#include <time.h>

#include "neo6m.h"
#include "lora.h"

#define SERIAL_PORT "/dev/ttyS0"//GPS

#define SERVER_IP "127.0.0.1"
#define SERVER_PORT 4001
#define SEND_INTERVAL_SECONDS 5
#define COLLAR_QUEUE_CAPACITY 32

//GPS NEO6M variables
int gps_fd = -1; // GPS serial port file descriptor
double temperature;

typedef struct {
    double latitude;
    double longitude;
    int gps_ready;
    agro_neck_payload_t collar_queue[COLLAR_QUEUE_CAPACITY];
    size_t collar_queue_head;
    size_t collar_queue_count;
} telemetry_state_t;

static telemetry_state_t telemetry_state;
static pthread_mutex_t telemetry_mutex = PTHREAD_MUTEX_INITIALIZER;
static pthread_cond_t telemetry_condition = PTHREAD_COND_INITIALIZER;

static int connect_to_backend(void)
{
    int sock = socket(AF_INET, SOCK_STREAM, 0);
    if (sock < 0)
    {
        perror("socket");
        return -1;
    }

    struct sockaddr_in server_addr;
    memset(&server_addr, 0, sizeof(server_addr));
    server_addr.sin_family = AF_INET;
    server_addr.sin_port = htons(SERVER_PORT);

    if (inet_pton(AF_INET, SERVER_IP, &server_addr.sin_addr) != 1)
    {
        fprintf(stderr, "Invalid backend IP address: %s\n", SERVER_IP);
        close(sock);
        return -1;
    }

    if (connect(sock, (struct sockaddr *)&server_addr, sizeof(server_addr)) < 0)
    {
        perror("connect");
        close(sock);
        return -1;
    }

    printf("Connected to AgroBot backend at %s:%d\n", SERVER_IP, SERVER_PORT);
    return sock;
}

static int send_telemetry(int sock, const char *source, const char *payload)
{
    size_t length = strlen(payload);
    size_t sent = 0;

    while (sent < length)
    {
        ssize_t result = send(sock, payload + sent, length - sent, 0);
        if (result <= 0)
        {
            perror("send");
            return -1;
        }
        sent += (size_t)result;
    }

    printf("[Backend] Sent %s telemetry: %s", source, payload);
    return 0;
}

static uint8_t gps_listening(double *latitude, double *longitude)
{
    char lat_hemisphere;
    char lon_hemisphere;
    double speed_kmh = 0.0;

    if (neo6m_read_data(gps_fd, latitude, longitude,
                        &lat_hemisphere, &lon_hemisphere, &speed_kmh) == 0) {
        //printf("Received GPS data:\n");
        //printf("Latitude: %f %c\n", *latitude, lat_hemisphere);
        //printf("Longitude: %f %c\n", *longitude, lon_hemisphere);
        return 0;
    }
    printf("No GPS data received within the timeout period.\n");
    return 1;
}

static void *gps_worker(void *argument)
{
    (void)argument;

    for (;;) {
        double latitude = 0.0;
        double longitude = 0.0;

        if (gps_listening(&latitude, &longitude) == 0) {
            pthread_mutex_lock(&telemetry_mutex);
            telemetry_state.latitude = latitude;
            telemetry_state.longitude = longitude;
            telemetry_state.gps_ready = 1;
            pthread_cond_signal(&telemetry_condition);
            pthread_mutex_unlock(&telemetry_mutex);
        } else {
            sleep(1);
        }
    }

    return NULL;
}

static void *lora_worker(void *argument)
{
    (void)argument;
    uint8_t packet[LORA_PACKET_SIZE];

    for (;;) {
        size_t packet_length = 0;
        if (lora_receive_packet(packet, sizeof(packet), &packet_length) < 0) {
            perror("receive LoRa packet");
            sleep(1);
            continue;
        }

        if (packet_length != sizeof(agro_neck_payload_t)) {
            fprintf(stderr, "Expected %zu-byte LoRa payload, received %zu bytes\n",
                    sizeof(agro_neck_payload_t), packet_length);
            continue;
        }

        agro_neck_payload_t collar_data;
        memcpy(&collar_data, packet, sizeof(collar_data));

         printf("[LoRa] Received %zu-byte packet: COLLAR-%02u, temperature=%.2f C, "
             "latitude=%.6f, longitude=%.6f\n",
             packet_length,
             (unsigned)collar_data.id_collar,
             collar_data.temperatura,
             collar_data.latitud / 1000000.0,
             collar_data.longitud / 1000000.0);

        uint16_t dropped_collar_id = 0;
        int dropped_oldest = 0;
        pthread_mutex_lock(&telemetry_mutex);
        if (telemetry_state.collar_queue_count == COLLAR_QUEUE_CAPACITY) {
            dropped_collar_id = telemetry_state.collar_queue[
                telemetry_state.collar_queue_head].id_collar;
            dropped_oldest = 1;
            telemetry_state.collar_queue_head =
                (telemetry_state.collar_queue_head + 1) % COLLAR_QUEUE_CAPACITY;
            telemetry_state.collar_queue_count--;
        }

        size_t queue_tail = (telemetry_state.collar_queue_head +
                             telemetry_state.collar_queue_count) % COLLAR_QUEUE_CAPACITY;
        telemetry_state.collar_queue[queue_tail] = collar_data;
        telemetry_state.collar_queue_count++;
        pthread_cond_signal(&telemetry_condition);
        pthread_mutex_unlock(&telemetry_mutex);

        if (dropped_oldest) {
            fprintf(stderr, "[LoRa] Queue full; dropped oldest packet for COLLAR-%02u\n",
                    (unsigned)dropped_collar_id);
        }
    }

    return NULL;
}
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

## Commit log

2026-06-03 feat(solaria): proyecto inicial de KiCad de placa de alimentación solar
    esquemático, pcb y modelo 3d de la placa
    [sistemasolar.kicad_pcb, sistemasolar.kicad_sch]
2026-06-16 added hardware directory with PCB developed until 15/6
    [SHIELD_LORA.kicad_pcb, SHIELD_LORA.kicad_sch, sistemasolar.kicad_pcb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]
2026-07-24 feat: reestructuración y actualización general del repositorio
    [AgroBot.kicad_pcb, AgroBot.kicad_sch, AgroBot.step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]
2026-08-17 `feat!: reestructurar el código completo con nuevas implementaciones de alimentación, mpu/mlx y wom/deep sleep`
2026-08-17 docs: actualiza formato de imagenes del README
    Updated image file extensions from .PNG to .png for consistency.
2026-08-20 Nueva version del sitio web con cambios de estilo
2026-08-28 fix: funciones del gps
    [main.c, mpumlx.c, neo6m.c]
2026-08-28 fix: actualizaciones finales
    [partitions.csv]
2026-09-08 feat: añadido de hardware, docs y firmware de ultima version
    [Adapter.kicad_pcb, Adapter.kicad_sch, Solaria.kicad_pcb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]
2026-09-16 chore: delete heartbeat and battery level functions
2026-09-27 docs: actualizo carpeta de campo y renombro anteproyecto
2026-09-27 docs: añado presentacion para ONIET!
2026-09-27 docs: actualizacion de readme
2026-09-27 refactor: remuevo redundancias de hardware
    [SHIELD_LORA.kicad_pcb, SHIELD_LORA.kicad_sch, sistemasolar.kicad_pcb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]
2026-09-30 Squashed 'firmware/AgroBot/' changes from d82568f..70a54bf
    70a54bf Merge pull request #1 from heyboiiiii/development
    06264ae fix(WebSocket): Data is shown in the maps as before.
    a6db6e2 refactor: Changed constinuosly fetch of /api/animals to get animals data to WebSocket conn.
    f0f9257 Refacto:trying to implement ws to send animal data
    0daa007 feaure(pages):Created history page for animals and page of information for yards data.
    git-subtree-dir: firmware/AgroBot
    git-subtree-split: 70a54bf12aaa148d2f3556fab46dd27d4aa0662f
    [main.c]
2026-09-30 Añado funcion para lectura del AgroNeck
2026-09-30 refactor: comento lora temporalmente para comprobar
2026-09-30 refactor: fuerzo cambio de mosfets para verificar funcionamiento
2026-09-30 Corrijo codigo para recepcion de datos de los AgroNeck
2026-09-30 refactor: inicio de lora + modificacion de funciones lora
2026-09-30 Arreglo bytes para envio de información del Lora para la recepcion correcta
    [lora.c, main.c]
2026-09-30 Agrego receptor de Lora de la Raspberry Pi mediante un archivo unico lora_receiver.c
2026-09-30 refactor: actualizo estructuras de lora, mpu6050 y contador
2026-10-01 Elimino sección de ESP-IDF añadida erroneamente
2026-10-01 Meto funcion lora_init en el main.c del Agroneck para arrancar el LoRa
2026-10-01 Cambio funcion para compatibilizarlo con websocket en el front-end.
2026-10-01 Añado guía para arrancar todo el sistema del AgroBot desde cero
2026-10-01 refactor: pruebo lora para comprobar envio de paquete
2026-10-01 style: correccion de comentarios
2026-10-02 Pruebo más cambios en el código del LoRa
2026-10-02 refactor: modificaciones en el lora
2026-10-02 Ultimos arreglos de transmisión LoRa
    [lora.c, lora_receiver.c, main.c]
2026-10-02 fix: remuevo lora init duplicado
    [main.c]
2026-10-02 refactor: volvemos a un funcionamiento correcto y switch de mosfets invertido
    [main.c]
2026-10-05 docs: añado presentacion de first plan realizada
2026-10-05 docs: actualizo readme de hardware
2026-10-05 docs: actualizo readme de mechanical
2026-10-06 fix: eliminado de pequeños detalles
    [main.c]
2026-10-06 Test de cambios hechos por della
2026-10-06 Añado cambios para arreglar errores de github
    [lora.h]
2026-10-06 Cambios en el server
2026-10-08 refactor: pruebas sin WOM y cambio de constante
2026-10-08 fix: elimino signos que no permitian buildear
    [main.c]
2026-10-08 refactor: amplio tiempo de switcheo y modifico temperatura del mlx
2026-10-09 Arreglo coordenadas recibidas por el GPS
    [lora_receiver.c]
2026-10-09 Añado simulador de LoRa para pruebas de GPS hardcodeado
2026-10-27 Cambio de funcionamiento
2026-11-05 Fix: trying to fix LoRa Disconnection in mosfet switching.
2026-11-05 fix: invierto switch para verificación
2026-11-05 refactor: implementacion de reinit y prueba de lora
2026-11-05 refactor: modifico registros de lora a 433 y ajustes en main
2026-11-06 refactor: modifico firmware de mosfets
2026-11-06 chore: agrego codigo para probar mosfets
